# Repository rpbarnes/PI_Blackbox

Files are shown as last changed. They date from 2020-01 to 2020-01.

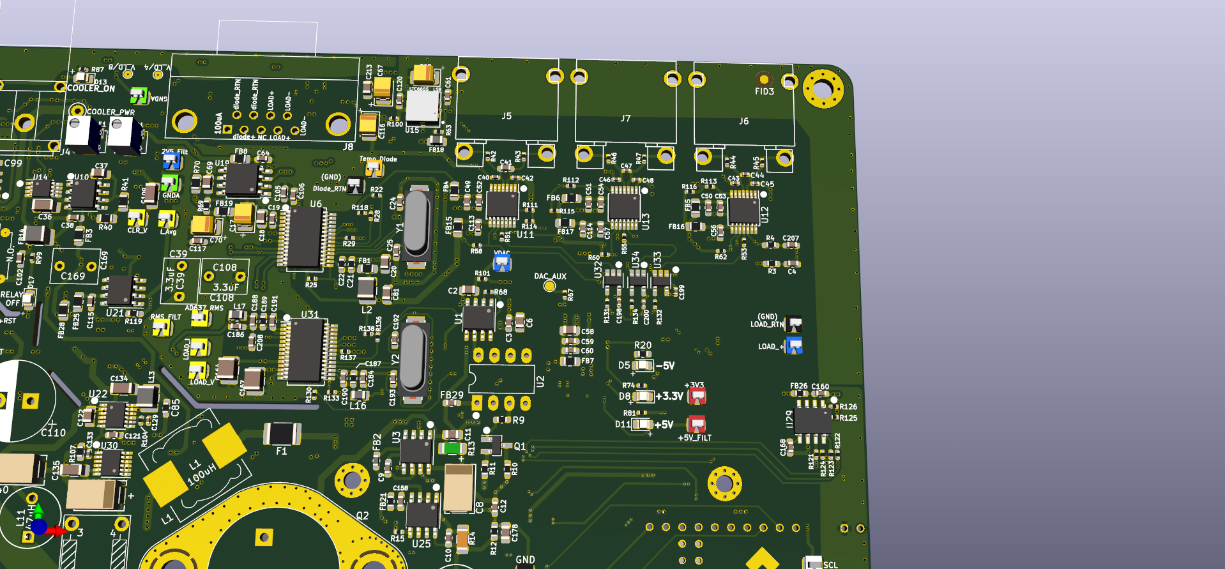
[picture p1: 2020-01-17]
PCB/FAB_Files/Assembled_Pics/top004.png

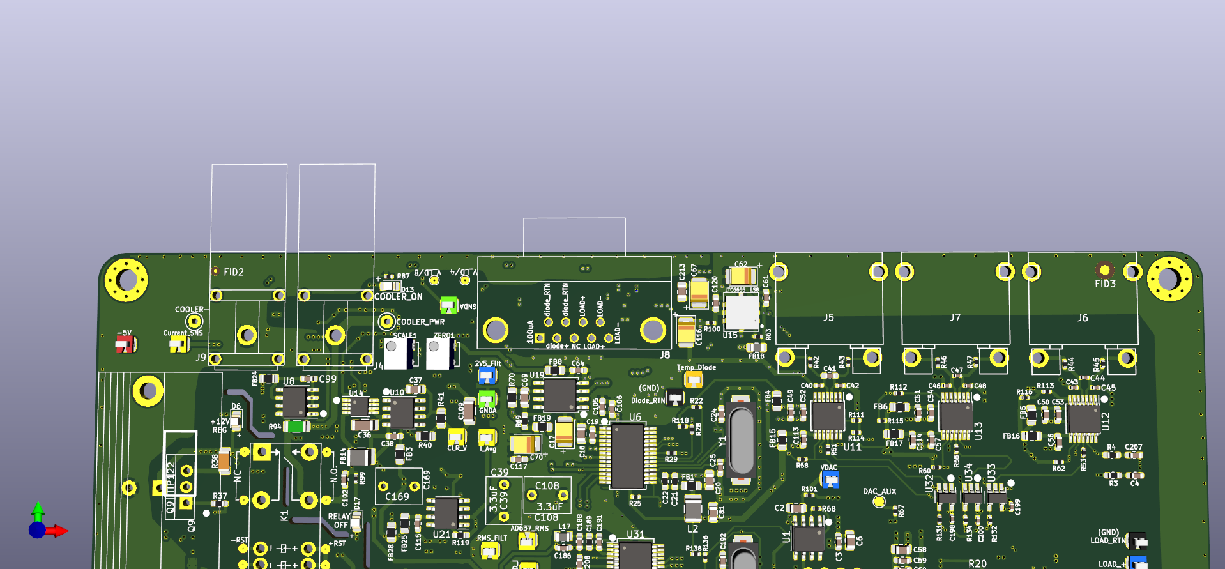
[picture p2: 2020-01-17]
PCB/FAB_Files/Assembled_Pics/top007.png

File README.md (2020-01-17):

# PI_Blackbox
Contains firmware for Raspberry Pi datalogging 
Some code I've written so far.... (not necessarily to be used in final project, but this is a good repository for sharing working code)
  - `GUI/`
      contains bare bones code for C/GTK based GUI to display on HDMI screen

  - `InfluxDB/`
      working code to store metrics to remote database

  - `PI_Firmware/`
      code that runs on PI_DAQ board that synchronously takes data samples
      
  - `Sockets/`
      sample code for sending text packets between two computers over socket connection
      
  - `Recipe/`
      crude version to run stepped loads over defined time intervals on the PI_DAQ
      
  - `PCB/`
      PCB Fabrication files and Kicad project files. Some of Kicad libraries used might not be present here

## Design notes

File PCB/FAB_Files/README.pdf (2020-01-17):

BOARD PACKAGE DOCUMENTS

FOLDERS:

Assembled_Pics/
3D renders of what assembled, finished board should appear as

Assembly_Drawings/
Location of components on top and bottom of board. Drawings include both top and bottom of board, and identified by reference designator and component value

BOM/
Bill of Materials of components to be installed on board. Two BOMs, one is sorted by reference designator, one is by component to aid in purchasing

DrillFiles/
Plated and non plated holes in separate files

Gerbers/
F.Cu | Top copper
In1.Cu | Inner copper layer #1
In2.Cu | Inner copper layer #2
In3.Cu | Inner copper layer #3
In4.Cu | Inner copper layer #4
B.Cu | Bottom copper
B.Adhes | Bottom Adhesive for SMD components
F.Paste | Top solder paste stencil
B.Paste | Bottom solder paste stencil
F.SilkS | Top silk screen
B.SilkS | Bottom silk screen
F.Mask | Top solder mask
B.Mask | Bottom solder mask
Edge Cuts | Board outline milling

Pick-n-Place_Files/
component position files, top and bottom of board

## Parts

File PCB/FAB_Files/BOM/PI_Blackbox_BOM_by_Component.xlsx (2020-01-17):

Description | Manufacturer | Digikey PN | MFR PN | Price EA | QTY | Reference Designators Populated Into
50V Ceramic .1uF X7R 0603 | Samsung | 1276-1000-1-ND |  | 0.1 | 57 | C3 | C5 | C9 | C10 | C11 | C12 | C14 | C19 | C21 | C22 | C38 | C41 | C52 | C53 | C54 | C56 | C57 | C59 | C61 | C64 | C68 | C72 | C77 | C78 | C83 | C85 | C90 | C99 | C102 | C105 | C106 | C115 | C117 | C120 | C157 | C158 | C160 | C166 | C168 | C171 | C172 | C173 | C183 | C186 | C188 | C190 | C191 | C194 | C195 | C196
CAP CER 1UF 25V X7R 0805 | Kemet | 399-8004-1-ND |  | 0.15 | 33 | C6 | C7 | C15 | C18 | C20 | C49 | C50 | C51 | C55 | C58 | C66 | C69 | C73 | C81 | C88 | C89 | C103 | C104 | C112 | C113 | C114 | C118 | C119 | C121 | C128 | C141 | C143 | C149 | C174 | C175 | C176 | C178 | C179
CAP TANT 47UF 10% 35V 2917 T495X | Kemet | 399-3905-1-ND | T495X476K035ATE300 | 2.41 | 12 | C8 | C71 | C87 | C95 | C126 | C131 | C136 | C140 | C148 | C151 | C152 | C156
1uF Film 16VDC | Cornell Dubilier | 338-2778-1-ND | FCA1210C105M-G2 | 0.94 | 9 | C13 | C91 | C96 | C97 | C159 | C163 | C164 | C167 | C170
CAP CER 1000PF 16V X7R 0402 | Kemet | 399-1032-1-ND | C0402C102K5RACTU | 0.1 | 3 | C16 | C35 | C177
CAP TANT 4.7UF 10% 35V 1411 | Kemet | 399-10431-1-ND | T491B475K035AT | 0.95 | 7 | C17 | C62 | C67 | C70 | C116 | C180 | C181
CAP CER 1UF 25V X7R 0603 | Kemet | 399-7376-1-ND | C0603C105K3RACTU | 0.3 | 8 | C23 | C98 | C161 | C182 | C184 | C187 | C189 | C208
20pF, 50V, C0G | Murata | 490-1410-1-ND | GRM1885C1H200JA01D | 0.1 | 4 | C24 | C25 | C192 | C193
CAP CER 10UF 50V X7R 1206 | Samsung | 1276-6767-1-ND | CL31B106KBHNNNE | 0.4 | 30 | C29 | C34 | C36 | C74 | C75 | C76 | C84 | C92 | C93 | C100 | C101 | C107 | C109 | C123 | C124 | C125 | C127 | C130 | C132 | C134 | C135 | C138 | C142 | C144 | C145 | C146 | C153 | C154 | C212 | C214
CAP CER 10UF 16V X7R 0805 | Samsung | 1276-6472-1-ND | CL21B106KOQNNNG | 0.3 | 8 | C37 | C111 | C122 | C165 | C209 | C210 | C211 | C213
CAP FILM 1UF 10% 63VDC RADIAL | Kemet | 399-11451-1-ND | MMK5105K63J04L16.5TR18 | 0.95 | 1 | C30
CAP POLY 6000UF 35V T/H | United Chemi Con | 565-4353-ND | ELBK350ELL602AMN3S | 3.93 | 2 | C31 | C32
0603 .01UF 10% 50V X7R | Kemet | 399-C0603C103K5RAC7081CT-ND | C0603C103K5RAC7081 | 0.11 | 4 | C33 | C60 | C63 | C65
CAP FILM 3.3UF 20% 50VDC RAD | WIMA | 1928-1627-ND | MKS2B043301H00MSSD | 1.15 | 3 | C39 | C108 | C169
CAP ALUM 1000UF 20% 35V RADIAL | Panasonic | P15382CT-ND | EEU-FR1V102B | 1.03 | 3 | C94 | C110 | C147
CAP CER 10000PF 50V X7R 0402 | Kemet | 399-7760-1-ND | C0402C103M5RACTU | 0.1 | 6 | C40 | C42 | C43 | C45 | C46 | C48
CAP CER 0.47UF 10V X7R 0402 | Taiyo Tuden | 587-5912-1-ND | LMK105B7474KV-F | 0.25 | 2 | C129 | C133
CAP CER 100UF 16V X5R 1210 | Kemet | 399-11270-1-ND | C1210C107M4PAC7800 | 3.23 | 2 | C139 | C150
CAP CER 0.1UF 25V X7R 0402 | Murata | 490-13341-1-ND | GRM155R71E104ME14D | 0.1 | 6 | C44 | C47 | C162 | C198 | C199 | C200
DIODE SCHOTTKY 40V 1A SOD123 | Diodes Incorporated | 1N5819HW-FDICT-ND | 1N5819HW-7-F | 0.44 | 2 | D1 | D3
TVS DIODE 18V 29.2V DO214AB | Littelfuse | SMDJ18CACT-ND | SMDJ18CA | 1.17 | 1 | D2
DIODE GEN PURP 100V 300MA SOD123 | Diodes Incorporated | 1N4148W-FDICT-ND | 1N4148W-7-F | 0.16 | 2 | D4 | D12
LED GREEN CLEAR SMD | Litte-On | 160-1426-1-ND | LTST-C171KGKT | 0.29 | 6 | D5 | D8 | D10 | D11 | D13 | D16
LED YELLOW CLEAR SMD | Litte-On | 160-1416-1-ND | LTST-C170KSKT | 0.33 | 2 | D6 | D9
LED ORANGE CLEAR SMD | Lite-On | 160-1419-1-ND | LTST-C171AKT | 0.31 | 1 | D14
LED RED CLEAR SMD | Lite-On | 160-1427-1-ND | LTST-C171KRKT | 0.29 | 1 | D17
HEATSINK 18X50MM 2-CLIP TO-220 | Wakefield-Vette | 345-1491-ND | OMNI-220-18-50-2C | 7.43 | 1 | HS1
CAP CER 0.1UF 50V Z5U 1206 | Kemet | 399-1258-1-ND | C1206C104Z5UACTU | 0.19 | 2 | C26 | C155
CAP CER 0.1UF 25V X7R 0805 | Kemet | 399-8000-1-ND | C0805C104M3RACTU | 0.1 | 2 | C79 | C185
FIXED IND 10UH 850MA 300 MOHM | Wurth | 732-4516-1-ND | 74479887310A | 1.2 | 5 | L1 | L2 | L7 | L9 | L13
TRANS NPN 40V 0.6A SOT23 | Micro Commercial | MMBT2222ATPMSCT-ND | MMBT2222A-TP | 0.1 | 3 | Q1 | Q4 | Q7
FIXED IND 10UH 500MA 300 MOHM | TDK | 445-6762-1-ND | MLZ2012N100LT000 | 0.14 | 2 | L16 | L17
PC TEST POINT, WHITE, SMT | Keystone | 36-5192CT-ND | 5192TR | 0.44 | 9 | TP3 | TP5 | TP6 | TP7 | TP8 | TP9 | TP10 | TP12 | TP50
PC TEST POINT, BLACK, SMT | Keystone | 36-5191CT-ND | 5191TR | 0.44 | 5 | TP11 | TP32 | TP38 | TP40 | TP43
PC TEST POINT, PURPLE, SMT | Keystone | 36-5199CT-ND | 5199TR | 0.44 | 3 | TP4 | TP14 | TP15
PC TEST POINT, YELLOW, SMT | Keystone | 36-5194CT-ND | 5194TR | 0.44 | 7 | TP17 | TP18 | TP22 | TP31 | TP45 | TP46 | TP47
PC TEST POINT, RED, SMT | Keystone | 36-5190CT-ND | 5190TR | 0.44 | 7 | TP16 | TP19 | TP27 | TP28 | TP29 | TP35 | TP44
PC TEST POINT, BLUE, SMT | Keystone | 36-5197CT-ND | 5197TR | 0.44 | 3 | TP13 | TP23 | TP24
PC TEST POINT, GREEN, SMT | Keystone | 36-5196CT-ND | 5196TR | 0.44 | 2 | TP26 | TP48
PC TEST POINT, ORANGE, SMT | Keystone | 36-5193CT-ND | 5193TR | 0.44 | 1 | TP33
CAP CER 10000PF 50V X7R 1206 | Yageo | 311-1174-1-ND | CC1206KRX7R9BB103 | 0.24 | 1 | C27
CAP ALUM 560UF 20% 35V RADIAL | Nichicon | 493-15313-ND |  | 0.74 | 2 | C28 | C137
FIXED IND 10UH 500MA | TDK | 445-6762-1-ND | MLZ2012N100LT000 | 0.14 | 19 | FB1 | FB3 | FB4 | FB5 | FB6 | FB7 | FB8 | FB9 | FB12 | FB15 | FB16 | FB17 | FB18 | FB19 | FB20 | FB24 | FB25 | FB28 | FB30
FIXED IND 22UH 230MA | Taiyo Yuden | 587-1721-1-ND | CBMF1608T220K | 0.27 | 9 | FB2 | FB11 | FB21 | FB22 | FB23 | FB26 | FB27 | FB29 | FB31
FERRITE BEAD 1 KOHM 1210 1LN | Taiyo Yuden | 587-1753-1-ND | FBMH3225HM102NT | 0.44 | 4 | FB10 | FB13 | FB14 | FB32
FIXED IND 2.2UH 30MA | TDK | 445-15690-1-ND | MLF1005G2R2KT000 | 0.28 | 3 | FB33 | FB34 | FB35
CAP CER 12PF 50V C0G/NP0 0603 | Kemet | 399-1050-1-ND | C0603C120J5GACTU | 0.1 | 1 | C80
CAP CER 3000PF 50V C0G/NP0 0603 | Murata | 490-6384-1-ND | GRM1885C1H302JA01D | 0.19 | 1 | C82
CAP CER 680PF 250V C0G/NP0 0603 | Kemet | 399-14994-1-ND | C0603C681JAGAC7867 | 0.11 | 1 | C86
DIODE SCHOTTKY 40V 3A SMA | ON Semiconductor | MBRA340T3GOSCT-ND | MBRA340T3G | 0.48 | 1 | D7
PTC .15A |  | 507-1755-1-ND |  | 0.14 | 1 | F1
PTC RESET FUSE 24V 2A 2920 | Bel Fuse | 507-1749-1-ND | 0ZCF0200AF2C | 0.29 | 2 | F2 | F3
CONN HEADER SMD R/A 2POS 3MM | TE Connectivity | A33212CT-ND |  | 0.99 | 1 | J3
FILTER LC 1UF SMD | Murata | 490-5052-1-ND | BNX022-01L | 6.04 | 1 | L3
TRANS 2PNP 65V 0.1A 6TSOP | Nexperia | 1727-5391-1-ND | BCM856DS | 0.43 | 1 | Q3
MOSFET N/P-CH 30V TSOT23-6 | Diodes Incorporated | DMG6602SVT-7DICT-ND | DMG6602SVT-7 | 0.37 | 1 | Q5
MOSFET P-CH 12V 4.3A SOT-23 | Infineon | IRLML6401PBFCT-ND | IRLML6401TRPBF | 0.37 | 1 | Q6
10K OHM 0.5% 1/16W 0402 | Susumu | RR05P10.0KDCT-ND | RR0510P-103-D | 0.1 | 15 | R5 | R6 | R7 | R25 | R60 | R62 | R64 | R100 | R105 | R110 | R114 | R115 | R116 | R125 | R126
2K OHM 1% 1/16W 0402 100ppm/C | Yageo | 311-2KLRCT-ND | RC0402FR-072KL | 0.1 | 8 | R22 | R31 | R34 | R118 | R123 | R124 | R130 | R138
100 OHM 1% 1/16W 0402 | Yageo | 311-100LRCT-ND | RC0402FR-07100RL | 0.1 | 14 | R1 | R2 | R8 | R17 | R42 | R43 | R44 | R45 | R46 | R47 | R50 | R52 | R68 | R148
10K OHM 0.5% 1/16W 0402 | Susumu | RR05P10.0KDCT-ND | RR0510P-103-D | 0.1 | 18 | R5 | R6 | R7 | R25 | R58 | R60 | R62 | R64 | R100 | R105 | R110 | R114 | R115 | R116 | R125 | R126 | R133 | R147
1K OHM 1% 1/16W 0402 100ppm/C | Yageo | 311-1.00KLRCT-ND | RC0402FR-071KL | 0.1 | 11 | R15 | R16 | R18 | R35 | R39 | R63 | R72 | R81 | R87 | R98 | R99
RES 47 OHM 5% 1/16W 0402 100ppm/C | Stackpole | RMCF0402JT47R0CT-ND | RMCF0402JT47R0 | 0.1 | 29 | R48 | R49 | R51 | R53 | R54 | R55 | R56 | R57 | R59 | R61 | R65 | R66 | R111 | R112 | R113 | R131 | R132 | R134 | R135 | R136 | R137 | R139 | R140 | R141 | R142 | R143 | R144 | R145 | R146
49.9KOHM 0.5% 1/16W 0603 | Susumu | RR08P49.9KDCT-ND | RR0816P-4992-D-68C | 0.11 | 3 | R30 | R32 | R33
20K OHM 0.5% 1/16W 0603 | Susumu | RR08P20.0KDCT-ND | RR0816P-203-D | 0.11 | 2 | R12 | R75
100 OHM 0.5% 1/16W 0603 | Susumu | RR08P100DCT-ND | RR0816P-101-D | 0.11 | 4 | R36 | R37 | R83 | R119
499 OHM 1% 1/10W 0402 100ppm/C | Panasonic | P499LCT-ND | ERJ-2RKF4990X | 0.1 | 3 | R80 | R85 | R86
22 OHM 1% 1/16W 0402 | Yageo | 311-22.0LRCT-ND | RC0402FR-0722RL | 0.1 | 4 | R89 | R91 | R121 | R122
49.9 OHM 1% 1/10W 0402 100ppm/C | Panasonic | P49.9LCT-ND | ERJ-2RKF49R9X | 0.1 | 2 | R67 | R101
RES 0.5 OHM 1% 1/2W 1206 | Vishay Dale | 541-4389-1-ND | RCWE1206R500FKEA | 0.61 | 2 | R38 | R84
300 OHM 0.5% 1/16W 0402 | Susumu | RR05P300DCT-ND | RR0510P-301-D | 0.1 | 2 | R74 | R93
47K OHM 1% 1/10W 0603 | Yageo | 311-47.0KHRCT-ND | RC0603FR-0747KL | 0.1 | 2 | R96 | R97
1M OHM 0.1% 1/10W 0603 25ppm/C | Yageo | YAG4498CT-ND | RT0603BRD071ML | 0.35 | 2 | R106 | R120
200 OHM 1% 1/10W 0603 100ppm/C | Panasonic | P200HCT-ND | ERJ-3EKF2000V | 0.1 | 1 | R9
1K OHM 0.5% 1/16W 0603 | Yageo | RR08P1.0KDCT-ND | RR0816P-102-D | 0.11 | 1 | R10
49.9 OHM 1% 1/10W 0603 | Yageo | 311-49.9HRCT-ND | RC0603FR-0749R9L | 0.1 | 1 | R11
RES SMD 1 OHM 1% 1/2W 1206 | Susumu | RL16R1.0FCT-ND | RL1632R-1R00-F | 0.68 | 1 | R13
0.39 OHM 1% 1/2W 1206 | Vishay Dale | RCWE.39ECT-ND | RCWE1206R390FKEA | 0.61 | 1 | R14
300 OHM 0.5% 1/16W 0603 | Susumu | RR08P300DCT-ND | RR0816P-301-D | 0.11 | 1 | R19
2.2K OHM 0.5% 1/10W 0805 | Susumu | RR12P2.2KDCT-ND | RR1220P-222-D | 0.11 | 1 | R40
200 OHM 0.5% 1/10W 0805 | Susumu | RR12P200DCT-ND | RR1220P-201-D | 0.11 | 1 | R41
10K OHM 1% 1/10W 0603 | Yageo | 311-10.0KHRCT-ND | RC0603FR-0710KL | 0.1 | 1 | R69
RES 20 OHM 5% 1/8W 0805 | Stackpole | RMCF0805JT20R0CT-ND | RMCF0805JT20R0 | 0.1 | 1 | R70
215K OHM 0.1% 1/10W 0603 | Panasonic | P215KDBCT-ND | ERA-3AEB2153V | 0.35 | 1 | R71
36K OHM 0.5% 1/16W 0603 | Susumu | RR08P36.0KDCT-ND | RR0816P-363-D | 0.11 | 1 | R73
2.2K OHM 1% 1/10W 0603 | Yageo | 311-2.20KHRCT-ND | RC0603FR-072K2L | 0.1 | 1 | R76
71.5KOHM 0.1% 1/10W 0603 | Panasonic | P71.5KDBCT-ND | ERA-3AEB7152V | 0.35 | 1 | R77
11K OHM 0.1% 1/10W 0603 | Panasonic | P11KDBCT-ND | ERA-3AEB113V | 0.35 | 1 | R78
750 OHM 0.5% 1/16W 0402 25ppm/C | Susumu | RR05P750DCT-ND | RR0510P-751-D | 0.1 | 1 | R79
750 OHM 0.5% 1/16W 0603 | Susumu | RR08P750DCT-ND | RR0816P-751-D | 0.1 | 1 | R82
THICK FILM RESISTOR | KOA | 2019-RK73H2ETTD20R0FCT-ND | RK73H2ETTD20R0F | 0.2 | 1 | R88
220K OHM 0.1% 1/10W 0603 | Panasonic | P220KDBCT-ND | ERA-3AEB224V | 0.35 | 1 | R90
11.5KOHM 0.1% 1/10W 0603 | Panasonic | P11.5KDBCT-ND | ERA-3AEB1152V | 0.35 | 1 | R92
RES 0.056 OHM 1% 3/4W 1206 | Susumu | 408-1579-1-ND | KRL1632E-M-R056-F-T5 | 0.54 | 1 | R94
2.2K OHM 1% 1/16W 0402 100ppm/C | Yageo | 311-2.20KLRCT-ND | RC0402FR-072K2L | 0.1 | 1 | R95
RES 0.2 OHM 1% 1/2W 1206 | Susumu | RL16R.20FCT-ND | RL1632R-R200-F | 0.65 | 1 | R102
RES SMD 1.5 OHM 1% 1/2W 1206 | Susumu | RL16R1.5FCT-ND | RL1632R-1R50-F | 0.68 | 1 | R103
33.2KOHM 0.1% 1/16W 0402 25ppm/C | Panasonic | P33.2KDCCT-ND | ERA-2AEB3322X | 0.45 | 1 | R104
51K OHM 0.1% 1/10W 0603 | Panasonic | P51KDBCT-ND | ERA-3AEB513V | 0.35 | 1 | R107
4.7K OHM 5% 1/16W 0402 | Yageo | 311-4.7KJRCT-ND | RC0402JR-074K7L | 0.1 | 1 | R108
RES SMD 47 OHM 1% 1/2W 1206 | TE Connectivity | A129227CT-ND | CRGH1206F47R | 0.16 | 1 | R109
1.87KOHM 0.1% 1/10W 0603 | Panasonic | P1.87KDBCT-ND | ERA-3AEB1871V | 0.35 | 1 | R117
47 OHM 0.5% 1/16W 0603 | Susumu | RR08Q47DCT-ND | RR0816Q-470-D | 0.11 | 1 | R127
RES SMD 4.99 OHM 1% 1/8W 0805 | Yageo | 311-4.99CRCT-ND | RC0805FR-074R99L | 0.1 | 1 | R128
RES 0.1 OHM 5% 1/10W 0603 | Panasonic | P.10AHCT-ND | ERJ-3RSJR10V | 0.25 | 1 | R129
TRIMMER 500 OHM 0.25W J LEAD TOP | Bourns | 3214W-501ECT-ND | 3214W-1-501E | 3.24 | 1 | SCALE1
TRIMMER 50K OHM 0.25W J LEAD TOP | Bourns | 3214W-503ECT-ND | 3214W-1-503E | 3.24 | 1 | ZERO1
IC BUF NON-INVERT 5.5V SOT23-5 | Texas Instruments |  | SN74AHC1G125DBVR | 0.32 | 3 | U32 | U33 | U34
IC BUFFER NON-INVERT 6V 14TSSOP | Texas Instruments | 296-26461-1-ND | SN74HC125PWR | 0.36 | 3 | U35 | U36 | U37
IC CONV THERMOCOUPLE 14TSSOP | Maxim Integrated | MAX31856MUD+-ND | MAX31856MUD+ | 6.45 | 3 | U11 | U12 | U13
IC OPAMP ZERO-DRIFT 1 CIRC 8SOIC | Analog Devices | AD8628ARZ-REEL7CT-ND | AD8628ARZ-REEL7 | 2.95 | 5 | U10 | U19 | U21 | U27 | U28
24 Bit Analog to Digital Converter 4, 8 Input 1 Sigma-Delta 28-SSOP | Texas Instruments | 296-25898-1-ND | ADS1256IDBR | 14.87 | 2 | U6 | U31
RES ARRAY 4 RES 10K OHM 8TSSOP | Analog Devices | LT5400BIMS8E-1#PBF-ND | LT5400BIMS8E-1#PBF | 9.31 | 2 | U5 | U14
IC REG LINEAR 0V 500MA 12MSOP | Analog Devices | LT3045EMSE#PBF-ND | LT3045EMSE#PBF | 6.78 | 2 | U22 | U30
IC CURR SENSE 1 CIRCUIT 8SOIC | Analog Devices | AD8417WBRZ-ND | AD8417WBRZ | 3.02 | 3 | U32 | U8 | U25
7.68MHz ±30ppm Crystal 18pF 80 Ohms HC- | TXC Corporation | 887-1047-1-ND | 9C-7.680MAAJ-T | 0.46 | 1 | Y1
IC OPAMP ZERO-DRIFT 1 CIRC 8SOIC | Analog Devices | LTC2057IS8#TRPBF | LTC2057IS8#TRPBFCT-ND | 2.99 | 1 | U1
IC OPAMP DIFF 1 CIRCUIT 8SOIC | Analog Devices | AD8278BRZ | AD8278BRZ-ND | 4 | 1 | U4
IC REG LIN POS ADJ 500MA 12MSOP | Analog Devices | LT3065IMSE#PBF | LT3065IMSE#PBF-ND | 5.1 | 1 | U7
IC CURR SOURCE/SINK MIRROR 8SOIC | Texas Instruments | REF200AU | 296-44855-5-ND | 8.91 | 1 | U9
IC VREF SERIES 0.05% 8CLCC | Analog Devices | LTC6655CHLS8-2.5#PBF | LTC6655CHLS8-2.5#PBF-ND | 11.65 | 1 | U15
IC DAC 16BIT V-OUT 8VSSOP | Texas Instruments | DAC8552IDGKR | 296-46082-1-ND | 7.25 | 1 | U16
IC ANALOG SWITCH 8MSOP | Vishay Siliconix | DG419LEDQ-T1-GE3 | DG419LEDQ-T1-GE3CT-ND | 1.36 | 1 | U17
IC REG BCK SPLIT RAIL ADJ 8SOPWR | Texas Instruments | TPS54360DDA | 296-35014-ND | 5.71 | 1 | U18
SENSOR DIGITAL -55C-150C 8SOIC | Analog Devices | ADT7410TRZ-REEL7 | ADT7410TRZ-REEL7CT-ND | 3.93 | 1 | U20
IC REG CHARGE PUMP INV 8SOIC | Analog Devices | LT1054LCS8#PBF | LT1054LCS8#PBF-ND | 4.85 | 1 | U23
IC RMS TO DC CONVERTER 16SOIC | Analog Devices | AD637JRZ | AD637JRZ-ND | 24.07 | 1 | U24
IC REG LIN POS ADJ 3A 8SO PWRPAD | Texas Instruments | TPS7A7002DDA | 296-39506-5-ND | 2.8 | 1 | U26
IC RTC CLK/CALENDAR I2C 8-SOIC | Maxim Integrated | DS3231MZ+ | DS3231MZ+-ND | 7.89 | 1 | U29
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

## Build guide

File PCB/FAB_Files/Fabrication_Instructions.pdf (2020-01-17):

FABRICATION INSTRUCTIONS

NOTE: ALL DIMENSIONS IN BOARD DOCUMENTS ARE IN MILLIMETERS

BOARD DIMENSIONS: | 125.776 MM x 175.236 MM
NUMBER OF LAYERS: | 6
1. MATERIAL: LAMINATED EPOXY GLASS FR-4, NOMINAL 1.6 MM, COLOR NATURAL NOM 2 OZ COPPER WEIGHT. THICKNESS 1.8 MM MAX AFTER PLATING
2. SOLDERMASK OVER BARE COPPER ON TOP AND BOTTOM WITH MATERIAL PER ANSI/ IPC-SM-840, COLOR SHALL BE GREEN
3. HOLES.
A. PLATING IN HOLES SHALL BE CONTINUOUS ELECTROLYTIC COPPER WITH .025 MM MINIMUM BARREL THICKNESS
B. MINIMUM HOLE SIZE: 0.2 MM
C. SEE DRILL CHART FOR FINISHED HOLE SIZE AND TOLERANCE
D. HOLE SIZES ARE SPECIFIED AS FINAL DIMENSIONS AFTER PLATING
4. SEE SEPARATE DRILL FILE FOR HOLE LOCATIONS
5. SURFACE FINISH. ENIG PLATING PER CURRENT REVISION OF IPC 4552
6. APPLY SILKSCREEN TO TOP AND BOTTOM SIDE OF BOARD WITH WHITE EPOXY, NON-CONDUCTIVE INK
7. DIMENSIONAL TOLERANCES ARE: .XX=+/- .01; .XXX=+/-.005
8. OUTLINE DEFINED IN SEPARATE GERBER FILE “Pi_Blackbox-Edge_Cuts.gbr”
9. NO CONTROLLED IMPEDANCE
10. DESIGN GEOMETRY MINIMUM FEATURE SIZES:
TRACE WIDTH; | 0.25 MM
TRACE-TO-TRACE; TRACE-TO-PAD | 0.19 MM
HOLE-TO-HOLE | 0.254 MM
PAD-TO-PAD | 0.19 MM
MIN HOLE SIZE | 0.2 MM

LAYER STACKUP

SOLDERMASK | Pi_Blackbox-F_Mask.gbr
SILKSCREEN | Pi_Blackbox-F_SilkS.gbr
TOP COPPER, 2 oz | Pi_Blackbox-F_Cu.gbr
DIELECTRIC
INNER COPPER LAYER #1, 1 oz | Pi_Blackbox-In1_Cu.gbr
DIELECTRIC
INNER COPPER LAYER #2 1 oz | Pi_Blackbox-In2_Cu.gbr
DIELECTRIC
INNER COPPER LAYER #3 1 oz | Pi_Blackbox-In3_Cu.gbr
DIELECTRIC
INNER COPPER LAYER #4 1 oz | Pi_Blackbox-In4_Cu.gbr
DIELECTRIC
BOTTOM COPPER 2 oz | Pi_Blackbox-B_Cu.gbr
SOLDER MASK | Pi_Blackbox-B_Mask.gbr
SILKSCREEN | Pi_Blackbox-B_SilkS.gbr

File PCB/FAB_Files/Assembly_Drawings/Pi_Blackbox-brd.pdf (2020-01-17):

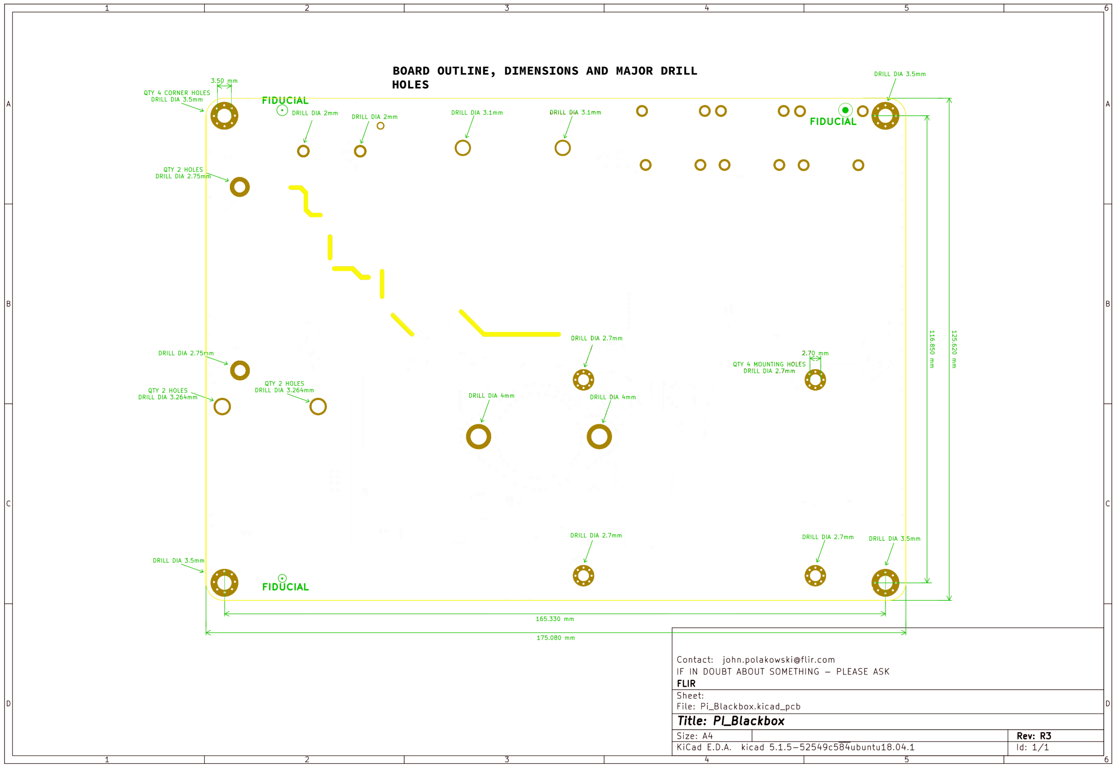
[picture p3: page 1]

BOARD OUTLINE, DIMENSIONS AND MAJOR DRILL HOLES

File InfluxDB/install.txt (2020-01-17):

wget -qO- https://repos.influxdata.com/influxdb.key | sudo tee /etc/apt/sources.list.d/influxdb.list test $VERSION_ID = "8" && echo "deb https://repos.influxdata.com/debian jessie stable" | sudo tee /etc/apt/sources.list.d/influxdb.list test $VERSION_ID = "9" && echo "deb https://repos.influxdata.com/debian stretch stable" | sudo tee /etc/apt/sources.list.d/influxdb.list 

sudo apt-get update && sudo apt-get install influxdb 
sudo service influxdb start 

#verify influxdb is running with the following command. 
sudo service influxdb status

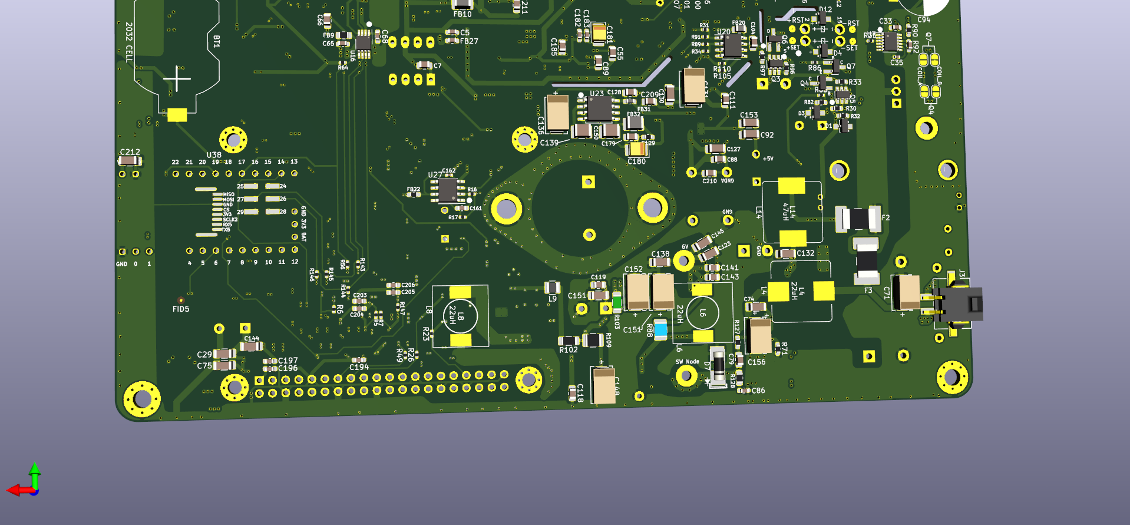
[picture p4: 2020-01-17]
PCB/FAB_Files/Assembled_Pics/bottom006.png

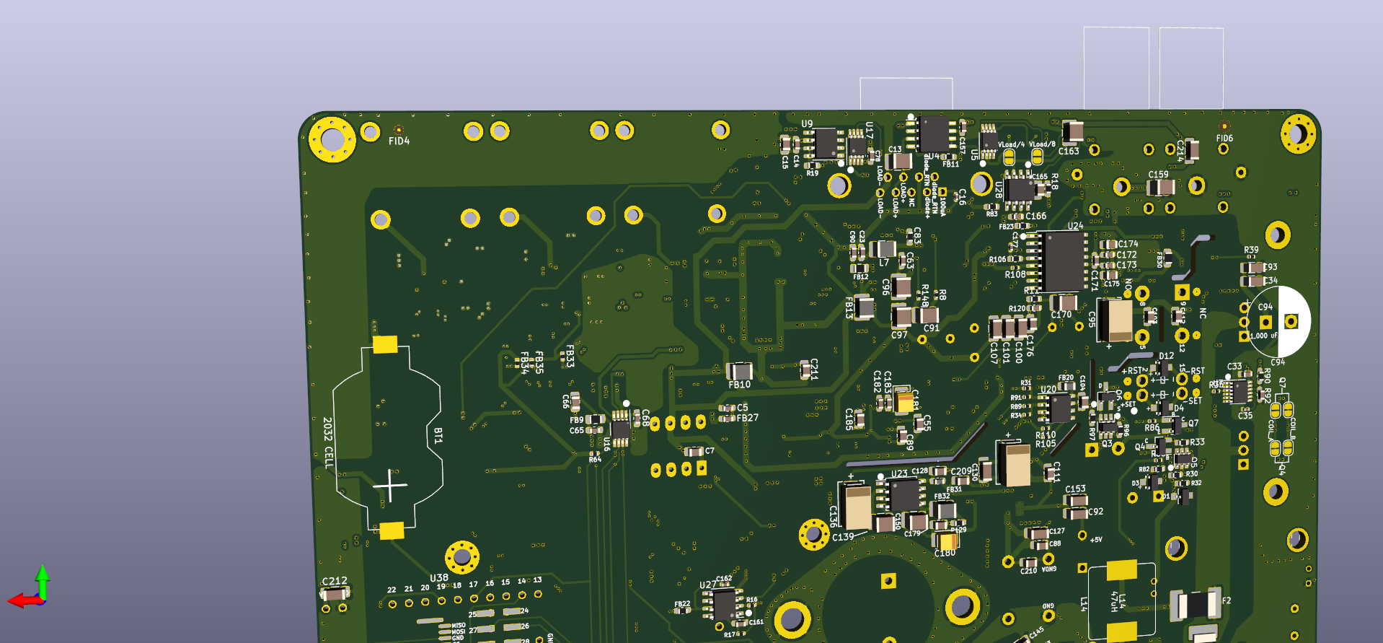
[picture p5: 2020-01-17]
PCB/FAB_Files/Assembled_Pics/bottom005.png

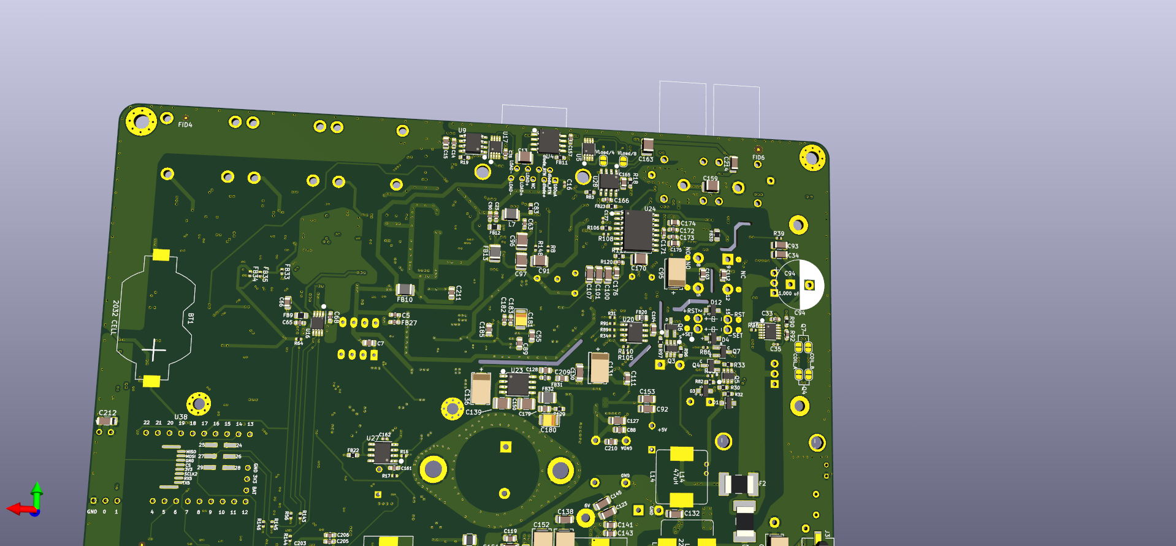
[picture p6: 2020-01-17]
PCB/FAB_Files/Assembled_Pics/bottom004.png

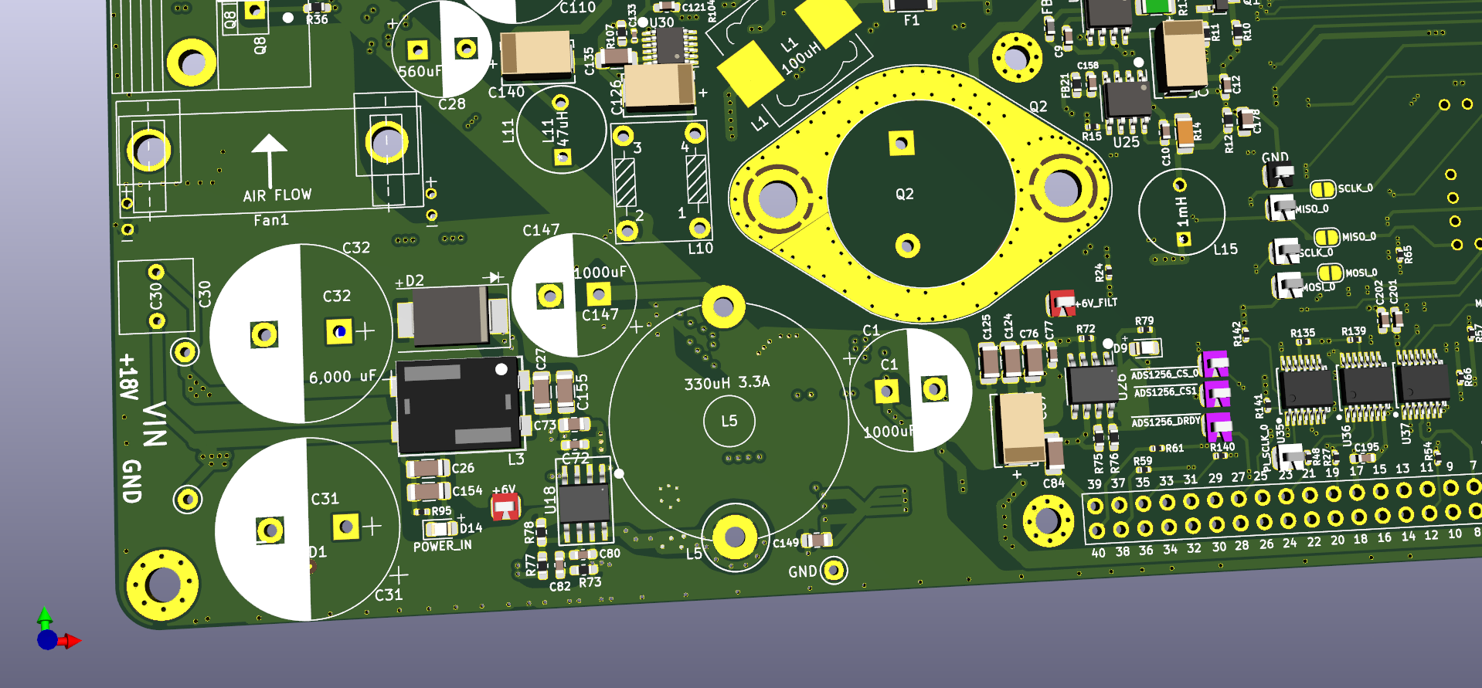
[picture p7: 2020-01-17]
PCB/FAB_Files/Assembled_Pics/top002.png

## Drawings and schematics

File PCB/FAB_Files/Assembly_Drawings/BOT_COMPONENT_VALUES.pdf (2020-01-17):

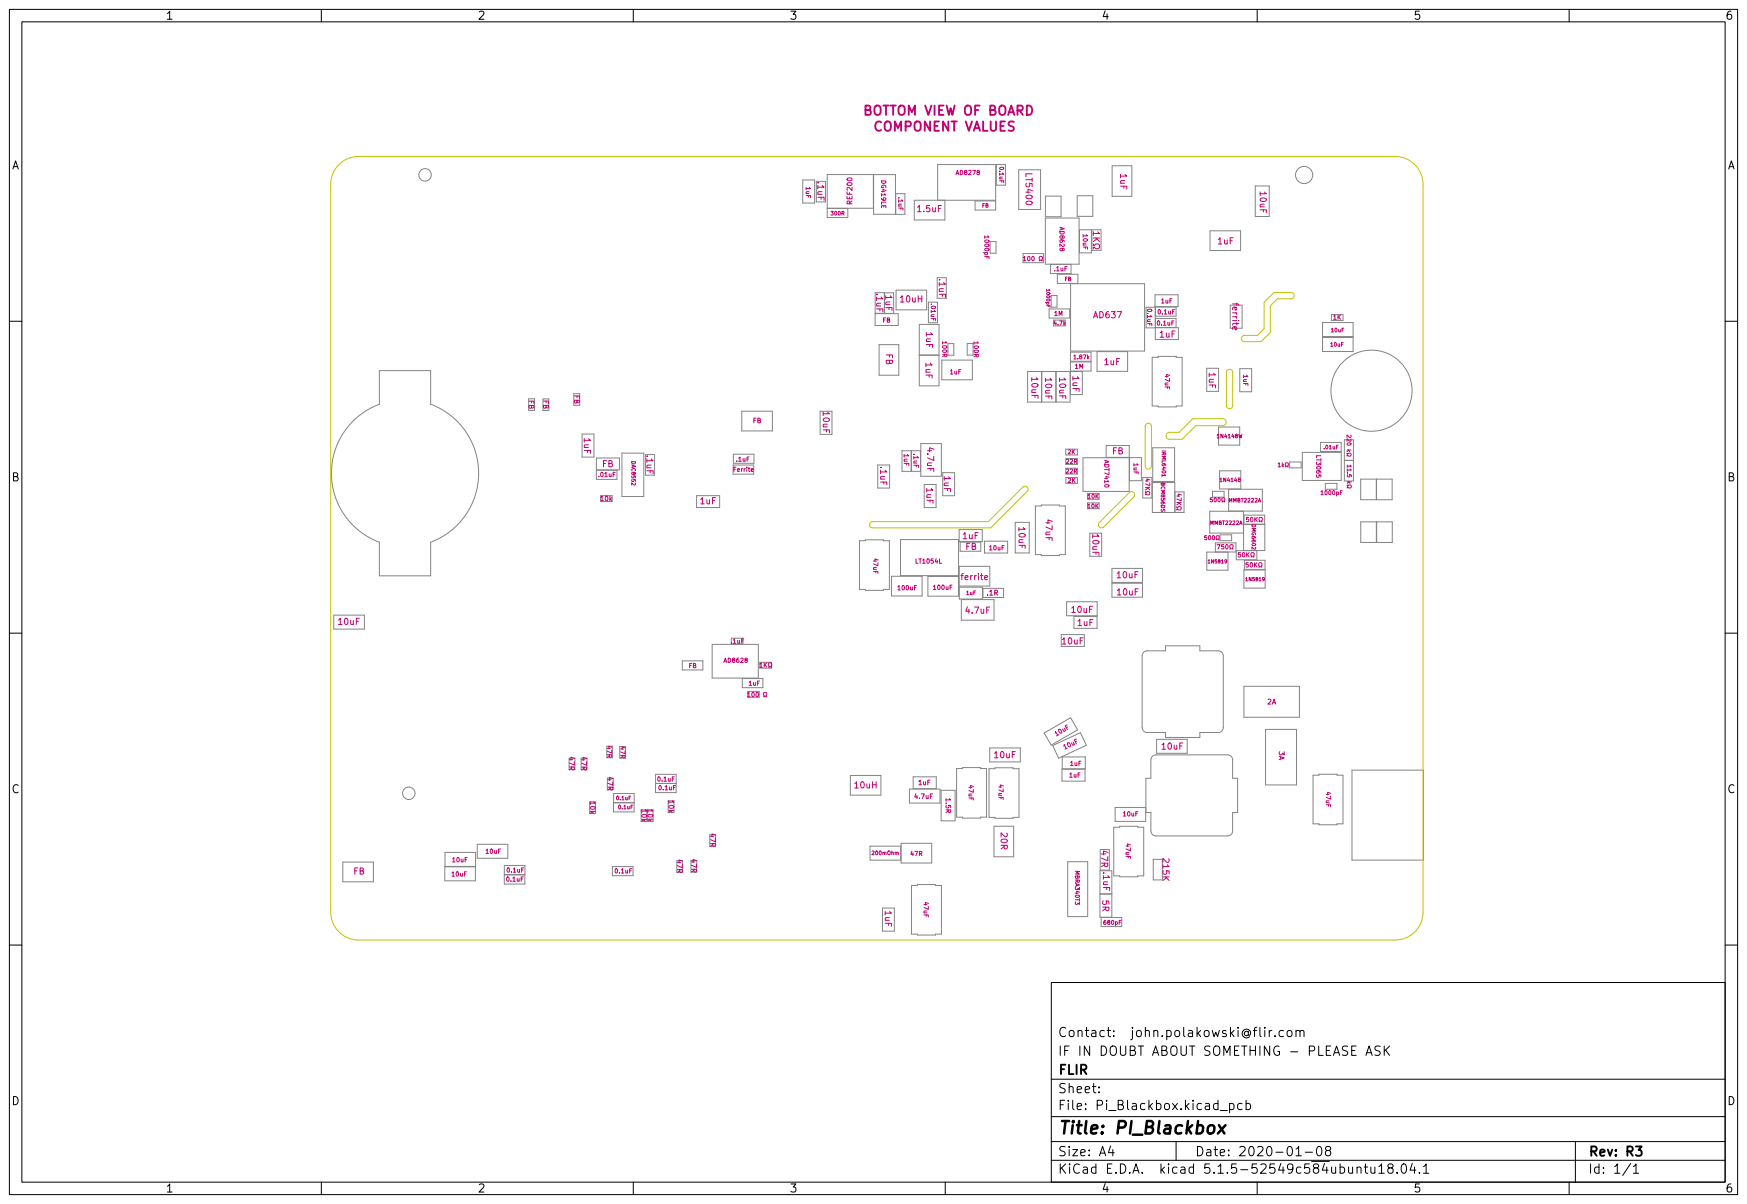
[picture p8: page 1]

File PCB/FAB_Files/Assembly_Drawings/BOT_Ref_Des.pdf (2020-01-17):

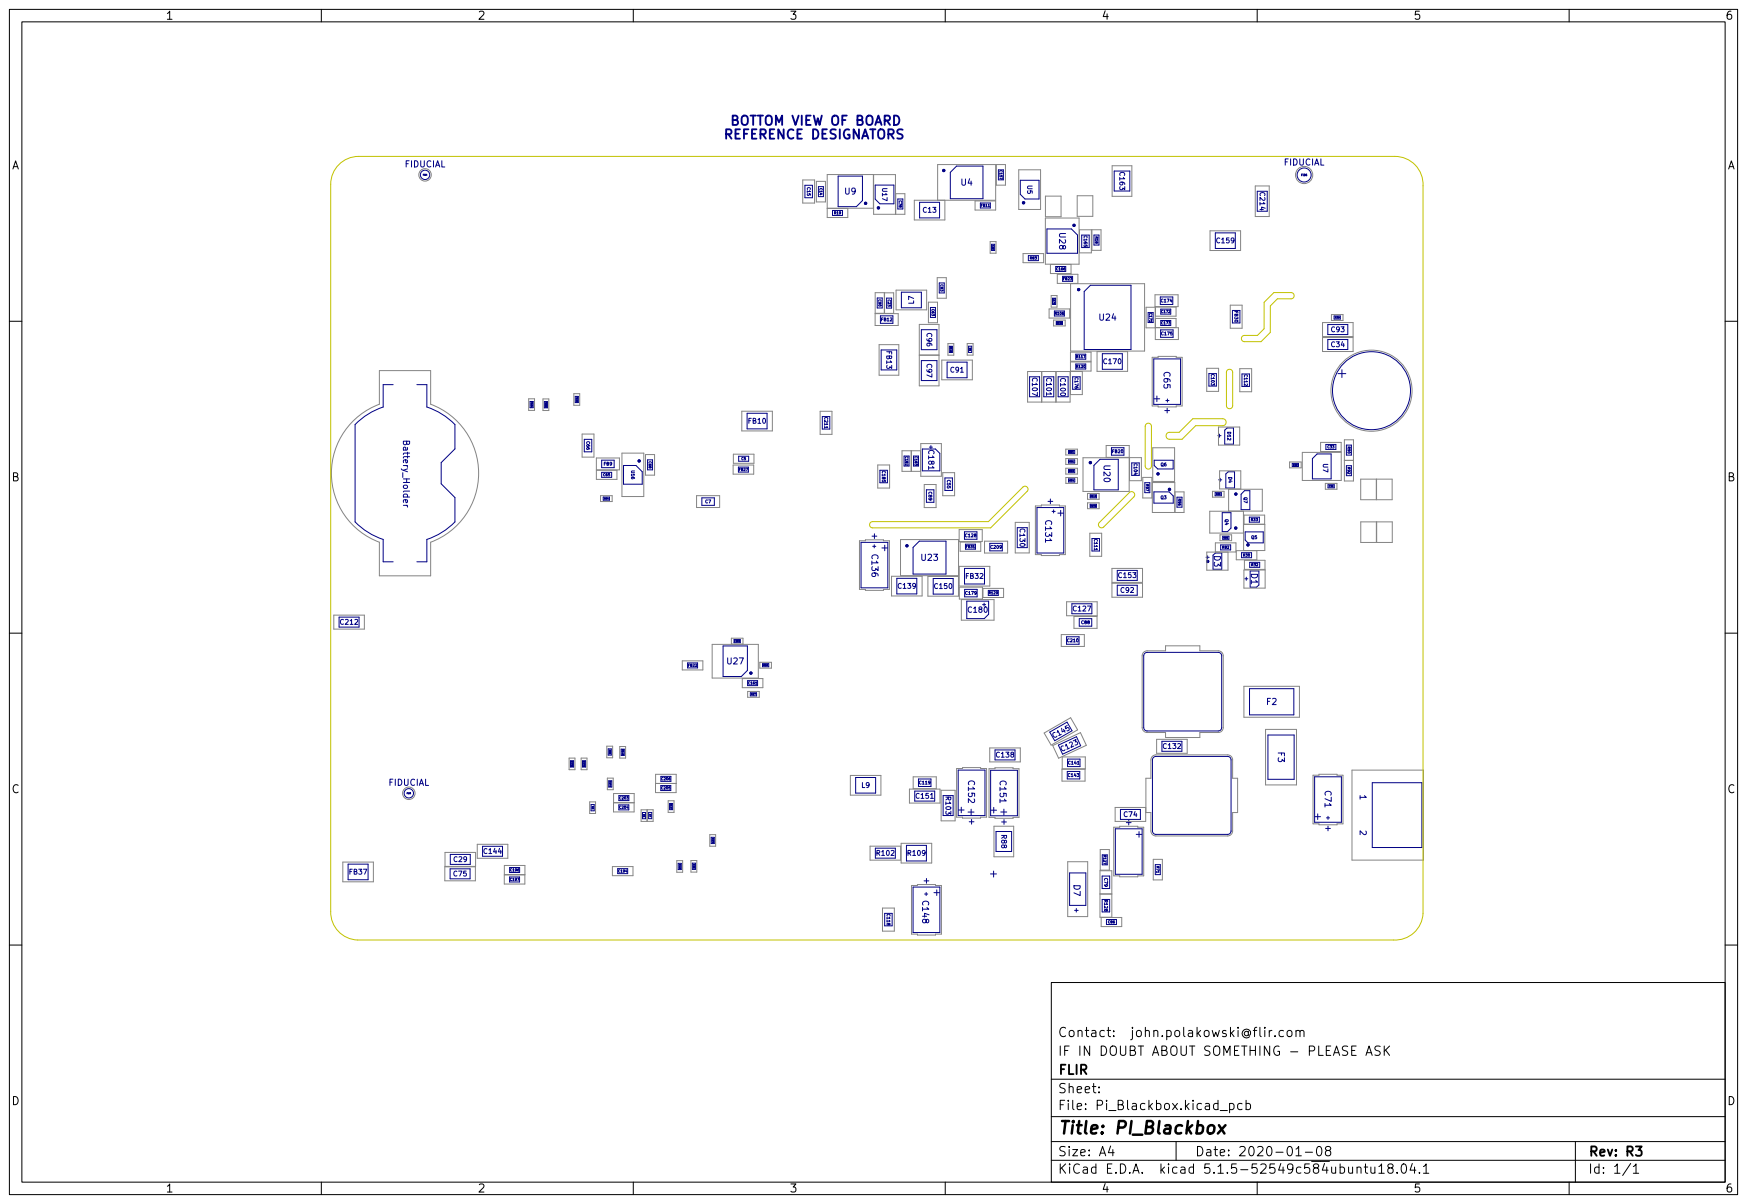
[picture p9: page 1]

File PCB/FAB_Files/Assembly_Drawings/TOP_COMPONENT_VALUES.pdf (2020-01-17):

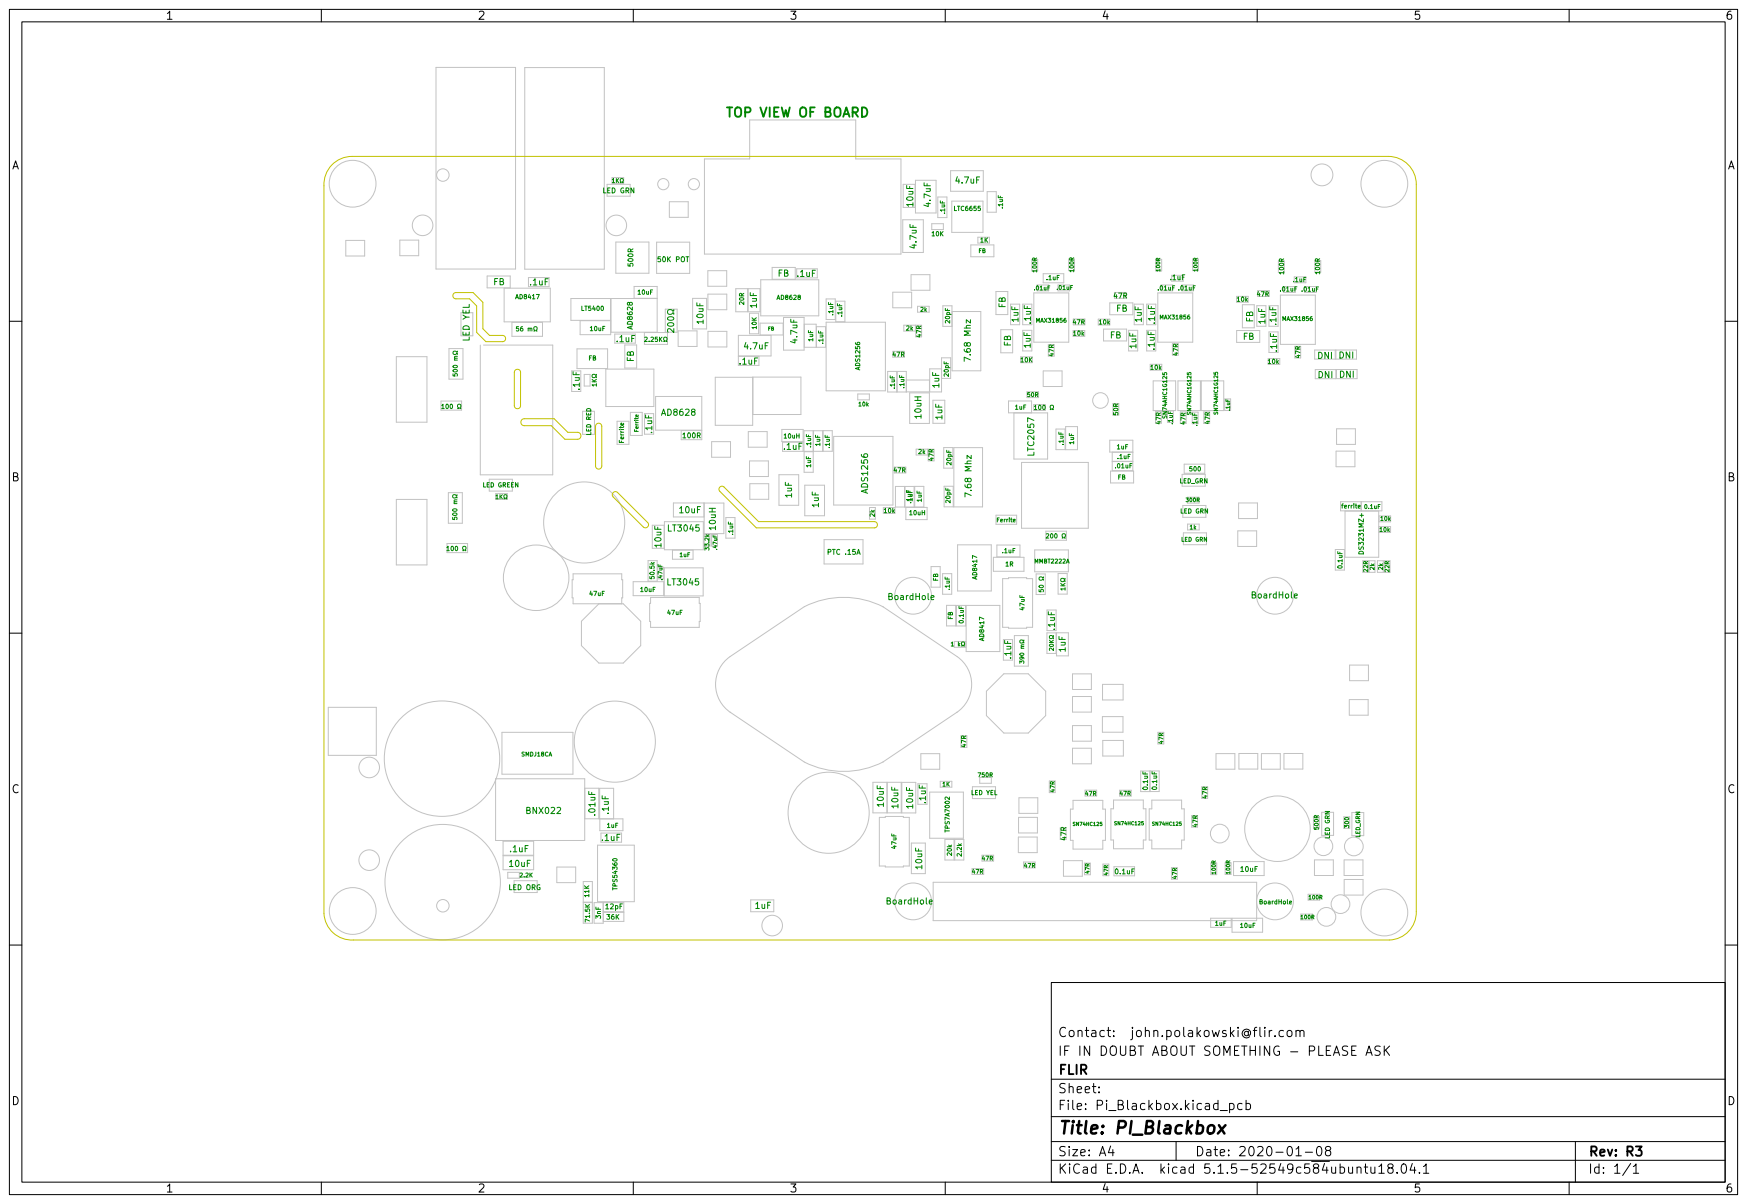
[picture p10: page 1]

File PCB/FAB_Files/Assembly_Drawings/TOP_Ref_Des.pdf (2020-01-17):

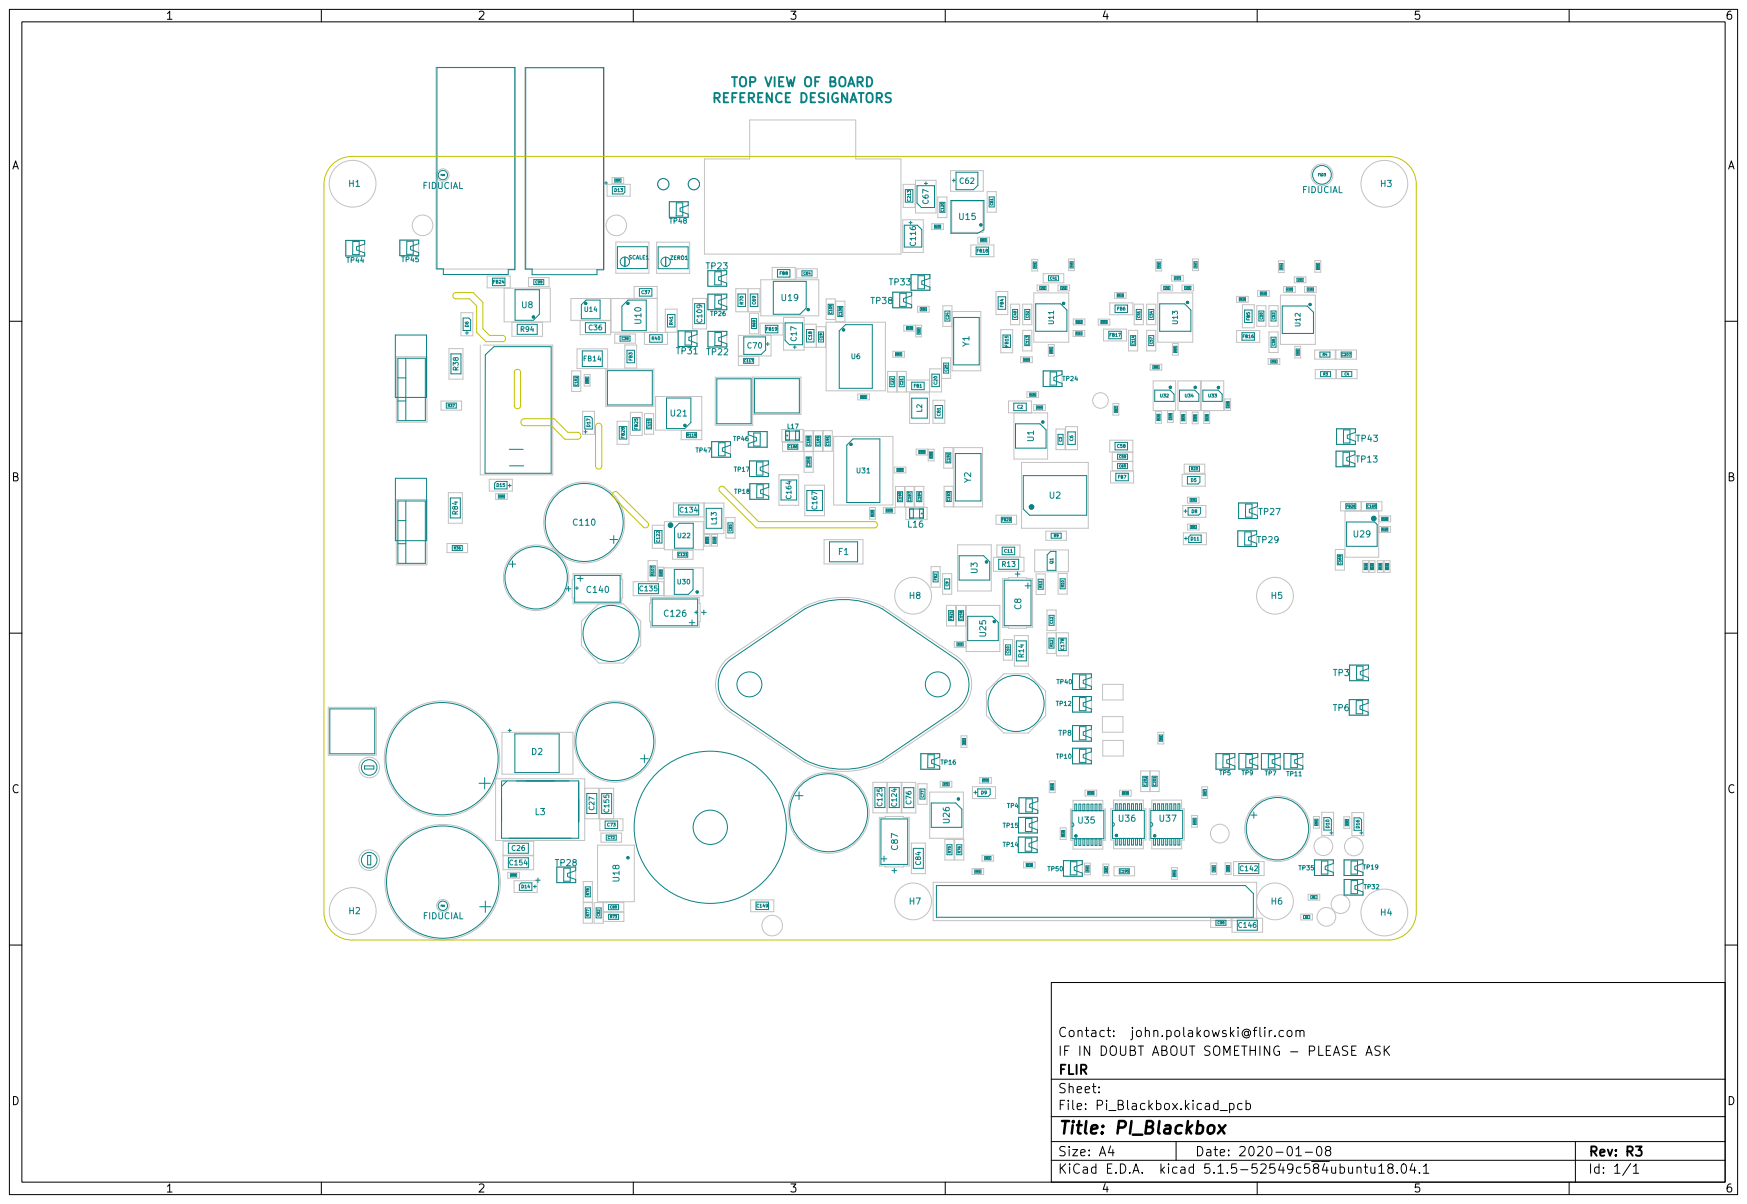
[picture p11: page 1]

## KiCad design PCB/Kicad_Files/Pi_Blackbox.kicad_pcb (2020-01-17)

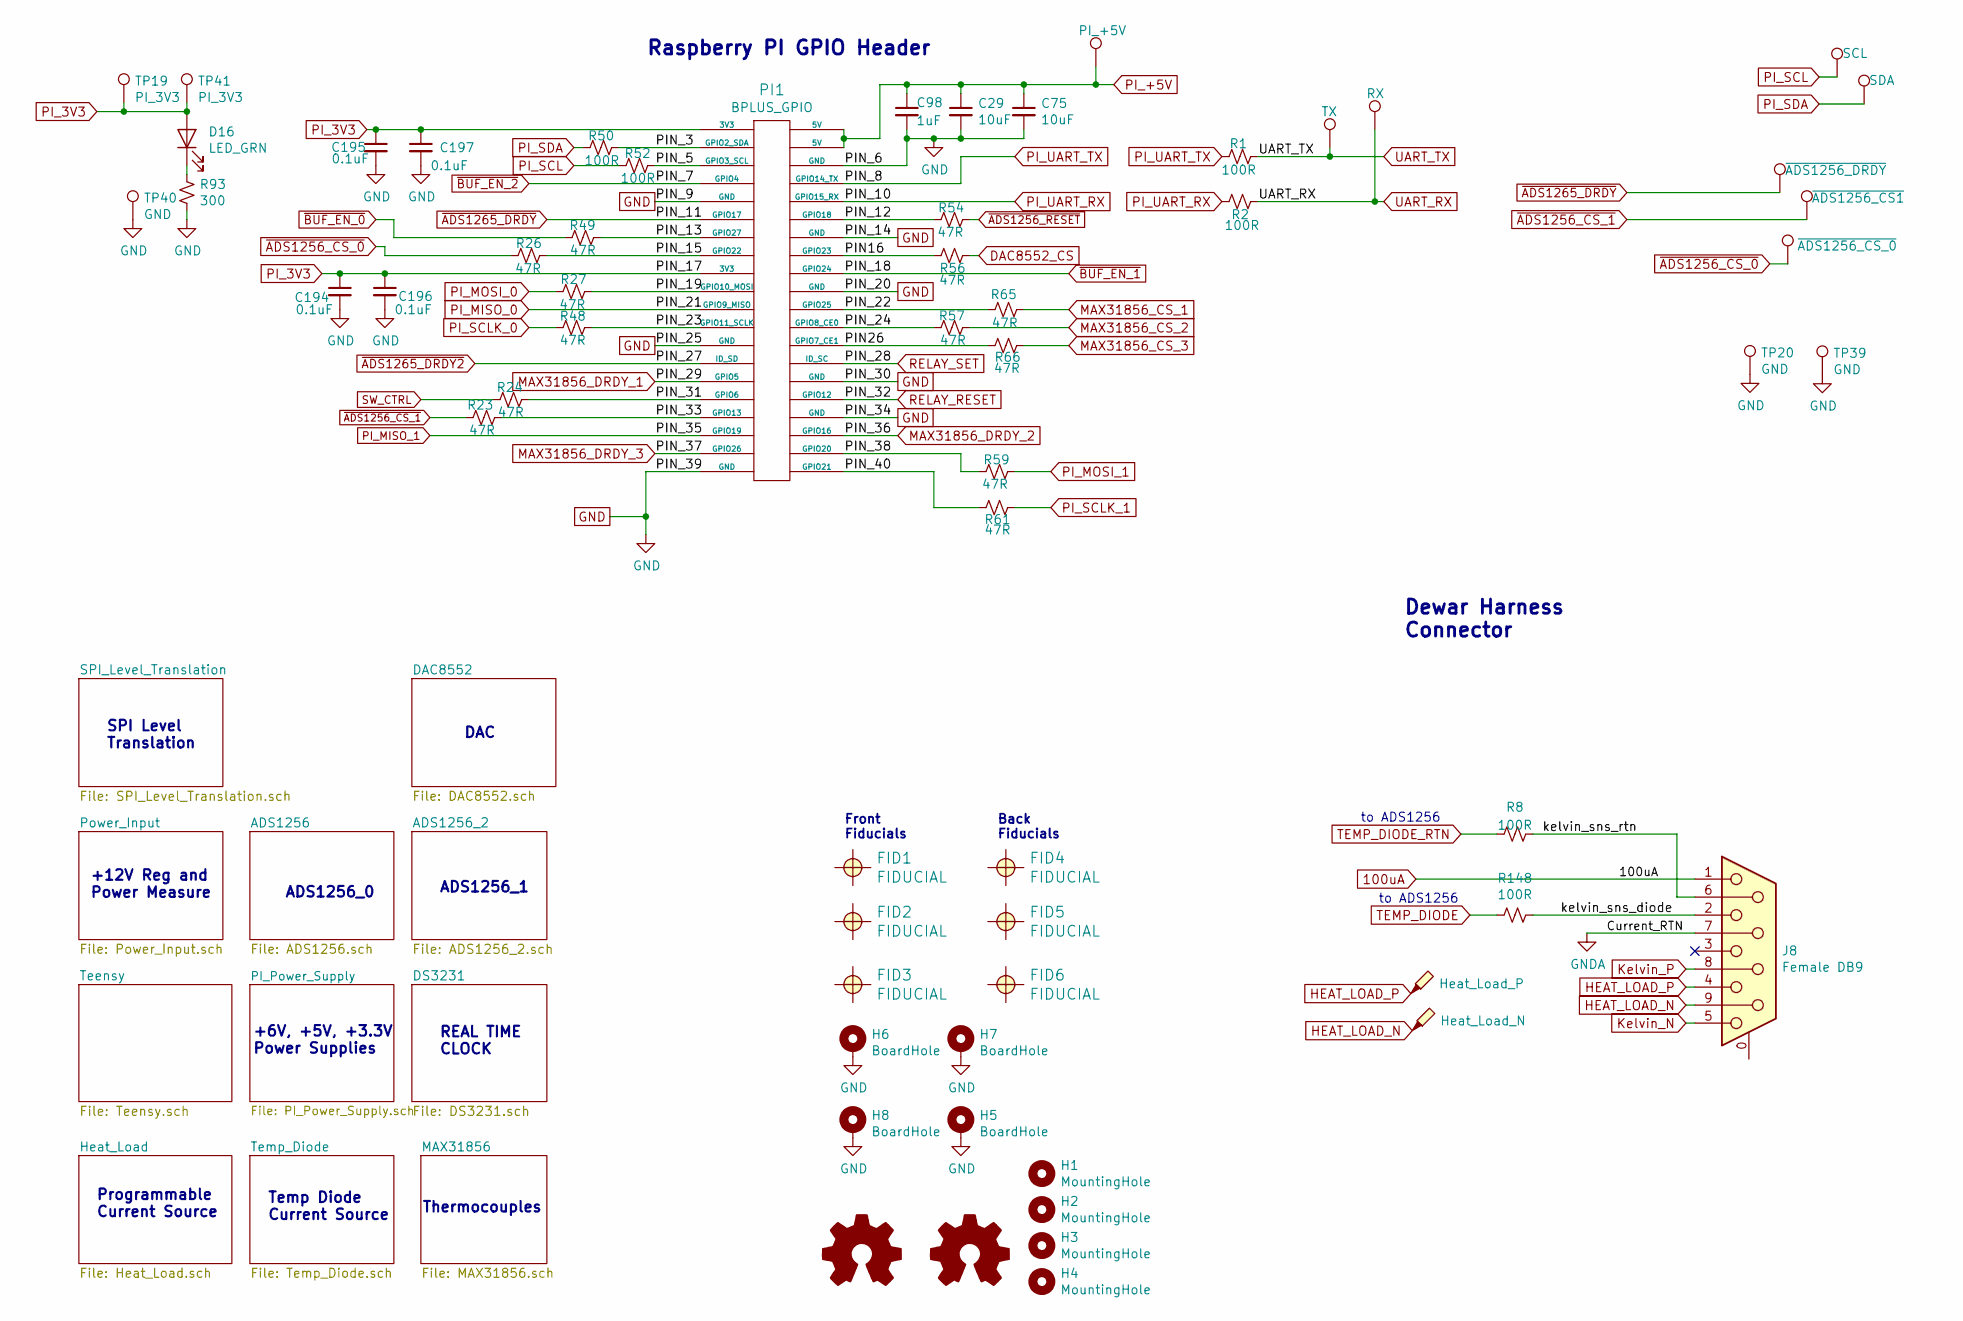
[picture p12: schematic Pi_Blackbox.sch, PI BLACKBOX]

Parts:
C29, C75: 10uF; C_1206_3216Metric_Pad1.42x1.75mm_HandSolder
C98: 1uF; C_0603_1608Metric_Pad1.05x0.95mm_HandSolder
C194, C195, C196, C197: 0.1uF; C_0603_1608Metric_Pad1.05x0.95mm_HandSolder
D16: LED_GRN; LED_0805_2012Metric_Pad1.15x1.40mm_HandSolder
FID1, FID2, FID4, FID5: FIDUCIAL; Fiducial_0.5mm_Mask1.5mm
FID3: FIDUCIAL; Fiducial_1.5mm_Mask3mm
FID6: FIDUCIAL; Fiducial_0.75mm_Mask2.25mm
H1, H2, H3, H4: MountingHole; MountingHole_3.5mm_Pad_Via
H5, H6, H7, H8: BoardHole; MountingHole_2.7mm_M2.5_Pad_Via
J8: Female DB9; DB9_D09S13A4GX00LF
PI1: BPLUS_GPIO; PinHeader_2x20_P2.54mm_Vertical
R1, R2, R8, R50, R52, R148: 100R; R_0402_1005Metric
R23, R24, R26, R27, R48, R49, R54, R56, R57, R59, R61, R65, R66: 47R; R_0402_1005Metric
R93: 300; R_0402_1005Metric
TP1: TX; TestPoint_Pad_D2.0mm
TP2: RX; TestPoint_Pad_D2.0mm
TP3: SCL; TestPoint_SMT_Keystone_5190
TP4: ~ADS1256_CS_0; TestPoint_SMT_Keystone_5190
TP6: SDA; TestPoint_SMT_Keystone_5190
TP13: Heat_Load_P; TestPoint_SMT_Keystone_5190
TP14: ~ADS1256_DRDY; TestPoint_SMT_Keystone_5190
TP15: ~ADS1256_CS1; TestPoint_SMT_Keystone_5190
TP19: PI_3V3; TestPoint_SMT_Keystone_5190
TP20: GND; TestPoint_Keystone_5000-5004_Miniature
TP39: GND; TestPoint_Pad_D2.0mm
TP40: GND; TestPoint_SMT_Keystone_5190
TP41: PI_3V3; TestPoint_Pad_D2.0mm
TP42: PI_+5V; TestPoint_Pad_D2.0mm
TP43: Heat_Load_N; TestPoint_SMT_Keystone_5190

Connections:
100uA: J8.1; also elsewhere on the board
/PIN16: PI1.16 (GPIO23), R56.2
/PIN26: PI1.26 (GPIO7_CE1), R66.2
/PIN_3: PI1.3 (GPIO2_SDA), R50.1
/PIN_5: PI1.5 (GPIO3_SCL), R52.1
/PIN_12: PI1.12 (GPIO18), R54.2
/PIN_13: PI1.13 (GPIO27), R49.1
/PIN_15: PI1.15 (GPIO22), R26.1
/PIN_19: PI1.19 (GPIO10_MOSI), R27.1
/PIN_22: PI1.22 (GPIO25), R65.2
/PIN_23: PI1.23 (GPIO11_SCLK), R48.1
/PIN_24: PI1.24 (GPIO8_CE0), R57.2
/PIN_31: PI1.31 (GPIO6), R24.1
/PIN_33: PI1.33 (GPIO13), R23.1
/PIN_38: PI1.38 (GPIO20), R59.2
/PIN_40: PI1.40 (GPIO21), R61.2
/kelvin_sns_diode: J8.2, R148.1
/kelvin_sns_rtn: J8.6, R8.1
DAC8552_CS: R56.1; also elsewhere on the board
GND: C29.2, C75.2, C98.2, C194.2, C195.2, C196.2, C197.2, H5.PAD, H6.PAD, H7.PAD, H8.PAD, J8.5, J8.9, PI1.6 (GND), PI1.9 (GND), PI1.14 (GND), PI1.20 (GND), PI1.25 (GND), PI1.30 (GND), PI1.34 (GND), PI1.39 (GND), R93.2, TP20.1, TP39.1, TP40.1, TP43.1; also elsewhere on the board
GNDA: J8.7; also elsewhere on the board
HEAT_LOAD_P: J8.4, J8.8, TP13.1; also elsewhere on the board
MAX31856_CS_1: R65.1; also elsewhere on the board
MAX31856_CS_2: R57.1; also elsewhere on the board
MAX31856_CS_3: R66.1; also elsewhere on the board
MAX31856_DRDY_1: PI1.29 (GPIO5); also elsewhere on the board
MAX31856_DRDY_2: PI1.36 (GPIO16); also elsewhere on the board
MAX31856_DRDY_3: PI1.37 (GPIO26); also elsewhere on the board
unnamed: D16.1 (K), R93.1
PI_3V3: C194.1, C195.1, C196.1, C197.1, D16.2 (A), PI1.1 (3V3), PI1.17 (3V3), TP19.1, TP41.1
PI_+5V: C29.1, C75.1, C98.1, PI1.2 (5V), PI1.4 (5V), TP42.1; also elsewhere on the board
PI_MISO_0: PI1.21 (GPIO9_MISO); also elsewhere on the board
PI_MISO_1: PI1.35 (GPIO19); also elsewhere on the board
PI_MOSI_0: R27.2; also elsewhere on the board
PI_MOSI_1: R59.1; also elsewhere on the board
PI_SCL: R52.2, TP3.1; also elsewhere on the board
PI_SCLK_0: R48.2; also elsewhere on the board
PI_SCLK_1: R61.1; also elsewhere on the board
PI_SDA: R50.2, TP6.1; also elsewhere on the board
PI_UART_RX: PI1.10 (GPIO15_RX), R2.2; also elsewhere on the board
PI_UART_TX: PI1.8 (GPIO14_TX), R1.2; also elsewhere on the board
RELAY_RESET: PI1.32 (GPIO12); also elsewhere on the board
RELAY_SET: PI1.28 (ID_SC); also elsewhere on the board
SW_CTRL: R24.2; also elsewhere on the board
TEMP_DIODE: R148.2; also elsewhere on the board
TEMP_DIODE_RTN: R8.2; also elsewhere on the board
UART_RX: R2.1, TP2.1
UART_TX: R1.1, TP1.1
~ADS1256_CS_0: R26.2, TP4.1; also elsewhere on the board
~ADS1256_CS_1: R23.2, TP15.1; also elsewhere on the board
~ADS1256_RESET: R54.1; also elsewhere on the board
~ADS1265_DRDY: PI1.11 (GPIO17), TP14.1; also elsewhere on the board
~ADS1265_DRDY2: PI1.27 (ID_SD); also elsewhere on the board
~BUF_EN_0: R49.2; also elsewhere on the board
~BUF_EN_1: PI1.18 (GPIO24); also elsewhere on the board
~BUF_EN_2: PI1.7 (GPIO4); also elsewhere on the board

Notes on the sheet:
Raspberry PI GPIO Header
REAL TIME CLOCK
to ADS1256
Dewar Harness Connector
Programmable Current Source
Thermocouples
DAC
ADS1256_0
ADS1256_1
+6V, +5V, +3.3V Power Supplies
Temp Diode Current Source
SPI Level Translation
+12V Reg and Power Measure
Front Fiducials
Back Fiducials

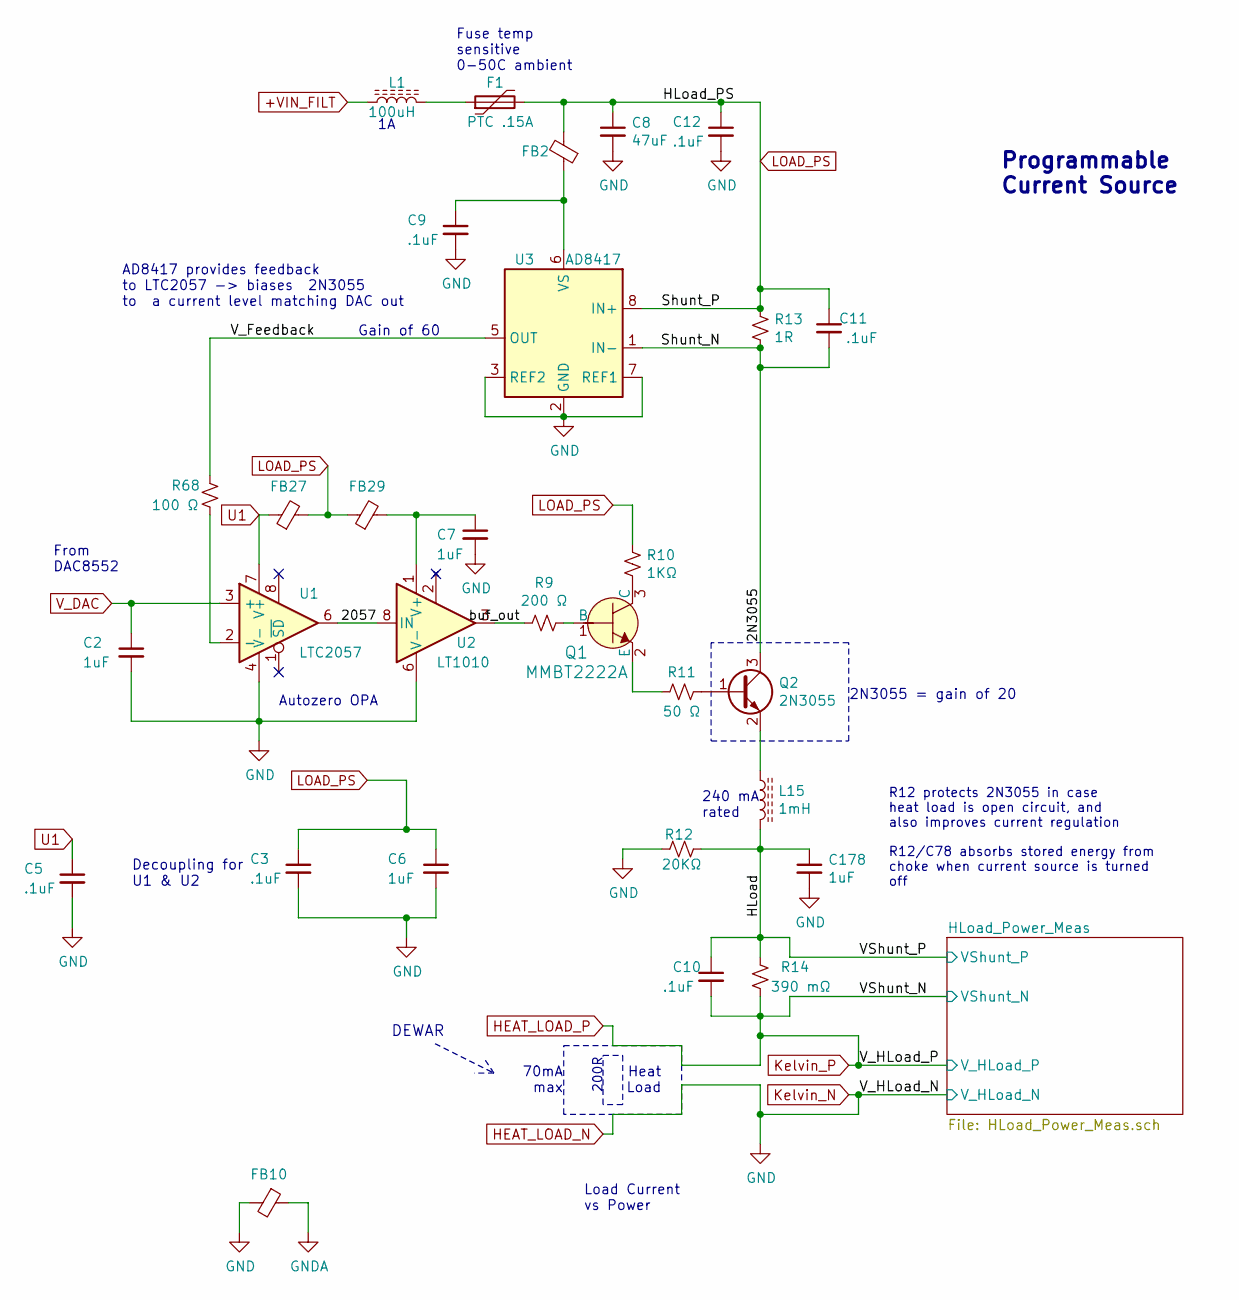
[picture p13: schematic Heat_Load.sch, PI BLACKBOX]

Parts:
C2, C6, C7, C178: 1uF; C_0805_2012Metric_Pad1.15x1.40mm_HandSolder
C3, C5, C9, C10, C12: .1uF; C_0603_1608Metric_Pad1.05x0.95mm_HandSolder
C8: 47uF; T495X476K035ATE300
C11: .1uF; C_0805_2012Metric_Pad1.15x1.40mm_HandSolder
F1: PTC .15A; R_1812_4532Metric_Pad1.30x3.40mm_HandSolder
FB2: FB; L_0603_1608Metric_Pad1.05x0.95mm_HandSolder
FB10: FB; L_1210_3225Metric_Pad1.42x2.65mm_HandSolder
FB27, FB29: Ferrite; C_0603_1608Metric_Pad1.05x0.95mm_HandSolder
L1: 100uH; L_Wuerth_WE-PD-Typ-LS_Handsoldering
L15: 1mH; RLB9012-222KL
Q1: MMBT2222A; SOT-23_Handsoldering; MPN MMBT2222A-7-F; Digi-Key_PN MMBT2222A-FDICT-ND
Q2: 2N3055; TO-3
R9: 200 Ω; R_0603_1608Metric_Pad1.05x0.95mm_HandSolder
R10: 1KΩ; R_0603_1608Metric_Pad1.05x0.95mm_HandSolder
R11: 50 Ω; R_0603_1608Metric_Pad1.05x0.95mm_HandSolder
R12: 20KΩ; R_0603_1608Metric_Pad1.05x0.95mm_HandSolder
R13: 1R; R_1206_3216Metric_Pad1.42x1.75mm_HandSolder
R14: 390 mΩ; R_1206_3216Metric_Pad1.42x1.75mm_HandSolder
R68: 100 Ω; R_0402_1005Metric
U1: LTC2057; SOIC-8_3.9x4.9mm_P1.27mm
U2: LT1010; DIP-8_W7.62mm_LongPads
U3: AD8417; SOIC-8_3.9x4.9mm_P1.27mm

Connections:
+VIN_FILT: L1.1; also elsewhere on the board
/Heat_Load/2N3055: C11.2, Q2.3 (C), R13.2, U3.1 (IN-)
/Heat_Load/2057: U1.6, U2.8 (IN)
/Heat_Load/HLoad: C10.1, C178.1, L15.2, R12.1, R14.1; also elsewhere on the board
/Heat_Load/V_Feedback: R68.2, U3.5 (OUT)
/Heat_Load/buf_out: R9.2, U2.3
GND: C2.2, C3.2, C5.2, C6.2, C7.2, C8.2, C9.2, C12.2, C178.2, FB10.2, R12.2, U1.4 (V-), U2.6 (V-), U3.2 (GND), U3.3 (REF2), U3.7 (REF1); also elsewhere on the board
GNDA: FB10.1; also elsewhere on the board
HEAT_LOAD_P: C10.2, R14.2; also elsewhere on the board
LOAD_PS: C3.1, C6.1, C8.1, C11.1, C12.1, F1.2, FB2.2, FB27.2, FB29.1, R10.1, R13.1, U3.8 (IN+); also elsewhere on the board
unnamed: C7.1, FB29.2, U2.1 (V+)
unnamed: C9.1, FB2.1, U3.6 (VS)
unnamed: F1.1, L1.2
unnamed: L15.1, Q2.2 (E)
unnamed: Q1.1 (B), R9.1
unnamed: Q1.2 (E), R11.2
unnamed: Q1.3 (C), R10.2
unnamed: Q2.1 (B), R11.1
unnamed: R68.1, U1.2 (-)
U1: C5.1, FB27.1, U1.7 (V+)
V_DAC: C2.1, U1.3 (+); also elsewhere on the board

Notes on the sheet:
Heat Load
From DAC8552
Autozero OPA
AD8417 provides feedback to LTC2057 -> biases 2N3055 to a current level matching DAC out
70mA max
Fuse temp sensitive 0-50C ambient
200R
Programmable Current Source
Load Current vs Power
Decoupling for U1 & U2
DEWAR
2N3055 = gain of 20
Gain of 60
240 mA rated
R12 protects 2N3055 in case heat load is open circuit, and also improves current regulation
R12/C78 absorbs stored energy from choke when current source is turned off

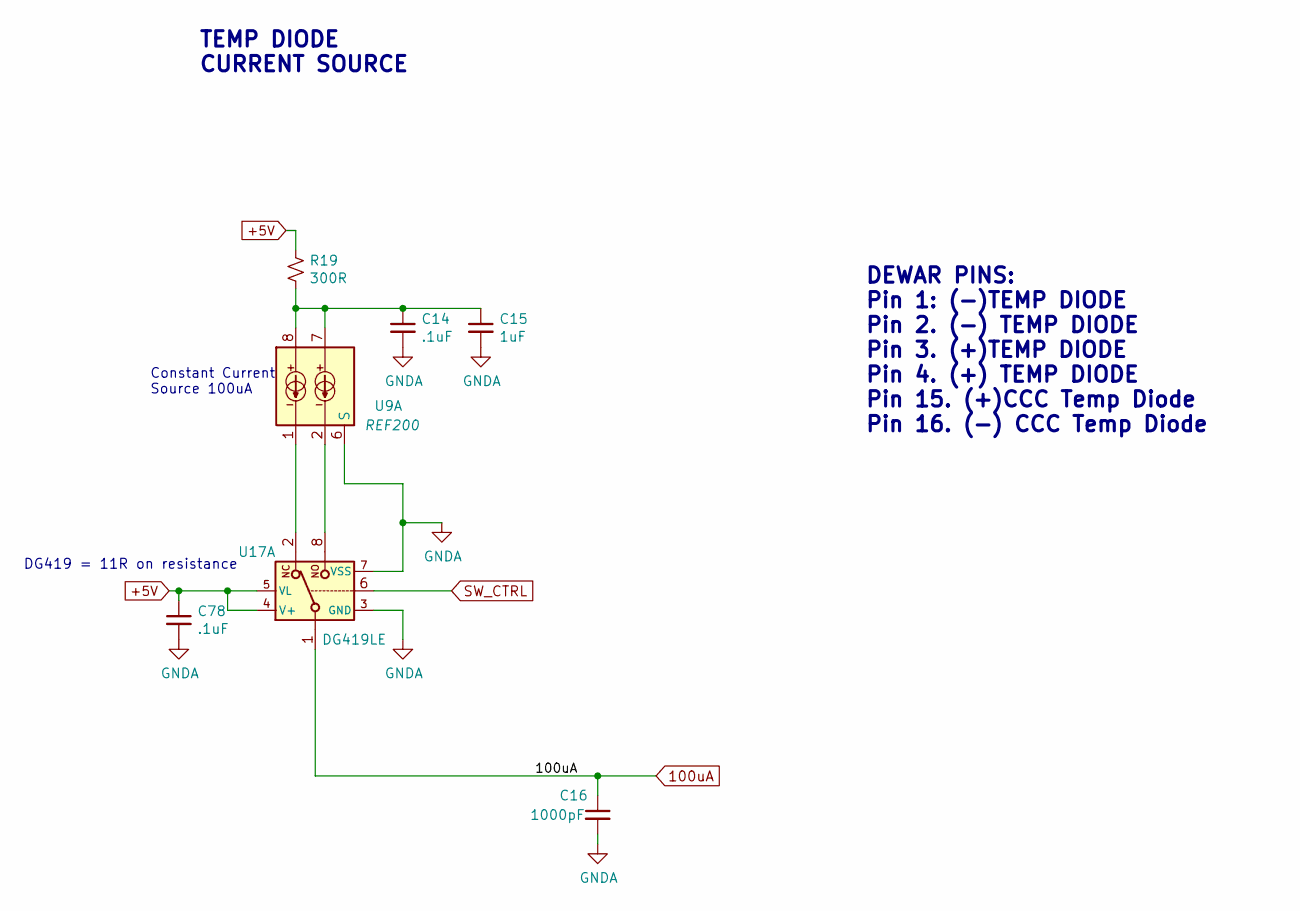
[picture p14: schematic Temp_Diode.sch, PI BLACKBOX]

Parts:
C14, C78: .1uF; C_0603_1608Metric_Pad1.05x0.95mm_HandSolder
C15: 1uF; C_0805_2012Metric_Pad1.15x1.40mm_HandSolder
C16: 1000pF; C_0402_1005Metric
R19: 300R; R_0603_1608Metric_Pad1.05x0.95mm_HandSolder
U9: REF200; SOIC-8_3.9x4.9mm_P1.27mm
U17: DG419LE; MSOP-8_3x3mm_P0.65mm

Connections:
100uA: C16.1, U17.1; also elsewhere on the board
+5V: C78.1, R19.1, U17.4 (V+), U17.5 (VL); also elsewhere on the board
GNDA: C14.2, C15.2, C16.2, C78.2, U9.6 (S), U17.3 (GND), U17.7 (V-); also elsewhere on the board
unnamed: C14.1, C15.1, R19.2, U9.7, U9.8
unnamed: U9.1, U17.2
unnamed: U9.2, U17.8
SW_CTRL: U17.6; also elsewhere on the board

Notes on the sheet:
Constant Current Source 100uA
TEMP DIODE CURRENT SOURCE
DG419 = 11R on resistance
DEWAR PINS: Pin 1: (-)TEMP DIODE Pin 2. (-) TEMP DIODE Pin 3. (+)TEMP DIODE Pin 4. (+) TEMP DIODE Pin 15. (+)CCC Temp Diode Pin 16. (-) CCC Temp Diode

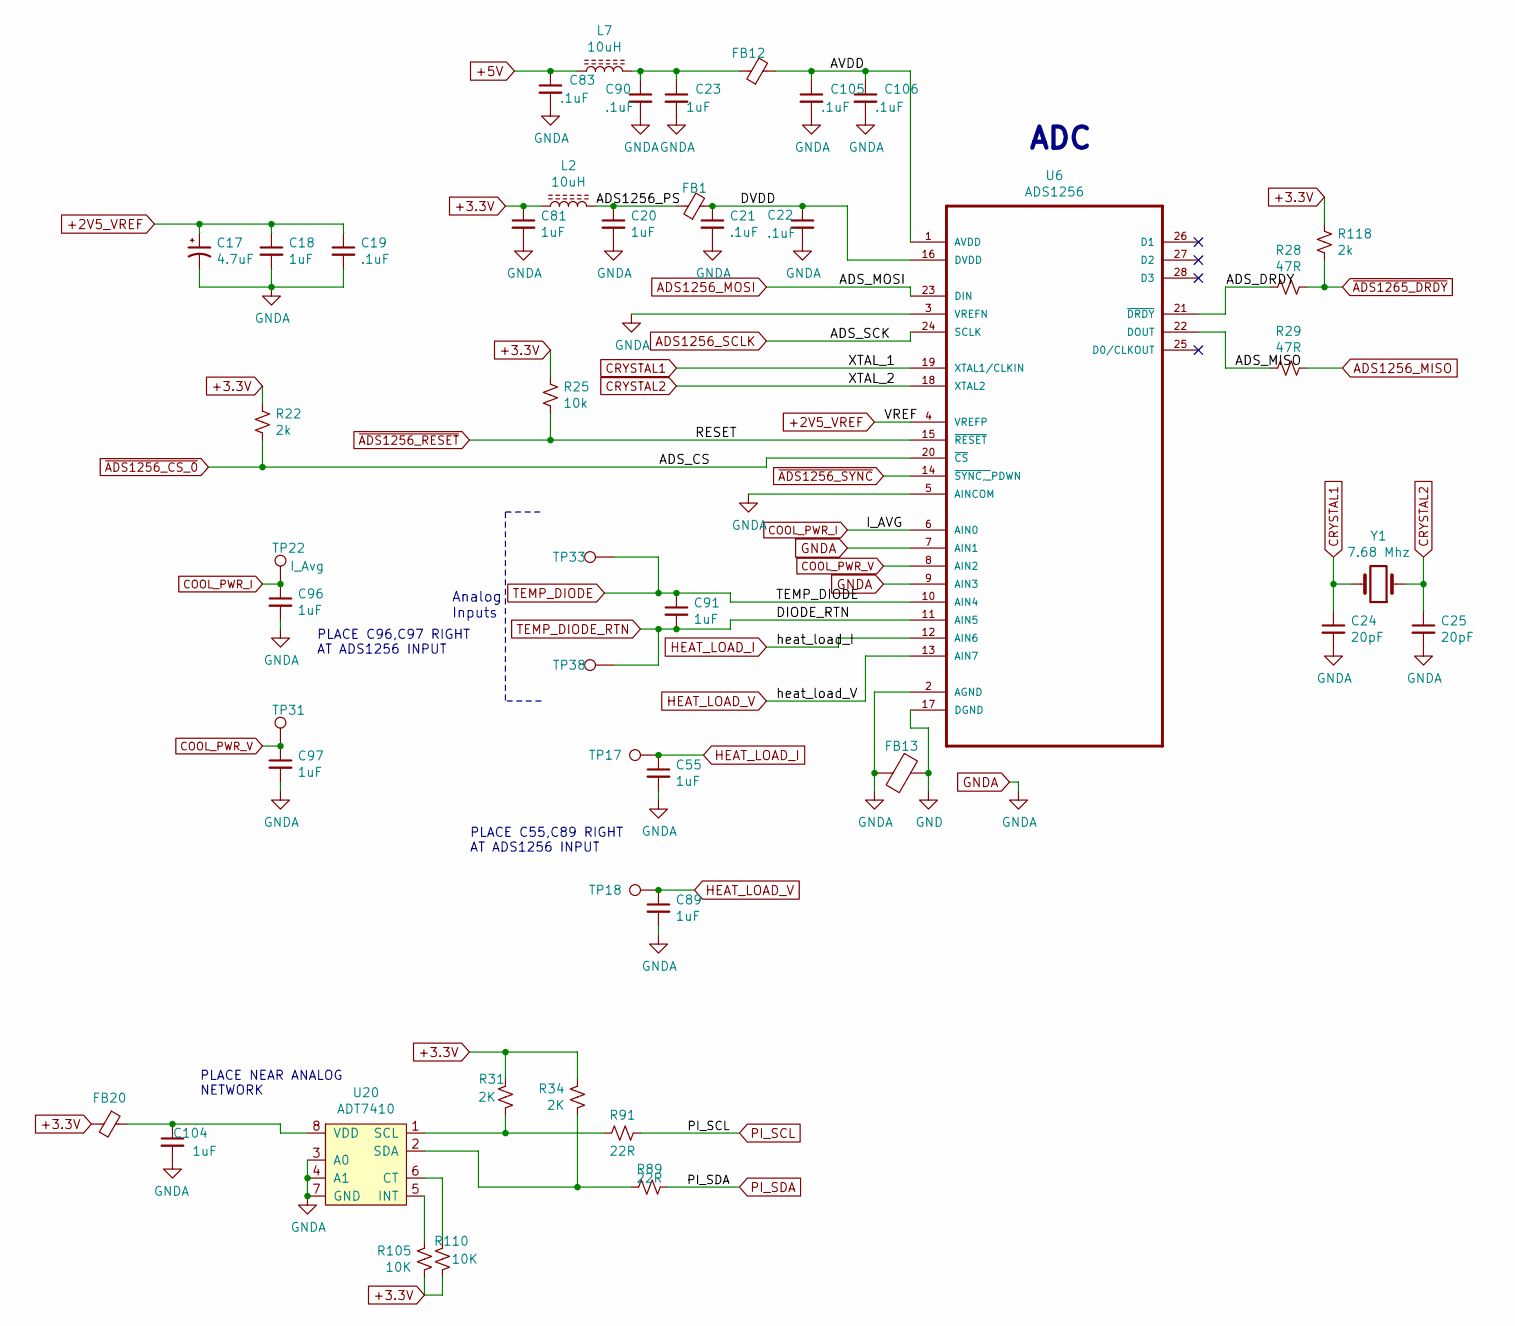
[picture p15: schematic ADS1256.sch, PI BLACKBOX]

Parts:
C17: 4.7uF; CP_EIA-3528-21_Kemet-B_Pad1.50x2.35mm_HandSolder
C18, C20, C55, C81, C89, C104: 1uF; C_0805_2012Metric_Pad1.15x1.40mm_HandSolder
C19, C90, C105, C106: .1uF; C_0603_1608Metric_Pad1.05x0.95mm_HandSolder
C21, C22, C83: .1uF; R_0603_1608Metric_Pad1.05x0.95mm_HandSolder
C23: 1uF; C_0603_1608Metric_Pad1.05x0.95mm_HandSolder
C24, C25: 20pF; C_0603_1608Metric_Pad1.05x0.95mm_HandSolder
C91, C96, C97: 1uF; C_1210_3225Metric_Pad1.42x2.65mm_HandSolder
FB1, FB12: FB; R_0805_2012Metric_Pad1.15x1.40mm_HandSolder
FB13: FB; L_1210_3225Metric_Pad1.42x2.65mm_HandSolder
FB20: FB; L_0805_2012Metric_Pad1.15x1.40mm_HandSolder
L2, L7: 10uH; L_1210_3225Metric_Pad1.42x2.65mm_HandSolder
R22, R118: 2k; R_0402_1005Metric
R25: 10k; R_0402_1005Metric
R28, R29: 47R; R_0402_1005Metric
R31, R34: 2K; R_0402_1005Metric
R89, R91: 22R; R_0402_1005Metric
R105, R110: 10K; R_0402_1005Metric
TP17: LOAD_I; TestPoint_SMT_Keystone_5190
TP18: LOAD_V; TestPoint_SMT_Keystone_5190
TP22: I_Avg; TestPoint_SMT_Keystone_5190
TP31: CLR_V; TestPoint_SMT_Keystone_5190
TP33: Temp_Diode; TestPoint_SMT_Keystone_5190
TP38: Diode_RTN; TestPoint_SMT_Keystone_5190
U6: ADS1256; SSOP-28_5.3x10.2mm_P0.65mm
U20: ADT7410; SOIC-8_3.9x4.9mm_P1.27mm
Y1: 7.68 Mhz; Crystal_SMD_TXC

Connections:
+2V5_VREF: C17.1, C18.1, C19.1, U6.4 (VREFP); also elsewhere on the board
+3.3V: C81.1, FB20.2, L2.1, R22.1, R25.1, R31.1, R34.1, R105.2, R110.2, R118.1; also elsewhere on the board
+5V: C83.1, L7.1; also elsewhere on the board
/ADS1256/ADS1256_PS: C20.1, FB1.1, L2.2
/ADS1256/ADS_DRDY: R28.2, U6.21 (~DRDY)
/ADS1256/ADS_MISO: R29.2, U6.22 (DOUT)
/ADS1256/AVDD: C105.1, C106.1, FB12.2, U6.1 (AVDD)
/ADS1256/DVDD: C21.1, C22.1, FB1.2, U6.16 (DVDD)
ADS1256_MISO: R29.1; also elsewhere on the board
ADS1256_MOSI: U6.23 (DIN); also elsewhere on the board
ADS1256_SCLK: U6.24 (SCLK); also elsewhere on the board
COOL_PWR_I: C96.1, TP22.1, U6.6 (AIN0); also elsewhere on the board
COOL_PWR_V: C97.1, TP31.1, U6.8 (AIN2); also elsewhere on the board
CRYSTAL1: C24.1, U6.19 (XTAL1/CLKIN), Y1.2
CRYSTAL2: C25.1, U6.18 (XTAL2), Y1.1
GND: FB13.1, U6.17 (DGND); also elsewhere on the board
GNDA: C17.2, C18.2, C19.2, C20.2, C21.2, C22.2, C23.2, C24.2, C25.2, C55.2, C81.2, C83.2, C89.2, C90.2, C96.2, C97.2, C104.2, C105.2, C106.2, FB13.2, U6.2 (AGND), U6.3 (VREFN), U6.5 (AINCOM), U6.7 (AIN1), U6.9 (AIN3), U20.3 (A0), U20.4 (A1), U20.7 (GND); also elsewhere on the board
HEAT_LOAD_I: C55.1, TP17.1, U6.12 (AIN6); also elsewhere on the board
HEAT_LOAD_V: C89.1, TP18.1, U6.13 (AIN7); also elsewhere on the board
unnamed: C23.1, C90.1, FB12.1, L7.2
unnamed: C104.1, FB20.1, U20.8 (VDD)
unnamed: R31.2, R91.2, U20.1 (SCL)
unnamed: R34.2, R89.2, U20.2 (SDA)
unnamed: R105.1, U20.5 (INT)
unnamed: R110.1, U20.6 (CT)
PI_SCL: R91.1; also elsewhere on the board
PI_SDA: R89.1; also elsewhere on the board
TEMP_DIODE: C91.1, TP33.1, U6.10 (AIN4); also elsewhere on the board
TEMP_DIODE_RTN: C91.2, TP38.1, U6.11 (AIN5); also elsewhere on the board
~ADS1256_CS_0: R22.2, U6.20 (~CS); also elsewhere on the board
~ADS1256_RESET: R25.2, U6.15 (~RESET); also elsewhere on the board
~ADS1256_SYNC: U6.14 (~SYNC,_~PDWN)
~ADS1265_DRDY: R28.1, R118.2; also elsewhere on the board

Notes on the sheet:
ADC
Analog Inputs
PLACE C96,C97 RIGHT AT ADS1256 INPUT
PLACE C55,C89 RIGHT AT ADS1256 INPUT
PLACE NEAR ANALOG NETWORK

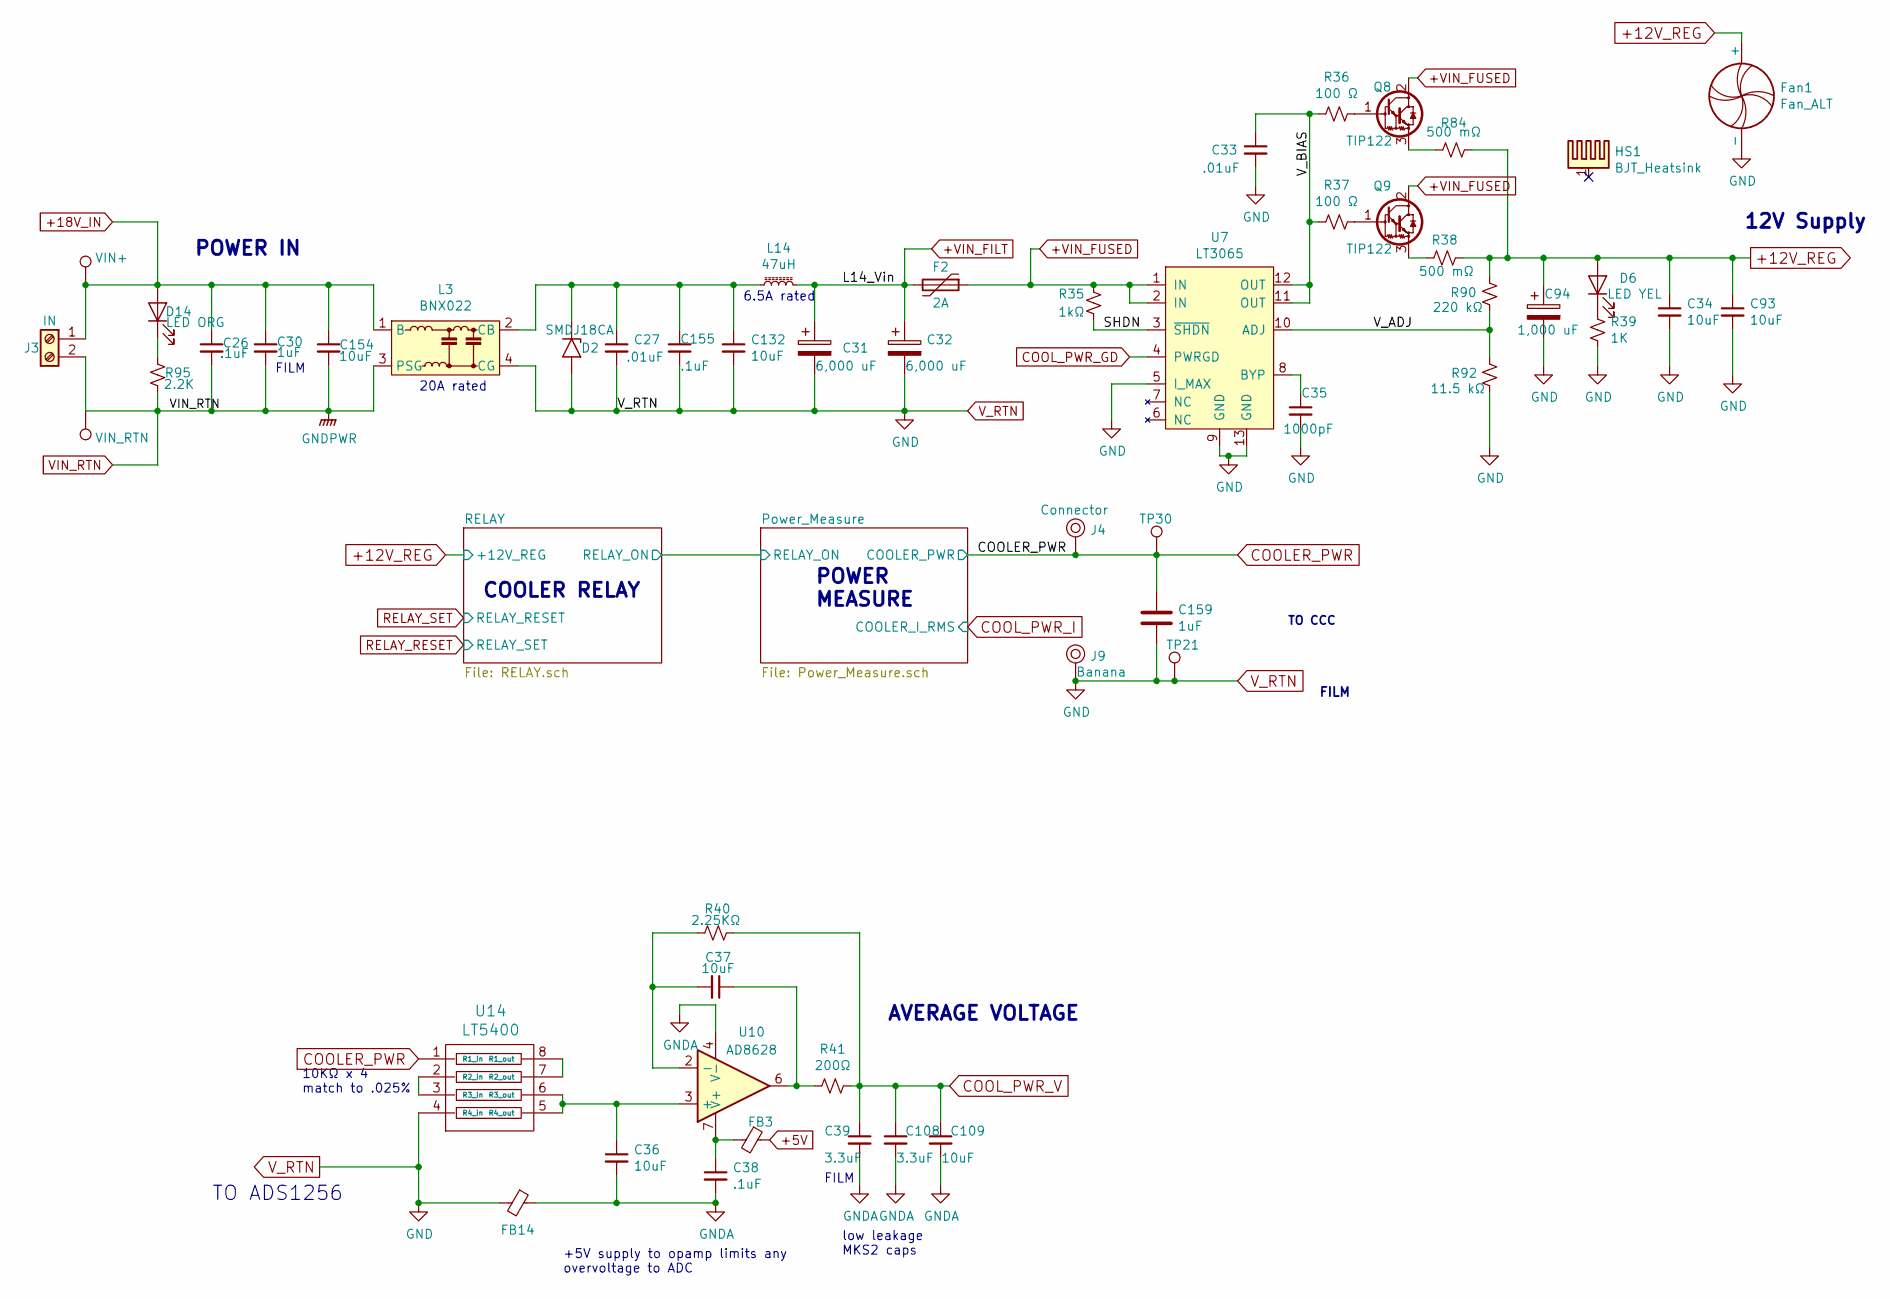
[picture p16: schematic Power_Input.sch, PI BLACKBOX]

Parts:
C26: .1uF; C_1206_3216Metric_Pad1.42x1.75mm_HandSolder; MFG Part # 12065C104KAT4A
C27: .01uF; C_1206_3216Metric_Pad1.42x1.75mm_HandSolder
C30: 1uF; C_Rect_L7.2mm_W7.2mm_P5.00mm_FKS2_FKP2_MKS2_MKP2
C31, C32: 6,000 uF; Chemicon_LBK_Series
C33: .01uF; C_0603_1608Metric_Pad1.05x0.95mm_HandSolder
C34, C36, C93, C109, C132, C154: 10uF; C_1206_3216Metric_Pad1.42x1.75mm_HandSolder
C35: 1000pF; C_0402_1005Metric
C37: 10uF; C_0805_2012Metric_Pad1.15x1.40mm_HandSolder
C38: .1uF; C_0603_1608Metric_Pad1.05x0.95mm_HandSolder
C39, C108: 3.3uF; C_Rect_L7.2mm_W5.5mm_P5.00mm_FKS2_FKP2_MKS2_MKP2
C94: 1,000 uF; CP_Radial_D12.5mm_P5.00mm
C155: .1uF; C_1206_3216Metric_Pad1.42x1.75mm_HandSolder
C159: 1uF; C_1210_3225Metric_Pad1.42x2.65mm_HandSolder
D2: SMDJ18CA
D6: LED YEL; LED_0805_2012Metric_Pad1.15x1.40mm_HandSolder
D14: LED ORG; LED_0805_2012Metric_Pad1.15x1.40mm_HandSolder
F2: 2A; Fuse_2920
FB3: FB; R_0805_2012Metric_Pad1.15x1.40mm_HandSolder
FB14: FB; L_1210_3225Metric_Pad1.42x2.65mm_HandSolder
Fan1: Fan_ALT; Fan_30mmx30mmx10mm
HS1: BJT_Heatsink; Heat_Sink_Omni_220-18-50-2C
J3: IN; 2-1445057-2
J4: Connector; Pomona_Banana_73099_red; MPN 105-1102-001; Digi-Key_PN J576-ND
J9: Banana; Pomona_Banana_73099; MPN 105-1102-001; Digi-Key_PN J576-ND
L3: BNX022
L14: 47uH; L_Bourns_SRP1265A
Q8, Q9: TIP122; TO-220-3_Vertical
R35: 1kΩ; R_0402_1005Metric
R36, R37: 100 Ω; R_0603_1608Metric_Pad1.05x0.95mm_HandSolder
R38, R84: 500 mΩ; R_1206_3216Metric_Pad1.42x1.75mm_HandSolder
R39: 1K; R_0402_1005Metric
R40: 2.25KΩ; R_0805_2012Metric_Pad1.15x1.40mm_HandSolder
R41: 200Ω; R_0805_2012Metric_Pad1.15x1.40mm_HandSolder
R90: 220 kΩ; R_0603_1608Metric_Pad1.05x0.95mm_HandSolder
R92: 11.5 kΩ; C_0603_1608Metric_Pad1.05x0.95mm_HandSolder
R95: 2.2K; R_0402_1005Metric
TP21: COOLER-; TestPoint_Keystone_5000-5004_Miniature
TP30: COOLER_PWR; TestPoint_Keystone_5000-5004_Miniature
TP37: VIN+; TestPoint_Keystone_5000-5004_Miniature
TP49: VIN_RTN; TestPoint_Keystone_5000-5004_Miniature
U7: LT3065; MSOP-12-1EP_3x4mm_P0.65mm_EP1.65x2.85mm_ThermalVias
U10: AD8628; SOIC-8_3.9x4.9mm_P1.27mm
U14: LT5400; MSOP-8_3x3mm_P0.65mm

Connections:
+5V: FB3.1; also elsewhere on the board
+12V_REG: C34.1, C93.1, C94.1, D6.2 (A), Fan1.1 (+), R38.1, R84.1, R90.1; also elsewhere on the board
+18V_IN: C26.1, C30.1, C154.1, D14.2 (A), J3.1, L3.1 (B), TP37.1
+VIN_FILT: C31.1, C32.1, F2.2, L14.2; also elsewhere on the board
+VIN_FUSED: F2.1, Q8.2 (C), Q9.2 (C), R35.1, U7.1 (IN), U7.2 (IN)
/Power_Input/SHDN: R35.2, U7.3 (~SHDN)
/Power_Input/V_ADJ: R90.2, R92.1, U7.10 (ADJ)
/Power_Input/V_BIAS: C33.1, R36.2, R37.2, U7.11 (OUT), U7.12 (OUT)
COOLER_PWR: C159.1, J4.1, TP30.1, U14.1 (R1_in); also elsewhere on the board
COOL_PWR_GD: U7.4 (PWRGD)
COOL_PWR_V: C39.1, C108.1, C109.1, R40.1, R41.1; also elsewhere on the board
GND: C27.2, C31.2, C32.2, C33.2, C34.2, C35.2, C93.2, C94.2, C132.2, C155.2, C159.2, D2.2 (A2), FB14.2, Fan1.2 (-), J9.1, L3.4 (CG), R39.2, R92.2, TP21.1, U7.5 (I_MAX), U7.9 (GND), U7.13 (GND), U14.4 (R4_in); also elsewhere on the board
GNDA: C36.2, C38.2, C39.2, C108.2, C109.2, FB14.1, U10.4 (V-); also elsewhere on the board
unnamed: C35.1, U7.8 (BYP)
unnamed: C36.1, U10.3 (+), U14.5 (R4_out), U14.6 (R3_out)
unnamed: C37.1, R41.2, U10.6
unnamed: C37.2, R40.2, U10.2 (-)
unnamed: C38.1, FB3.2, U10.7 (V+)
unnamed: C27.1, C132.1, C155.1, D2.1 (A1), L3.2 (CB), L14.1
unnamed: D6.1 (K), R39.1
unnamed: D14.1 (K), R95.1
unnamed: Q8.1 (B), R36.1
unnamed: Q8.3 (E), R84.2
unnamed: Q9.1 (B), R37.1
unnamed: Q9.3 (E), R38.2
unnamed: U14.2 (R2_in), U14.3 (R3_in)
unnamed: U14.7 (R2_out), U14.8 (R1_out)
VIN_RTN: C26.2, C30.2, C154.2, J3.2, L3.3 (PSG), R95.2, TP49.1

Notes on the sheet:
12V Supply
COOLER RELAY
+5V supply to opamp limits any overvoltage to ADC
10KΩ x 4 match to .025%
low leakage MKS2 caps
TO ADS1256
AVERAGE VOLTAGE
POWER IN
20A rated
6.5A rated
FILM
FILM
POWER MEASURE
TO CCC

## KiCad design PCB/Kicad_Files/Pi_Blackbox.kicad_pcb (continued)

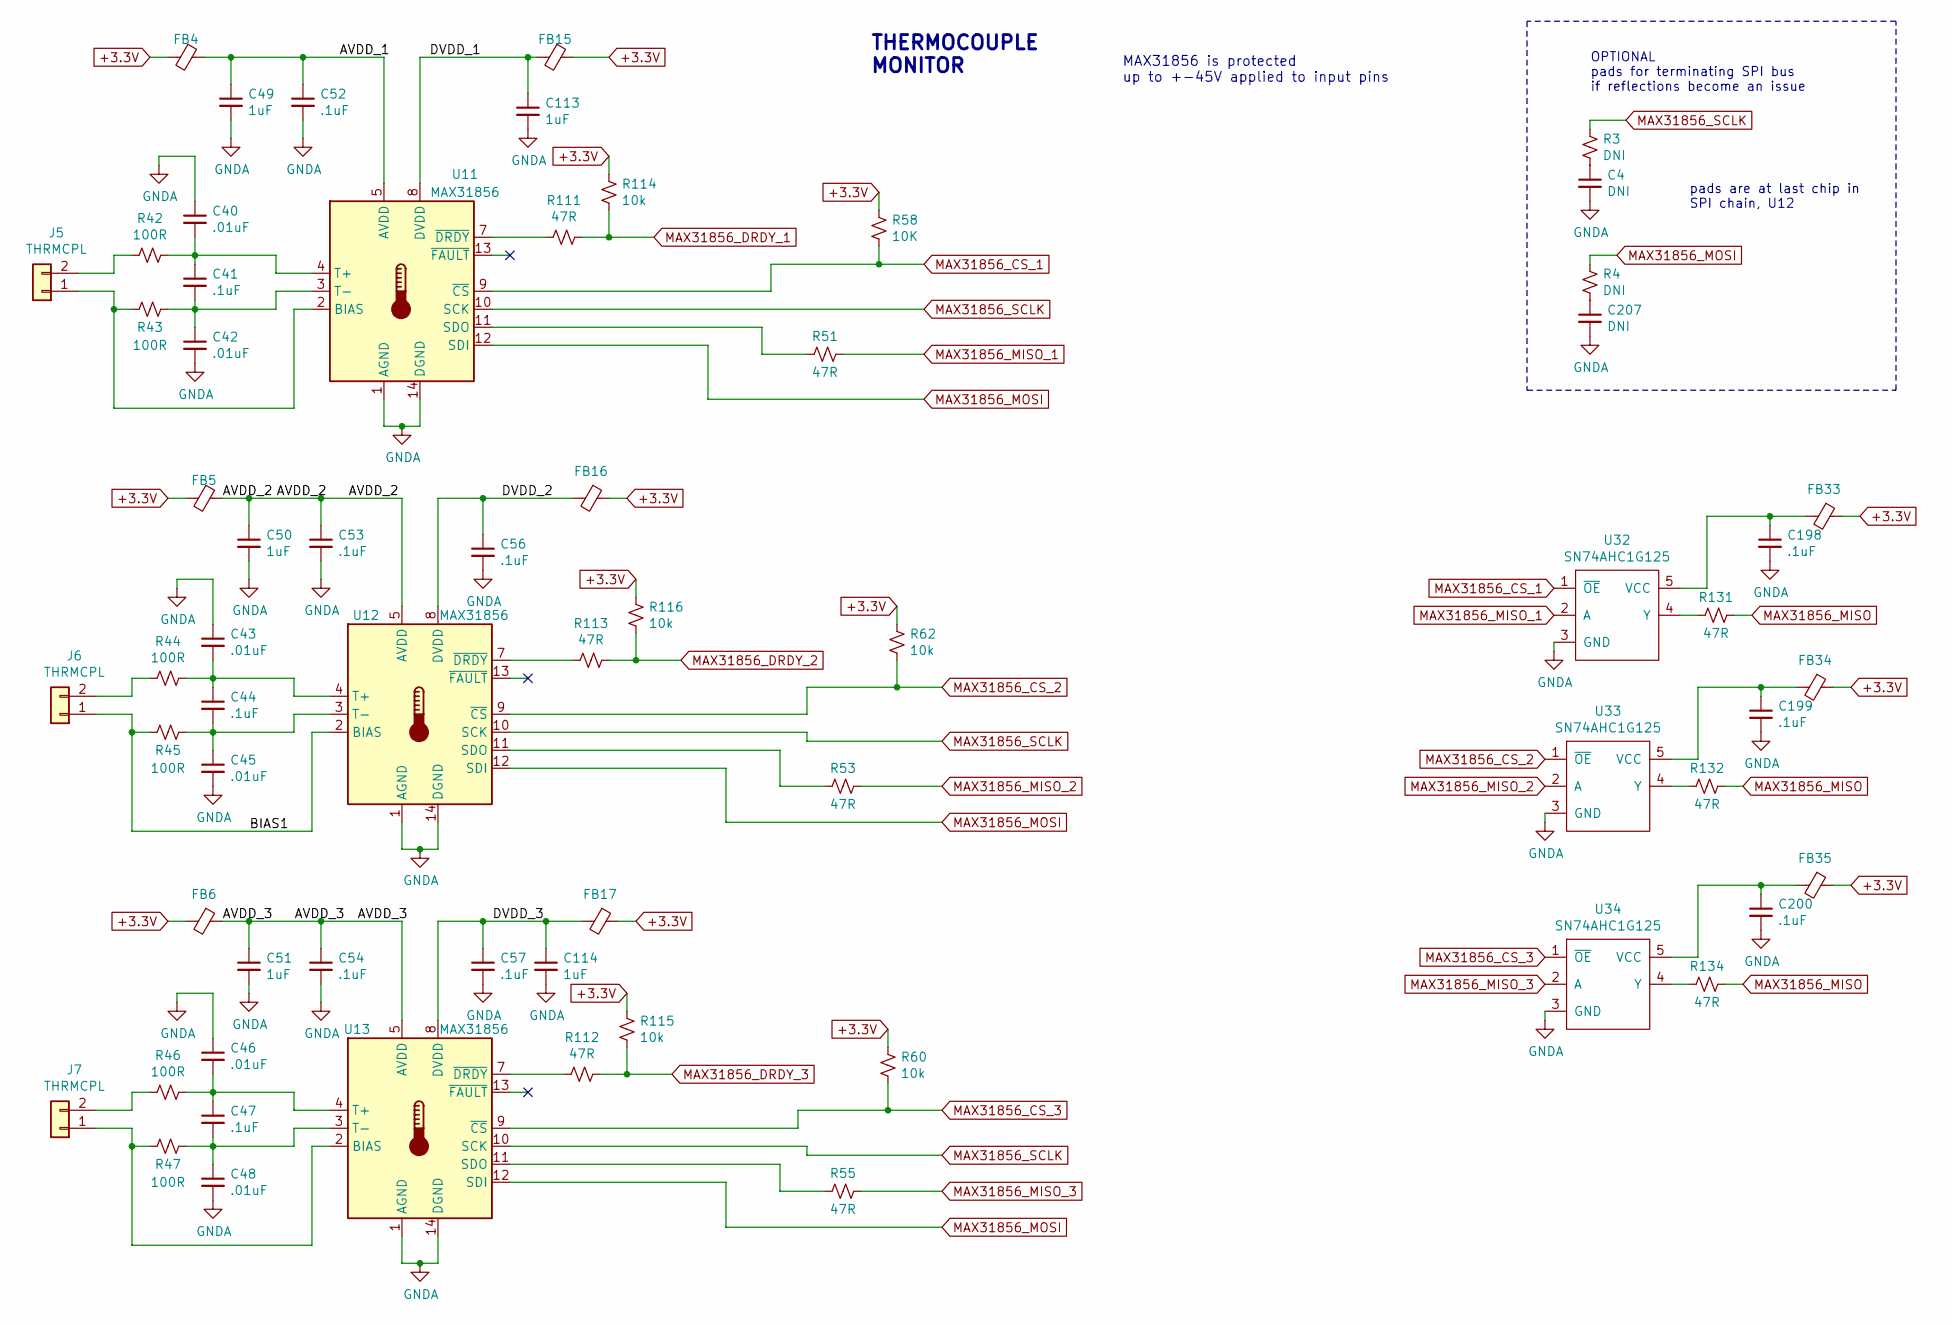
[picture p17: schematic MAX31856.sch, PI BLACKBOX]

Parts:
C4, C207: DNI; C_0603_1608Metric_Pad1.05x0.95mm_HandSolder
C40, C42, C43, C45, C46, C48: .01uF; C_0402_1005Metric
C41, C52, C53, C54, C56, C57: .1uF; C_0603_1608Metric_Pad1.05x0.95mm_HandSolder
C44, C47, C198, C199, C200: .1uF; C_0402_1005Metric
C49, C50, C51, C113, C114: 1uF; C_0603_1608Metric_Pad1.05x0.95mm_HandSolder
FB4, FB5, FB6, FB15, FB16, FB17: FB; R_0805_2012Metric_Pad1.15x1.40mm_HandSolder
FB33, FB34, FB35: FB; R_0402_1005Metric
J5, J6, J7: THRMCPL; Thermocouple_Connect
R3, R4: DNI; R_0603_1608Metric_Pad1.05x0.95mm_HandSolder
R42, R43, R44, R45, R46, R47: 100R; R_0402_1005Metric
R51, R53, R55, R111, R112, R113, R131, R132, R134: 47R; R_0402_1005Metric
R58: 10K; R_0402_1005Metric
R60, R62, R114, R115, R116: 10k; R_0402_1005Metric
U11, U12, U13: MAX31856; TSSOP-14_4.4x5mm_P0.65mm
U32, U33, U34: SN74AHC1G125; SOT-23-5_HandSoldering

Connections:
+3.3V: FB4.2, FB5.2, FB6.2, FB15.1, FB16.1, FB17.1, FB33.1, FB34.1, FB35.1, R58.1, R60.1, R62.1, R114.1, R115.1, R116.1; also elsewhere on the board
/MAX31856/AVDD_1: C49.1, C52.1, FB4.1, U11.5 (AVDD)
/MAX31856/AVDD_2: C50.1, C53.1, FB5.1, U12.5 (AVDD)
/MAX31856/AVDD_3: C51.1, C54.1, FB6.1, U13.5 (AVDD)
/MAX31856/BIAS1: J6.1, R45.2, U12.2 (BIAS)
/MAX31856/DVDD_1: C113.1, FB15.2, U11.8 (DVDD)
/MAX31856/DVDD_2: C56.1, FB16.2, U12.8 (DVDD)
/MAX31856/DVDD_3: C57.1, C114.1, FB17.2, U13.8 (DVDD)
DAC_MOSI: R4.1, U11.12 (SDI), U12.12 (SDI), U13.12 (SDI); also elsewhere on the board
DAC_SCLK: R3.1, U11.10 (SCK), U12.10 (SCK), U13.10 (SCK); also elsewhere on the board
GNDA: C4.2, C40.1, C42.2, C43.1, C45.2, C46.1, C48.2, C49.2, C50.2, C51.2, C52.2, C53.2, C54.2, C56.2, C57.2, C113.2, C114.2, C198.2, C199.2, C200.2, C207.2, U11.1 (AGND), U11.14 (DGND), U12.1 (AGND), U12.14 (DGND), U13.1 (AGND), U13.14 (DGND), U32.3 (GND), U33.3 (GND), U34.3 (GND); also elsewhere on the board
MAX31856_CS_1: R58.2, U11.9 (~CS), U32.1 (~OE); also elsewhere on the board
MAX31856_CS_2: R62.2, U12.9 (~CS), U33.1 (~OE); also elsewhere on the board
MAX31856_CS_3: R60.2, U13.9 (~CS), U34.1 (~OE); also elsewhere on the board
MAX31856_DRDY_1: R111.1, R114.2; also elsewhere on the board
MAX31856_DRDY_2: R113.1, R116.2; also elsewhere on the board
MAX31856_DRDY_3: R112.1, R115.2; also elsewhere on the board
MAX31856_MISO: R131.1, R132.1, R134.1; also elsewhere on the board
MAX31856_MISO_1: R51.1, U32.2 (A)
MAX31856_MISO_2: R53.1, U33.2 (A)
MAX31856_MISO_3: R55.1, U34.2 (A)
unnamed: C4.1, R3.2
unnamed: C40.2, C41.1, R42.1, U11.4 (T+)
unnamed: C41.2, C42.1, R43.1, U11.3 (T-)
unnamed: C43.2, C44.1, R44.1, U12.4 (T+)
unnamed: C44.2, C45.1, R45.1, U12.3 (T-)
unnamed: C46.2, C47.1, R46.1, U13.4 (T+)
unnamed: C47.2, C48.1, R47.1, U13.3 (T-)
unnamed: C198.1, FB33.2, U32.5 (VCC)
unnamed: C199.1, FB34.2, U33.5 (VCC)
unnamed: C200.1, FB35.2, U34.5 (VCC)
unnamed: C207.1, R4.2
unnamed: J5.1, R43.2, U11.2 (BIAS)
unnamed: J5.2, R42.2
unnamed: J6.2, R44.2
unnamed: J7.1, R47.2, U13.2 (BIAS)
unnamed: J7.2, R46.2
unnamed: R51.2, U11.11 (SDO)
unnamed: R53.2, U12.11 (SDO)
unnamed: R55.2, U13.11 (SDO)
unnamed: R111.2, U11.7 (~DRDY)
unnamed: R112.2, U13.7 (~DRDY)
unnamed: R113.2, U12.7 (~DRDY)
unnamed: R131.2, U32.4 (Y)
unnamed: R132.2, U33.4 (Y)
unnamed: R134.2, U34.4 (Y)

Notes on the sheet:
MAX31856 is protected up to +-45V applied to input pins
THERMOCOUPLE MONITOR
OPTIONAL pads for terminating SPI bus if reflections become an issue
pads are at last chip in SPI chain, U12

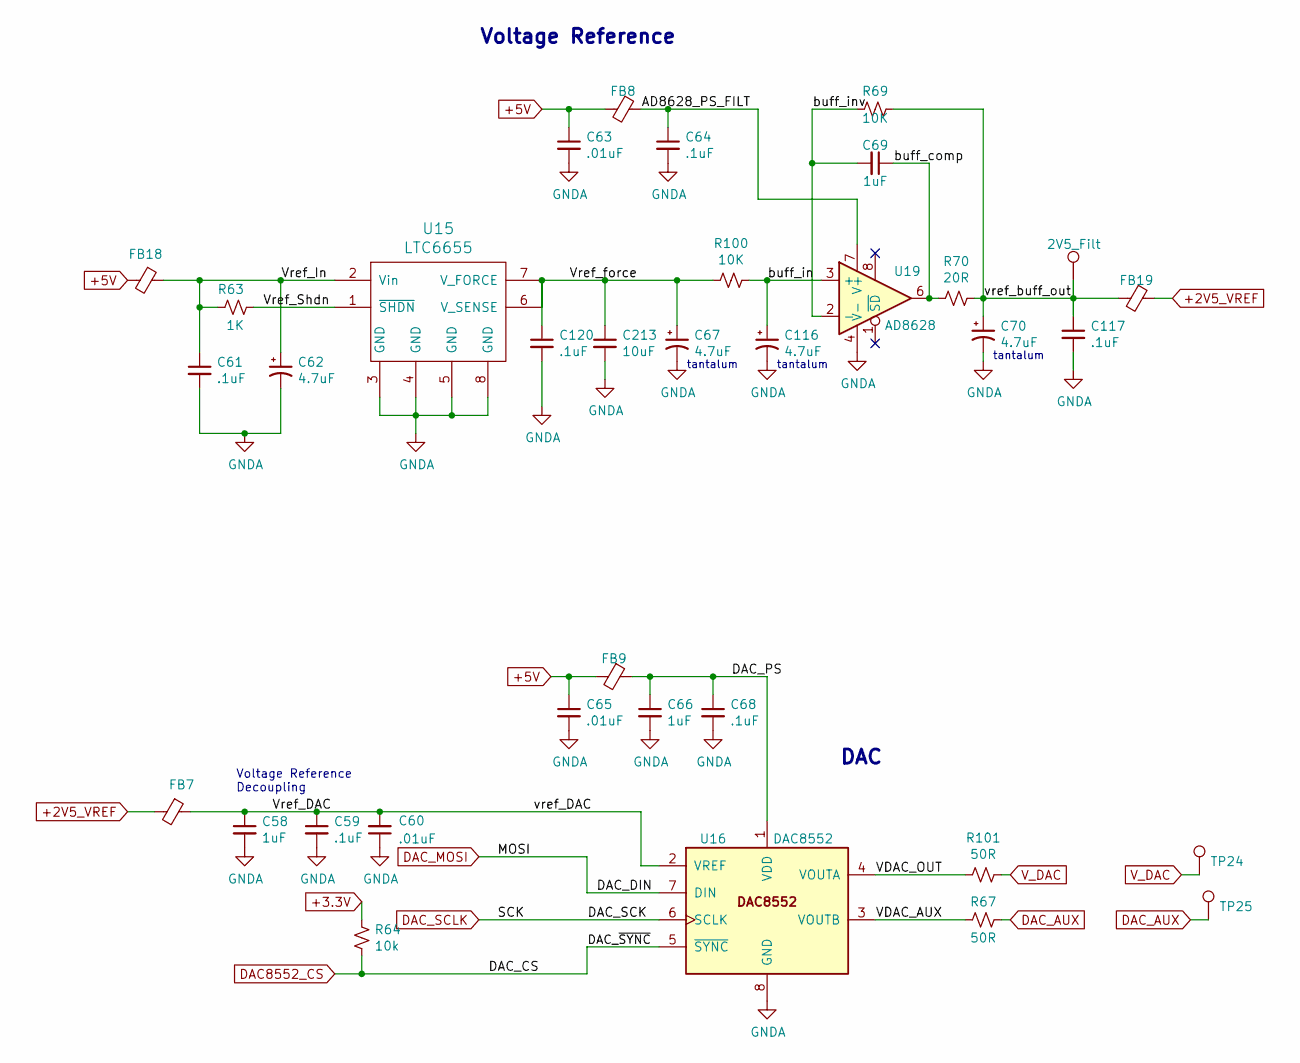
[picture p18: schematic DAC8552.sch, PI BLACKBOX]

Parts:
C58, C66, C69: 1uF; C_0805_2012Metric_Pad1.15x1.40mm_HandSolder
C59, C61, C64, C68, C117, C120: .1uF; C_0603_1608Metric_Pad1.05x0.95mm_HandSolder
C60, C63, C65: .01uF; C_0603_1608Metric_Pad1.05x0.95mm_HandSolder
C62, C67, C70, C116: 4.7uF; CP_EIA-3528-21_Kemet-B_Pad1.50x2.35mm_HandSolder
C213: 10uF; C_0805_2012Metric_Pad1.15x1.40mm_HandSolder
FB7, FB8, FB9, FB19: FB; R_0805_2012Metric_Pad1.15x1.40mm_HandSolder
FB18: FB; L_0805_2012Metric_Pad1.15x1.40mm_HandSolder
R63: 1K; R_0402_1005Metric
R64: 10k; R_0402_1005Metric
R67, R101: 50R; R_0402_1005Metric
R69: 10K; R_0603_1608Metric_Pad1.05x0.95mm_HandSolder
R70: 20R; R_0805_2012Metric_Pad1.15x1.40mm_HandSolder
R100: 10K; R_0402_1005Metric
TP23: 2V5_Filt; TestPoint_SMT_Keystone_5190
TP24: VDAC; TestPoint_SMT_Keystone_5190
TP25: DAC_AUX; TestPoint_Pad_D1.5mm
U15: LTC6655; LTC6655_LS8
U16: DAC8552; VSSOP-8_3.0x3.0mm_P0.65mm
U19: AD8628; SOIC-8_5.275x5.275mm_P1.27mm

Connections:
+2V5_VREF: FB7.2, FB19.1; also elsewhere on the board
+3.3V: R64.1; also elsewhere on the board
+5V: C63.1, C65.1, FB8.2, FB9.2, FB18.2; also elsewhere on the board
/DAC8552/AD8628_PS_FILT: C64.1, FB8.1, U19.7 (V+)
/DAC8552/DAC_PS: C66.1, C68.1, FB9.1, U16.1 (VDD)
/DAC8552/VDAC_AUX: R67.2, U16.3 (VOUTB)
/DAC8552/VDAC_OUT: R101.2, U16.4 (VOUTA)
/DAC8552/Vref_DAC: C58.1, C59.1, C60.2, FB7.1, U16.2 (VREF)
/DAC8552/Vref_In: C61.1, C62.1, FB18.1, R63.1, U15.2 (Vin)
/DAC8552/Vref_Shdn: R63.2, U15.1 (~SHDN)
/DAC8552/Vref_force: C67.1, C120.1, C213.1, R100.2, U15.6 (V_SENSE), U15.7 (V_FORCE)
/DAC8552/buff_comp: C69.1, R70.2, U19.6
/DAC8552/buff_in: C116.1, R100.1, U19.3 (+)
/DAC8552/buff_inv: C69.2, R69.2, U19.2 (-)
/DAC8552/vref_buff_out: C70.1, C117.1, FB19.2, R69.1, R70.1, TP23.1
DAC8552_CS: R64.2, U16.5 (~SYNC); also elsewhere on the board
DAC_AUX: R67.1, TP25.1
DAC_MOSI: U16.7 (DIN); also elsewhere on the board
DAC_SCLK: U16.6 (SCLK); also elsewhere on the board
GNDA: C58.2, C59.2, C60.1, C61.2, C62.2, C63.2, C64.2, C65.2, C66.2, C67.2, C68.2, C70.2, C116.2, C117.2, C120.2, C213.2, U15.3 (GND), U15.4 (GND), U15.5 (GND), U15.8 (GND), U16.8 (GND), U19.4 (V-); also elsewhere on the board
V_DAC: R101.1, TP24.1; also elsewhere on the board

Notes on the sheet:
Voltage Reference
DAC
Voltage Reference Decoupling
tantalum

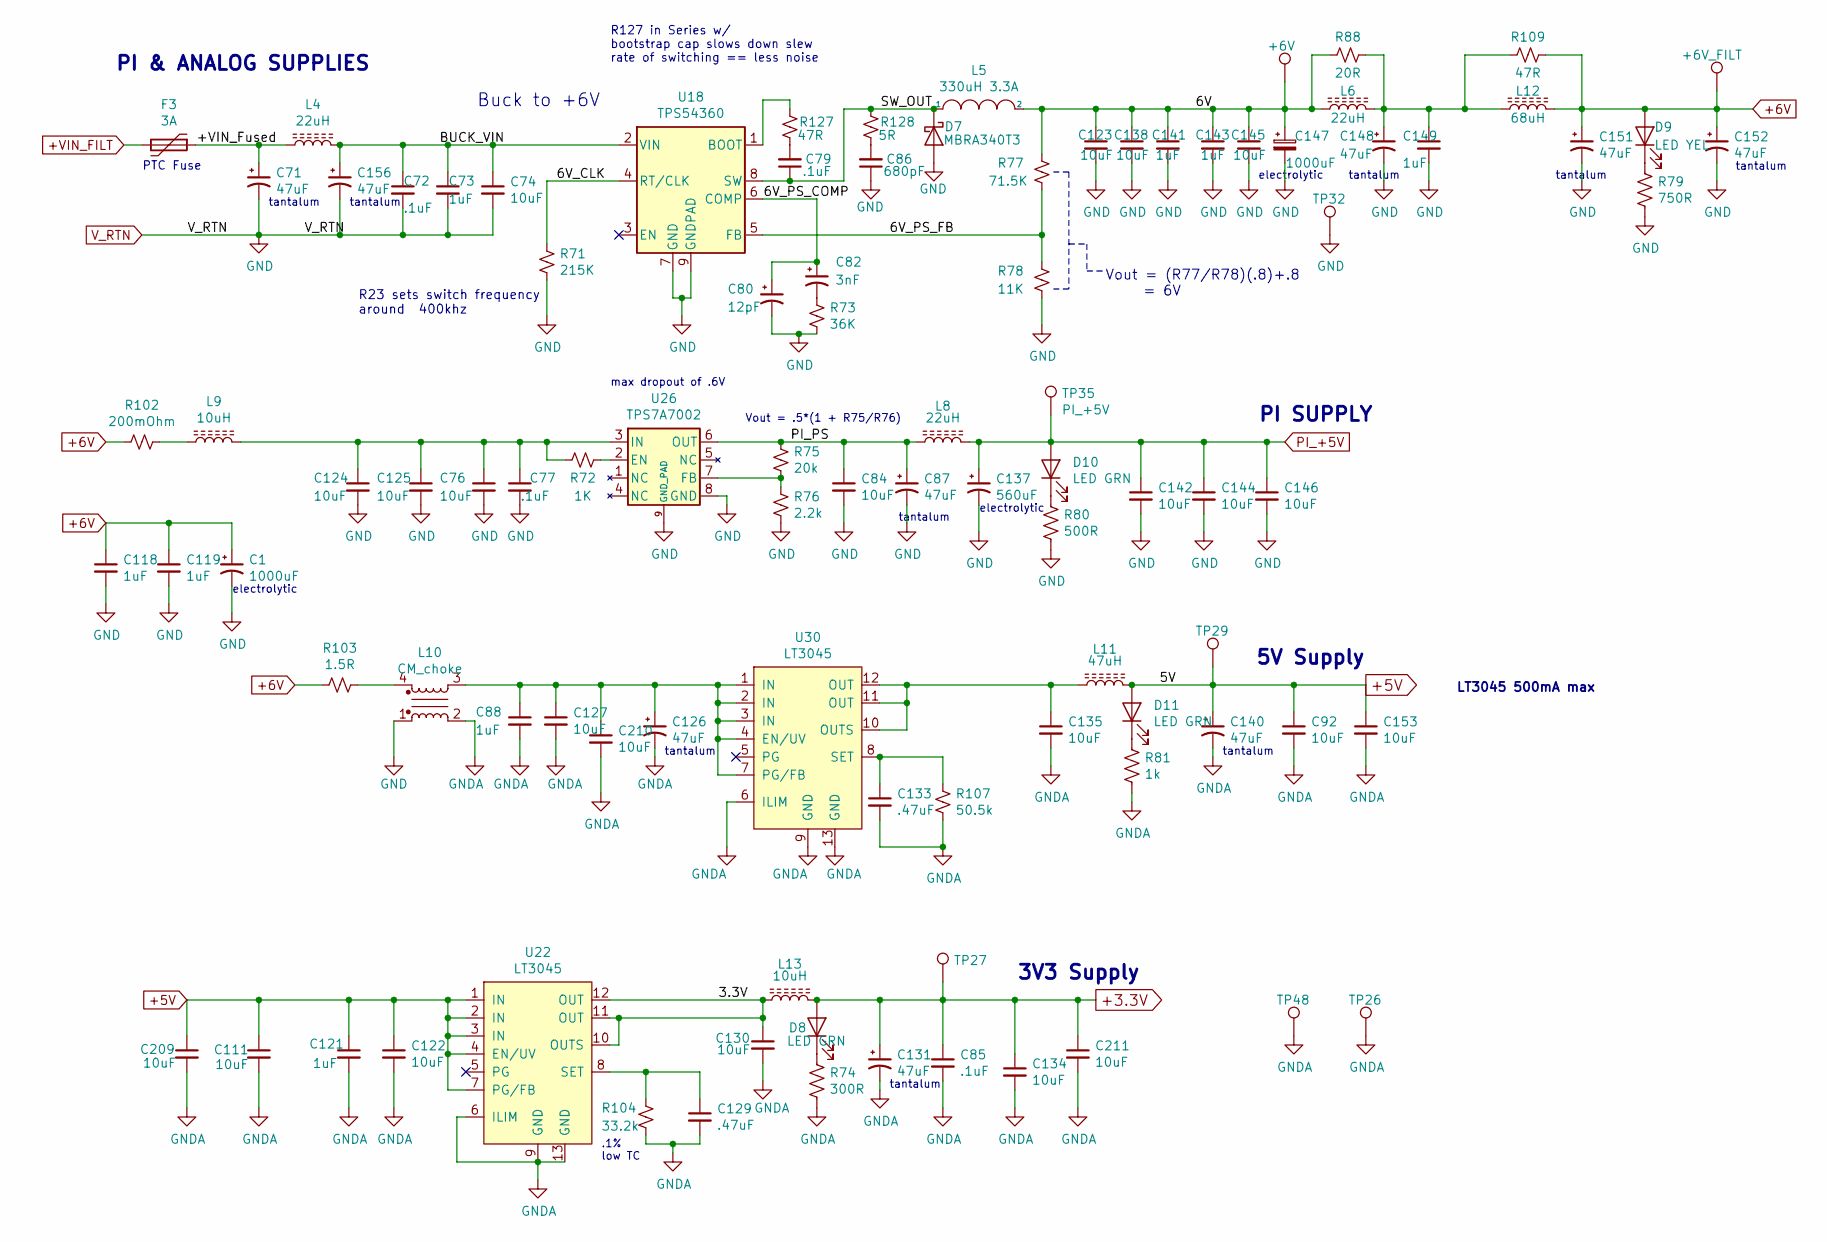
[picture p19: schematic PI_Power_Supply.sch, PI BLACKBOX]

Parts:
C1: 1000uF; CP_Radial_D12.5mm_P5.00mm; MFG Part # EEU-FR1V102B
C71, C87, C126, C131, C140, C148, C151, C152, C156: 47uF; T495X476K035ATE300
C72, C77: .1uF; C_0603_1608Metric_Pad1.05x0.95mm_HandSolder
C73, C88, C118, C119, C141, C143, C149: 1uF; C_0805_2012Metric_Pad1.15x1.40mm_HandSolder
C74, C76, C84, C92, C123, C124, C125, C127, C130, C134, C135, C138, C142, C144, C145, C146, C153: 10uF; C_1206_3216Metric_Pad1.42x1.75mm_HandSolder
C79: .1uF; C_0805_2012Metric_Pad1.15x1.40mm_HandSolder
C80: 12pF; C_0603_1608Metric_Pad1.05x0.95mm_HandSolder
C82: 3nF; C_0603_1608Metric_Pad1.05x0.95mm_HandSolder
C85: .1uF; R_0603_1608Metric_Pad1.05x0.95mm_HandSolder
C86: 680pF; C_0603_1608Metric_Pad1.05x0.95mm_HandSolder
C111, C122, C209, C210, C211: 10uF; C_0805_2012Metric_Pad1.15x1.40mm_HandSolder
C121: 1uF; C_0603_1608Metric_Pad1.05x0.95mm_HandSolder
C129, C133: .47uF; C_0402_1005Metric
C137: 560uF; CP_Radial_D10.0mm_P5.00mm
C147: 1000uF; CP_Radial_D12.5mm_P5.00mm
D7: MBRA340T3; MBRA430T
D8, D10, D11: LED GRN; LED_0805_2012Metric_Pad1.15x1.40mm_HandSolder
D9: LED YEL; LED_0805_2012Metric_Pad1.15x1.40mm_HandSolder
F3: 3A; Fuse_2920
L4: 22uH; L_Bourns_SRP1038
L5: 330uH 3.3A; Murata1433433C
L6, L8: 22uH; Sumida_CDRH105
L9: 10uH; 10uH_Wurth_74479887310A
L10: CM_choke; CM_Choke_EPCOS_B82720K
L11: 47uH; RLB9012-470KL
L12: 68uH; L_Wuerth_WE-PD
L13: 10uH; L_1210_3225Metric_Pad1.42x2.65mm_HandSolder
R71: 215K; R_0603_1608Metric_Pad1.05x0.95mm_HandSolder
R72: 1K; R_0402_1005Metric
R73: 36K; R_0603_1608Metric_Pad1.05x0.95mm_HandSolder
R74: 300R; R_0402_1005Metric
R75: 20k; R_0603_1608Metric_Pad1.05x0.95mm_HandSolder
R76: 2.2k; R_0603_1608Metric_Pad1.05x0.95mm_HandSolder
R77: 71.5K; R_0603_1608Metric_Pad1.05x0.95mm_HandSolder
R78: 11K; R_0603_1608Metric_Pad1.05x0.95mm_HandSolder
R79: 750R; R_0402_1005Metric
R80: 500R; R_0402_1005Metric
R81: 1k; R_0402_1005Metric
R88: 20R; R_1210_3225Metric_Pad1.42x2.65mm_HandSolder
R102: 200mOhm; R_1206_3216Metric_Pad1.42x1.75mm_HandSolder
R103: 1.5R; R_1206_3216Metric_Pad1.42x1.75mm_HandSolder
R104: 33.2k; R_0402_1005Metric
R107: 50.5k; R_0603_1608Metric_Pad1.05x0.95mm_HandSolder
R109: 47R; R_1210_3225Metric_Pad1.42x2.65mm_HandSolder
R127: 47R; R_0603_1608Metric_Pad1.05x0.95mm_HandSolder
R128: 5R; R_0805_2012Metric_Pad1.15x1.40mm_HandSolder
TP16: +6V_FILT; TestPoint_SMT_Keystone_5190
TP26, TP48: GNDA; TestPoint_SMT_Keystone_5190
TP27: +3V3; TestPoint_SMT_Keystone_5190
TP28: +6V; TestPoint_SMT_Keystone_5190
TP29: +5V_FILT; TestPoint_SMT_Keystone_5190
TP32: GND; TestPoint_SMT_Keystone_5190
TP35: PI_+5V; TestPoint_SMT_Keystone_5190
U18: TPS54360; Power_Pad_SO
U22, U30: LT3045; MSOP-12-1EP_3x4mm_P0.65mm_EP1.65x2.85mm_ThermalVias
U26: TPS7A7002; SOIC-8-1EP_3.9x4.9mm_P1.27mm_EP2.514x3.2mm_ThermalVias

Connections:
+3.3V: C85.1, C131.1, C134.1, C211.1, D8.2 (A), L13.2, TP27.1; also elsewhere on the board
+5V: C92.1, C111.1, C121.1, C122.1, C140.1, C153.1, C209.1, D11.2 (A), L11.2, TP29.1, U22.1 (IN), U22.2 (IN), U22.3 (IN), U22.4 (EN/UV), U22.7 (PG/FB); also elsewhere on the board
+6V: C1.1, C118.1, C119.1, C151.1, C152.1, D9.2 (A), L12.2, R102.2, R103.2, R109.1, TP16.1; also elsewhere on the board
+VIN_FILT: F3.2; also elsewhere on the board
/PI_Power_Supply/3.3V: C130.1, L13.1, U22.10 (OUTS), U22.11 (OUT), U22.12 (OUT)
/PI_Power_Supply/6V: C123.1, C138.1, C141.1, C143.1, C145.1, C147.1, L5.2, L6.1, R77.1, R88.2, TP28.1
/PI_Power_Supply/6V_CLK: R71.1, U18.4 (RT/CLK)
/PI_Power_Supply/6V_PS_COMP: C80.1, C82.1, U18.6 (COMP)
/PI_Power_Supply/6V_PS_FB: R77.2, R78.1, U18.5 (FB)
/PI_Power_Supply/+VIN_Fused: C71.1, F3.1, L4.1
/PI_Power_Supply/BUCK_VIN: C72.1, C73.1, C74.1, C156.1, L4.2, U18.2 (VIN)
/PI_Power_Supply/PI_PS: C84.1, C87.1, L8.1, R75.1, U26.6 (OUT)
/PI_Power_Supply/SW_OUT: C79.1, D7.1 (K), L5.1, R128.1, U18.8 (SW)
GND: C1.2, C71.2, C72.2, C73.2, C74.2, C76.2, C77.2, C80.2, C84.2, C86.1, C87.2, C118.2, C119.2, C123.2, C124.2, C125.2, C137.2, C138.2, C141.2, C142.2, C143.2, C144.2, C145.2, C146.2, C147.2, C148.2, C149.2, C151.2, C152.2, C156.2, D7.2 (A), L10.1, R71.2, R73.2, R76.2, R78.2, R79.2, R80.2, TP32.1, U18.7 (GND), U18.9 (GNDPAD), U26.8 (GND), U26.9 (GND_PAD); also elsewhere on the board
GNDA: C85.2, C88.2, C92.2, C111.2, C121.2, C122.2, C126.2, C127.2, C129.2, C130.2, C131.2, C133.2, C134.2, C135.2, C140.2, C153.2, C209.2, C210.2, C211.2, L10.2, R74.2, R81.2, R104.2, R107.2, TP26.1, TP48.1, U22.6 (ILIM), U22.9 (GND), U22.13 (GND), U30.6 (ILIM), U30.9 (GND), U30.13 (GND); also elsewhere on the board
unnamed: C79.2, R127.2
unnamed: C82.2, R73.1
unnamed: C86.2, R128.2
unnamed: C76.1, C77.1, C124.1, C125.1, L9.2, R72.2, U26.3 (IN)
unnamed: C88.1, C126.1, C127.1, C210.1, L10.3, U30.1 (IN), U30.2 (IN), U30.3 (IN), U30.4 (EN/UV), U30.7 (PG/FB)
unnamed: C129.1, R104.1, U22.8 (SET)
unnamed: C133.1, R107.1, U30.8 (SET)
unnamed: C135.1, L11.1, U30.10 (OUTS), U30.11 (OUT), U30.12 (OUT)
unnamed: C148.1, C149.1, L6.2, L12.1, R88.1, R109.2
unnamed: D8.1 (K), R74.1
unnamed: D9.1 (K), R79.1
unnamed: D10.1 (K), R80.1
unnamed: D11.1 (K), R81.1
unnamed: L9.1, R102.1
unnamed: L10.4, R103.1
unnamed: R72.1, U26.2 (EN)
unnamed: R75.2, R76.1, U26.7 (FB)
unnamed: R127.1, U18.1 (BOOT)
PI_+5V: C137.1, C142.1, C144.1, C146.1, D10.2 (A), L8.2, TP35.1; also elsewhere on the board

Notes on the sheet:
Vout = (R77/R78)(.8)+.8 = 6V
R23 sets switch frequency around 400khz
3V3 Supply
Buck to +6V
PTC Fuse
PI & ANALOG SUPPLIES
Vout = .5*(1 + R75/R76)
PI SUPPLY
tantalum
max dropout of .6V
.1% low TC
electrolytic
R127 in Series w/ bootstrap cap slows down slew rate of switching == less noise
LT3045 500mA max
5V Supply

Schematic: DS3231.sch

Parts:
BT1: Battery_Holder; BatteryHolder_Keystone_1058_2032; MFG Part # 1058
C160, C168: 0.1uF; C_0603_1608Metric_Pad1.05x0.95mm_HandSolder
FB26: ferrite; R_0603_1608Metric_Pad1.05x0.95mm_HandSolder
R121, R122: 22R; R_0402_1005Metric
R123, R124: 2k; R_0402_1005Metric
R125, R126: 10k; R_0402_1005Metric
U29: DS3231MZ+; SOIC-8_W3.9mm; MPN DS3231MZ/V+; Digi-Key_PN DS3231MZ/V+-ND

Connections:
+3.3V: FB26.2, R123.1, R124.1, R125.1, R126.1; also elsewhere on the board
GNDA: BT1.2 (-), C160.2, C168.2, U29.5 (GND); also elsewhere on the board
unnamed: C160.1, FB26.1, U29.2 (VCC)
unnamed: R121.1, R124.2, U29.7 (SDA)
unnamed: R122.1, R123.2, U29.8 (SCL)
unnamed: R125.2, U29.3 (~INT~/SQW)
unnamed: R126.2, U29.1 (32KHZ)
PI_SCL: R122.2; also elsewhere on the board
PI_SDA: R121.2; also elsewhere on the board
VBat: BT1.1 (+), C168.1, U29.6 (VBAT); also elsewhere on the board

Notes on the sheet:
REAL TIME CLOCK DS3231

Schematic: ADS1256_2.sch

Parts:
C181: 4.7uF; CP_EIA-3528-21_Kemet-B_Pad1.50x2.35mm_HandSolder
C182, C184, C208: 1uF; C_0603_1608Metric_Pad1.05x0.95mm_HandSolder
C183, C186, C188, C190, C191: .1uF; C_0603_1608Metric_Pad1.05x0.95mm_HandSolder
C185: .1uF; C_0805_2012Metric_Pad1.15x1.40mm_HandSolder
C187, C189: 1uF; R_0603_1608Metric_Pad1.05x0.95mm_HandSolder
C192, C193: 20pF; C_0603_1608Metric_Pad1.05x0.95mm_HandSolder
L16, L17: 10uH; MLZ2012N100LT000
R130, R138: 2k; R_0402_1005Metric
R133: 10k; R_0402_1005Metric
R136, R137: 47R; R_0402_1005Metric
U31: ADS1256; SSOP-28_5.3x10.2mm_P0.65mm
Y2: 7.68 Mhz; Crystal_SMD_TXC

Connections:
+2V5_VREF: C181.1, C182.1, C183.1, U31.4 (VREFP); also elsewhere on the board
+3.3V: C184.1, L16.1, R130.1, R133.1, R138.1; also elsewhere on the board
+5V: C186.1, L17.1; also elsewhere on the board
/ADS1256_2/ADS2_AVDD: C188.1, C189.1, C191.1, L17.2, U31.1 (AVDD)
/ADS1256_2/ADS2_DRDY2: R136.2, U31.21 (~DRDY)
/ADS1256_2/ADS2_DVDD: C187.1, C190.1, L16.2, U31.16 (DVDD)
/ADS1256_2/ADS2_MISO2: R137.2, U31.22 (DOUT)
ADS1256_MISO: R137.1; also elsewhere on the board
ADS1256_MOSI: U31.23 (DIN); also elsewhere on the board
ADS1256_SCLK: U31.24 (SCLK); also elsewhere on the board
COOL_PWR_I: C208.1, U31.6 (AIN0); also elsewhere on the board
CRYSTALA: C192.1, U31.19 (XTAL1/CLKIN), Y2.2
CRYSTALB: C193.1, U31.18 (XTAL2), Y2.1
GNDA: C181.2, C182.2, C183.2, C184.2, C186.2, C187.2, C188.2, C189.2, C190.2, C191.2, C192.2, C193.2, C208.2, U31.2 (AGND), U31.3 (VREFN), U31.5 (AINCOM), U31.7 (AIN1), U31.11 (AIN5), U31.13 (AIN7), U31.17 (DGND); also elsewhere on the board
HEAT_LOAD_I: U31.10 (AIN4); also elsewhere on the board
HEAT_LOAD_V: U31.12 (AIN6); also elsewhere on the board
TEMP_DIODE: C185.1, U31.8 (AIN2); also elsewhere on the board
TEMP_DIODE_RTN: C185.2, U31.9 (AIN3); also elsewhere on the board
~ADS1256_CS_1: R130.2, U31.20 (~CS); also elsewhere on the board
~ADS1256_RESET: R133.2, U31.15 (~RESET); also elsewhere on the board
~ADS1265_DRDY2: R136.1, R138.2; also elsewhere on the board

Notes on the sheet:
ADC
Analog Inputs

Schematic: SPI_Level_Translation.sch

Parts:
C201, C202, C203, C204, C205, C206: 0.1uF; C_0603_1608Metric_Pad1.05x0.95mm_HandSolder
R5, R6, R7, R147: 10k; R_0402_1005Metric
R135, R139, R140, R141, R142, R143, R144, R145, R146: 47R; R_0402_1005Metric
TP5: MISO_1; TestPoint_SMT_Keystone_5190
TP7: MOSI_1; TestPoint_SMT_Keystone_5190
TP8: SCLK_0; TestPoint_SMT_Keystone_5190
TP9: SCLK_1; TestPoint_SMT_Keystone_5190
TP10: MOSI_0; TestPoint_SMT_Keystone_5190
TP11: GND; TestPoint_SMT_Keystone_5190
TP12: MISO_0; TestPoint_SMT_Keystone_5190
TP50: PI_SCLK_0; TestPoint_SMT_Keystone_5190
U35, U36, U37: SN74HC125; SN74LVC125APWR; MPN SN74HC125A; Digi-Key_PN 296-1222-1-ND

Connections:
+3.3V: C201.1, C202.1, C203.1, C204.1, C205.1, C206.1, R5.1, R6.1, R7.1, R147.1, U35.14 (VCC), U36.14 (VCC), U37.14 (VCC); also elsewhere on the board
ADS1256_MISO: TP12.1, U35.12 (4A); also elsewhere on the board
ADS1256_MOSI: R142.1, TP10.1; also elsewhere on the board
ADS1256_SCLK: R141.1, TP8.1; also elsewhere on the board
DAC_MOSI: R144.1, R146.1; also elsewhere on the board
DAC_SCLK: R143.1, R145.1; also elsewhere on the board
GND: C201.2, C202.2, C203.2, C204.2, C205.2, C206.2, TP11.1, U35.7 (GND), U36.7 (GND), U37.7 (GND); also elsewhere on the board
MAX31856_MISO: U36.12 (4A), U37.12 (4A); also elsewhere on the board
unnamed: R135.1, U35.11 (4Y)
unnamed: R139.1, U36.11 (4Y)
unnamed: R140.1, TP5.1, U37.11 (4Y)
unnamed: R141.2, U35.3 (1Y)
unnamed: R142.2, U35.6 (2Y)
unnamed: R143.2, U36.3 (1Y)
unnamed: R144.2, U36.6 (2Y)
unnamed: R145.2, U37.3 (1Y)
unnamed: R146.2, U37.6 (2Y)
PI_MISO_0: R135.2, R139.2; also elsewhere on the board
PI_MISO_1: R140.2; also elsewhere on the board
PI_MOSI_0: U35.5 (2A), U36.5 (2A); also elsewhere on the board
PI_MOSI_1: TP7.1, U37.5 (2A); also elsewhere on the board
PI_SCLK_0: TP50.1, U35.2 (1A), U36.2 (1A); also elsewhere on the board
PI_SCLK_1: TP9.1, U37.2 (1A); also elsewhere on the board
~BUF_EN_0: R7.2, R147.2, U35.1 (~1OE), U35.4 (~2OE), U35.13 (~4OE); also elsewhere on the board
~BUF_EN_1: R5.2, U36.1 (~1OE), U36.4 (~2OE), U36.13 (~4OE); also elsewhere on the board
~BUF_EN_2: R6.2, U37.1 (~1OE), U37.4 (~2OE), U37.13 (~4OE); also elsewhere on the board

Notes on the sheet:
turn on when ads1 or ads2 CS goes low

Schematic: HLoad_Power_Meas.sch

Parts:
C13: 1.5uF; C_1210_3225Metric_Pad1.42x2.65mm_HandSolder
C157, C158: 0.1uF; C_0603_1608Metric_Pad1.05x0.95mm_HandSolder
C161: 1uF; C_0603_1608Metric_Pad1.05x0.95mm_HandSolder
C162: .1uF; C_0402_1005Metric
C163, C164, C167: 1uF; C_1210_3225Metric_Pad1.42x2.65mm_HandSolder
C165: 10uF; C_0805_2012Metric_Pad1.15x1.40mm_HandSolder
C166: .1uF; C_0603_1608Metric_Pad1.05x0.95mm_HandSolder
FB11, FB21, FB22, FB23: FB; R_0603_1608Metric_Pad1.05x0.95mm_HandSolder
R15: 1 kΩ; R_0402_1005Metric
R16: 1KΩ; R_0402_1005Metric
R17: 100 Ω; R_0402_1005Metric
R18: 1KΩ; R_0603_1608Metric_Pad1.05x0.95mm_HandSolder
R83: 100 Ω; R_0603_1608Metric_Pad1.05x0.95mm_HandSolder
TP34, TP36: test_pad; Probe_Test_Pad
U4: AD8278; SOIC-8_5.23x5.23mm_P1.27mm
U5: LT5400; MSOP-8_3x3mm_P0.65mm
U25: AD8417; SOIC-8_3.9x4.9mm_P1.27mm
U27, U28: AD8628; SOIC-8_3.9x4.9mm_P1.27mm
VLoad/4, VLoad/8: Jumper; SolderJumper-2_P1.3mm_Open_RoundedPad1.0x1.5mm

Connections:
+5V: FB21.1, FB22.1, FB23.1; also elsewhere on the board
/Heat_Load/HLoad: U25.8 (IN+); also elsewhere on the board
/Heat_Load/HLoad_Power_Meas/GUARD: C165.2, R18.2, U28.2 (-)
/Heat_Load/HLoad_Power_Meas/GUARD2: C161.2, R16.2, U27.2 (-)
/Heat_Load/HLoad_Power_Meas/I_Load: R15.2, U25.5 (OUT)
/Heat_Load/HLoad_Power_Meas/VLoad_div2: U4.5, U4.6, U5.1 (R1_in)
/Heat_Load/HLoad_Power_Meas/V_div4: TP34.1, U5.2 (R2_in), U5.3 (R3_in), VLoad/4.1
/Heat_Load/HLoad_Power_Meas/V_div8: TP36.1, U5.5 (R4_out), U5.6 (R3_out), VLoad/8.1
GND: C13.1, U4.2, U4.4 (V-); also elsewhere on the board
GNDA: C157.2, C158.2, C162.2, C163.2, C164.2, C166.2, C167.2, U4.1, U5.4 (R4_in), U25.2 (GND), U25.3 (REF2), U25.7 (REF1), U27.4 (V-), U28.4 (V-); also elsewhere on the board
HEAT_LOAD_I: C164.1, R16.1, R17.1; also elsewhere on the board
HEAT_LOAD_P: C13.2, U4.3, U25.1 (IN-); also elsewhere on the board
HEAT_LOAD_V: C167.1, R18.1, R83.1; also elsewhere on the board
LOAD_PS: FB11.1; also elsewhere on the board
unnamed: C157.1, FB11.2, U4.7 (V+)
unnamed: C158.1, FB21.2, U25.6 (VS)
unnamed: C161.1, R17.2, U27.6
unnamed: C162.1, FB22.2, U27.7 (V+)
unnamed: C163.1, U28.3 (+), VLoad/4.2, VLoad/8.2
unnamed: C165.1, R83.2, U28.6
unnamed: C166.1, FB23.2, U28.7 (V+)
unnamed: R15.1, U27.3 (+)
unnamed: U5.7 (R2_out), U5.8 (R1_out)

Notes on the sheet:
FILM
AD8278 Difference Amp in divide by 2 config
LT5400 divides by 4
AD8417 has a Gain of 60
FILM
Total Division Ratio is 8. Max Input Voltage is around 17 V, so output is scaled to 2.125 VMax, which is within ADC reference voltage of 2.5V

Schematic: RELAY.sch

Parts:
C28: 560uF; CP_Radial_D10.0mm_P5.00mm
C95: 47uF; T495X476K035ATE300
C102: .1uF; C_0603_1608Metric_Pad1.05x0.95mm_HandSolder
C103, C112: 1uF; C_0805_2012Metric_Pad1.15x1.40mm_HandSolder
C110: 1000uF; CP_Radial_D12.5mm_P5.00mm
D1, D3: 1N5819; SOD123
D4: 1N4148; SOD123
D12: 1N4148W; SOD123
D13: LED GRN; LED_0805_2012Metric_Pad1.15x1.40mm_HandSolder
D15: LED GREEN; LED_0805_2012Metric_Pad1.15x1.40mm_HandSolder
D17: LED RED; LED_0805_2012Metric_Pad1.15x1.40mm_HandSolder
JP1, JP2, JP3, JP4: Jumper_NO; SolderJumper-2_P1.3mm_Open_RoundedPad1.0x1.5mm
K1: DSP1-L2-DC5V; Panasonic_DSP1-L2-DC5V-F
Q3: BCM856DS; SOT-23-6_Handsoldering
Q4, Q7: MMBT2222A; SOT-23_Handsoldering
Q5: DMG6602
Q6: IRML6401; SOT-23_Handsoldering
R30, R32, R33: 50KΩ; R_0603_1608Metric_Pad1.05x0.95mm_HandSolder
R82: 750Ω; R_0603_1608Metric_Pad1.05x0.95mm_HandSolder
R85, R86: 500Ω; R_0402_1005Metric
R87, R98, R99: 1KΩ; R_0402_1005Metric
R96, R97: 47KΩ; R_0603_1608Metric_Pad1.05x0.95mm_HandSolder

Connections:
+5V: Q3.1 (E), Q6.3 (D); also elsewhere on the board
+5V_RELAY_PS: C110.1, D4.1 (K), D12.1 (K), D15.2 (A), K1.1, K1.2, Q3.4 (E), Q6.2 (S)
+12V_REG: D1.2 (A), K1.8, K1.9, R30.1, R32.1; also elsewhere on the board
/Power_Input/Power_Measure/RELAY_ON: C95.1, C102.1, C103.1, D13.2 (A), K1.5; also elsewhere on the board
/Power_Input/RELAY/COOLER_OFF: C112.1, D17.2 (A), K1.12
COIL_A: D4.2 (A), JP1.1, JP1.2, JP2.1, JP3.1, K1.16, Q4.3 (C)
COIL_B: D12.2 (A), JP2.2, JP3.2, JP4.1, JP4.2, K1.15, Q7.3 (C)
GND: C95.2, C102.2, C103.2, C112.2, R87.2, R99.2; also elsewhere on the board
GNDA: C28.2, C110.2, Q4.2 (E), Q5.5 (S), Q7.2 (E), R33.2, R96.2, R97.2, R98.2; also elsewhere on the board
unnamed: C28.1, D1.1 (K), Q5.2 (S), R30.2
unnamed: D3.1 (K), R82.2
unnamed: D3.2 (A), Q5.1 (G), Q5.4 (D), R33.1
unnamed: D13.1 (K), R87.1
unnamed: D15.1 (K), R98.1
unnamed: D17.1 (K), R99.1
unnamed: Q3.2 (B), Q3.5 (B), Q3.6 (C), R96.1
unnamed: Q3.3 (C), Q6.1 (G), R97.1
unnamed: Q4.1 (B), R82.1, R85.2
unnamed: Q5.3 (G), Q5.6 (D), R32.2
unnamed: Q7.1 (B), R86.1
RELAY_RESET: R86.2; also elsewhere on the board
RELAY_SET: R85.1; also elsewhere on the board

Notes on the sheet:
nominal coil current is 60 mA
RELAY_OFF
Automatically shuts off relay at power off
Supply for relay reset circuit
IDEAL DIODE (SUPPLY TO TURN OFF RELAY)
RELAY_ON
RELAY OFF INDICATOR
ON INDICATOR

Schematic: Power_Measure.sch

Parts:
C99, C115: .1uF; C_0603_1608Metric_Pad1.05x0.95mm_HandSolder
C100, C101, C107, C214: 10uF; C_1206_3216Metric_Pad1.42x1.75mm_HandSolder
C128, C174, C175, C176, C179: 1uF; C_0805_2012Metric_Pad1.15x1.40mm_HandSolder
C136: 47uF; T495X476K035ATE300
C139, C150: 100uF; C_1210_3225Metric_Pad1.42x2.65mm_HandSolder
C169: 3.3uF; C_Rect_L7.2mm_W5.5mm_P5.00mm_FKS2_FKP2_MKS2_MKP2
C170: 1uF; C_1210_3225Metric_Pad1.42x2.65mm_HandSolder
C171, C172, C173: 0.1uF; C_0603_1608Metric_Pad1.05x0.95mm_HandSolder
C177: 1000pF; C_0402_1005Metric
C180: 4.7uF; CP_EIA-3528-21_Kemet-B_Pad1.50x2.35mm_HandSolder
D5: LED_GRN; LED_0805_2012Metric_Pad1.15x1.40mm_HandSolder
FB24: FB; R_0805_2012Metric_Pad1.15x1.40mm_HandSolder
FB25, FB28: Ferrite; R_0805_2012Metric_Pad1.15x1.40mm_HandSolder
FB30: ferrite; R_0805_2012Metric_Pad1.15x1.40mm_HandSolder
FB31: FB; L_0603_1608Metric_Pad1.05x0.95mm_HandSolder
FB32: ferrite; L_1210_3225Metric_Pad1.42x2.65mm_HandSolder
R20: 500; R_0603_1608Metric_Pad1.05x0.95mm_HandSolder
R94: 56 mΩ; R_1206_3216Metric_Pad1.42x1.75mm_HandSolder
R106: 1M; R_0603_1608Metric_Pad1.05x0.95mm_HandSolder
R108: 4.7k; R_0402_1005Metric
R117: 1.87k; R_0603_1608Metric_Pad1.05x0.95mm_HandSolder
R119: 100R; R_0603_1608Metric_Pad1.05x0.95mm_HandSolder
R120: 1M; C_0603_1608Metric_Pad1.05x0.95mm_HandSolder
R129: .1R; R_0603_1608Metric_Pad1.05x0.95mm_HandSolder
SCALE1: 500R; Potentiometer_Bourns_3214W_Vertical
TP44: -5V; TestPoint_SMT_Keystone_5190
TP45: Current_SNS; TestPoint_SMT_Keystone_5190
TP46: AD637_RMS; TestPoint_SMT_Keystone_5190
TP47: RMS_FILT; TestPoint_SMT_Keystone_5190
U8: AD8417; SOIC-8_3.9x4.9mm_P1.27mm
U21: AD8628; SOIC-8_3.9x4.9mm_P1.27mm
U23: LT1054L; SOIC-8_5.275x5.275mm_P1.27mm
U24: AD637; SOIC-16W_7.5x10.3mm_P1.27mm
ZERO1: 50K POT; Potentiometer_Bourns_3214W_Vertical

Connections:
+5V: FB24.1, FB25.1, FB28.1, FB31.1, R108.2, ZERO1.1; also elsewhere on the board
-5V: C179.1, C180.1, C214.1, D5.1 (K), FB30.1, R129.1, TP44.1, ZERO1.3
/Power_Input/Power_Measure/RELAY_ON: R94.2, U8.8 (+); also elsewhere on the board
/Power_Input/Power_Measure/RMS_OUT: C169.1, C170.1, R117.2, SCALE1.1, SCALE1.2, TP46.1, U24.11 (RMS_OUT)
COOLER_PWR: R94.1, U8.1 (-); also elsewhere on the board
COOL_PWR_I: R119.1, U21.2 (-); also elsewhere on the board
Current_Sns_Amp: TP45.1, U8.5, U24.15 (VIN)
GNDA: C99.2, C100.2, C101.2, C107.2, C115.2, C128.2, C136.2, C150.2, C172.2, C173.2, C174.2, C175.2, C176.2, C177.2, C179.2, C180.2, C214.2, R20.2, R120.2, U8.2 (GND), U8.3 (REF2), U8.4 (GND), U8.7 (REF1), U21.4 (V-), U23.3 (GND), U24.1 (BUF_IN), U24.3 (COM); also elsewhere on the board
unnamed: C99.1, FB24.2, U8.6 (V+)
unnamed: C100.1, C101.1, C107.1, C176.1, R117.1, R120.1, TP47.1, U21.3 (+)
unnamed: C115.1, FB25.2, U21.7 (V+)
unnamed: C128.1, C136.1, FB31.2, U23.8 (V+)
unnamed: C139.1, U23.2 (CAP+)
unnamed: C139.2, U23.4 (CAP-)
unnamed: C150.1, FB32.1, U23.5 (-VOUT)
unnamed: C169.2, C170.2, U24.10 (C_AVG)
unnamed: C171.1, C172.1, C174.1, FB28.2, U24.13 (+VS)
unnamed: C171.2, C173.1, C175.1, FB30.2, U24.12 (-VS)
unnamed: C177.1, R106.2, ZERO1.2
unnamed: D5.2 (A), R20.1
unnamed: FB32.2, R129.2
unnamed: R106.1, U24.4 (OFFSET)
unnamed: R108.1, U24.5 (CS)
unnamed: R119.2, U21.6
unnamed: SCALE1.3, U24.6 (DENOM)

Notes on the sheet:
TO ADS1256
RMS CURRENT
AD8628 is low noise, low offset autozero amp to provide low impedance source to ADC
20-25 turn trim pot
FILM

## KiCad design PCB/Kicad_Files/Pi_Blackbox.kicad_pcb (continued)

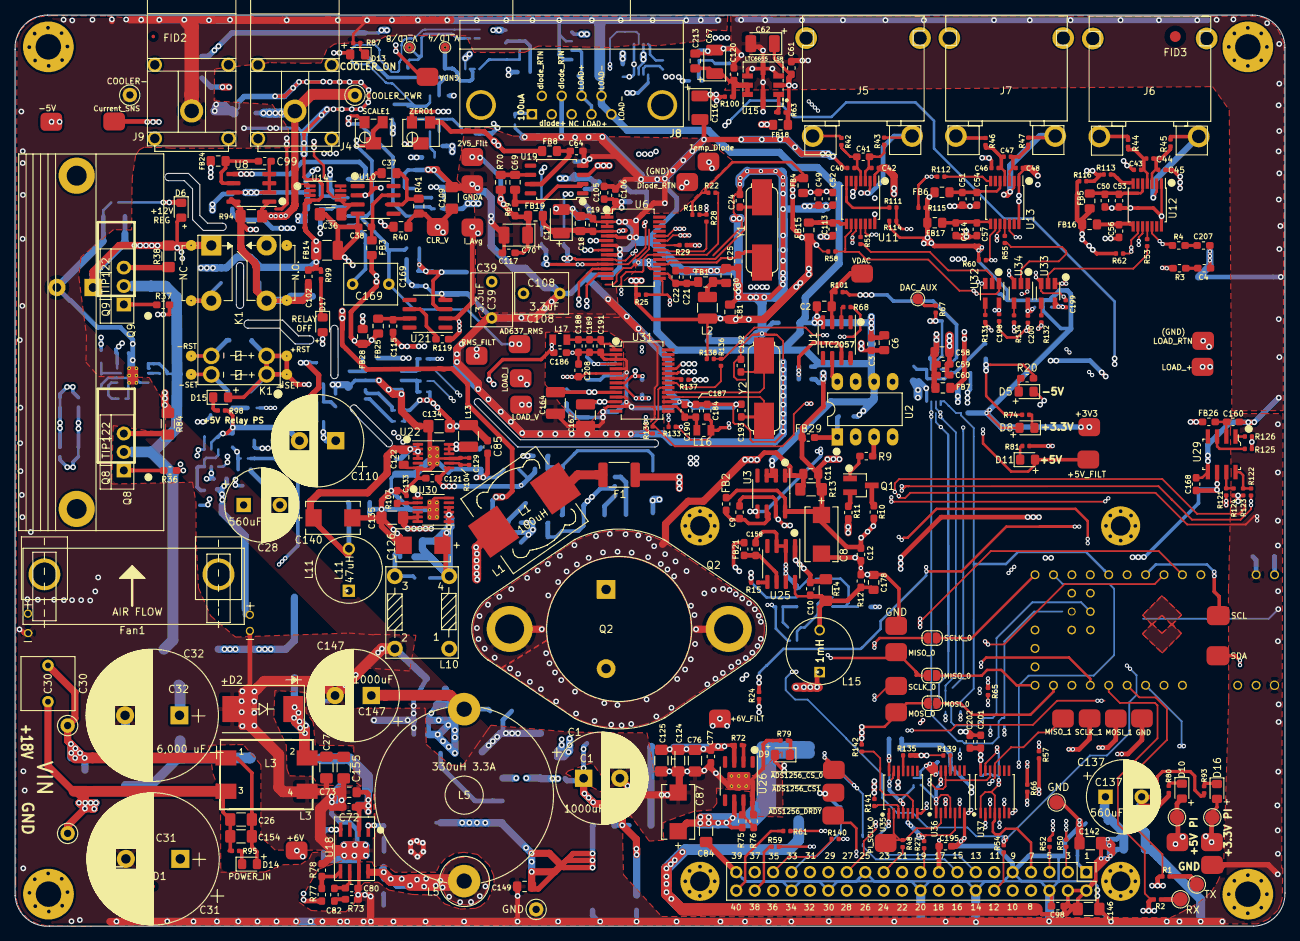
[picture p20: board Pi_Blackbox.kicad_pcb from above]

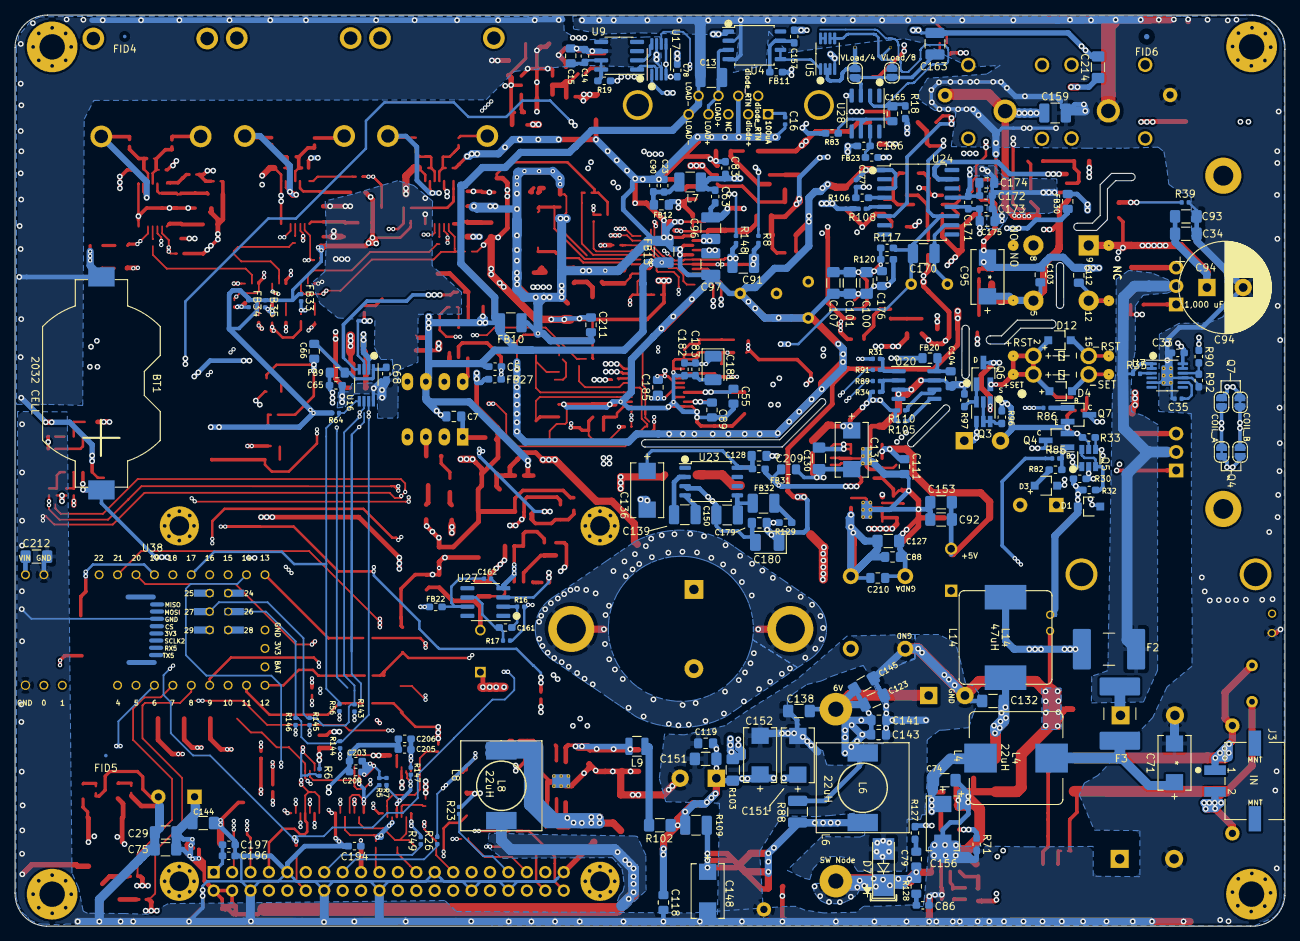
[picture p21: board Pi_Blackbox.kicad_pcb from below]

Board: 6 copper layers, 175.1 x 125.6 mm, 569 parts (201 on the bottom side), 276 nets.

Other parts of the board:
C151#2: 4.7uF; C_1206_3216Metric_Pad1.42x1.75mm_HandSolder
C212: 10uF; C_1206_3216Metric_Pad1.42x1.75mm_HandSolder
JP5: MOSI_0; SolderJumper-2_P1.3mm_Open_RoundedPad1.0x1.5mm
JP6: MISO_0; SolderJumper-2_P1.3mm_Open_RoundedPad1.0x1.5mm
JP7: SCLK_0; SolderJumper-2_P1.3mm_Open_RoundedPad1.0x1.5mm
U38: Teensy4.0_min_pads; Teensy40_most_pads_small_holes

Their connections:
+6V: C151#2.1; also elsewhere on the board
ADS1256_MISO: JP6.1; also elsewhere on the board
ADS1256_MOSI: JP5.1; also elsewhere on the board
ADS1256_SCLK: JP7.1; also elsewhere on the board
DAC8552_CS: U38.17; also elsewhere on the board
DAC_MOSI: U38.26; also elsewhere on the board
DAC_SCLK: U38.27; also elsewhere on the board
GND: C151#2.2, C212.2, U38.GND; also elsewhere on the board
MAX31856_CS_1: U38.4; also elsewhere on the board
MAX31856_CS_2: U38.5; also elsewhere on the board
MAX31856_CS_3: U38.20; also elsewhere on the board
MAX31856_DRDY_1: U38.21; also elsewhere on the board
MAX31856_DRDY_2: U38.28; also elsewhere on the board
MAX31856_DRDY_3: U38.29; also elsewhere on the board
MAX31856_MISO: U38.1; also elsewhere on the board
unnamed: JP5.2, U38.11
unnamed: JP6.2, U38.12
unnamed: JP7.2, U38.13
PI_+5V: C212.1, U38.VIN; also elsewhere on the board
PI_SCL: U38.19; also elsewhere on the board
PI_SDA: U38.18; also elsewhere on the board
PI_UART_RX: U38.8; also elsewhere on the board
PI_UART_TX: U38.7; also elsewhere on the board
VBat: U38.VBAT; also elsewhere on the board
~ADS1256_CS_0: U38.10; also elsewhere on the board
~ADS1256_CS_1: U38.0; also elsewhere on the board
~ADS1256_RESET: U38.22; also elsewhere on the board
~ADS1265_DRDY: U38.6; also elsewhere on the board
~ADS1265_DRDY2: U38.9; also elsewhere on the board
~BUF_EN_0: U38.14; also elsewhere on the board
~BUF_EN_1: U38.15; also elsewhere on the board
~BUF_EN_2: U38.16; also elsewhere on the board

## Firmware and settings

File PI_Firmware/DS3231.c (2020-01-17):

#include <bcm2835.h>
#include <stdio.h>
#include <unistd.h>
#include <time.h>
#include <stdlib.h>
#include <string.h>
#include <ctype.h>
#include <stdbool.h>



#define ADDR_SECONDS      0x00
#define ADDR_MINUTES      0x01
#define ADDR_HOURS        0x02
#define ADDR_DAY_OF_WEEK  0x03
#define ADDR_DAY_OF_MONTH 0x04
#define ADDR_MONTH        0x05
#define ADDR_YEAR         0x06

#define INDEX_START_ADDR        0x00
#define WRITE_INDEX_SECONDS       1
#define WRITE_INDEX_MINUTES       2
#define WRITE_INDEX_HOURS         3
#define WRITE_INDEX_DAY_OF_WEEK   4
#define WRITE_INDEX_DAY_OF_MONTH  5
#define WRITE_INDEX_MONTH         6
#define WRITE_INDEX_YEAR          7

#define READ_INDEX_SECONDS       0
#define READ_INDEX_MINUTES       1
#define READ_INDEX_HOURS         2
#define READ_INDEX_DAY_OF_WEEK   3
#define READ_INDEX_DAY_OF_MONTH  4
#define READ_INDEX_MONTH         5
#define READ_INDEX_YEAR          6


#define MASK_SECONDS      0x7F
#define MASK_MINUTES      0x7F
#define MASK_HOURS        0x3F
#define MASK_DAY_OF_WEEK  0x07
#define MASK_DAY_OF_MONTH 0x3F
#define MASK_MONTH        0x1F


#define DS3231_ADDRESS        0x68  ///< I2C address for DS3231
#define DS3231_CONTROL        0x0E  ///< Control register
#define DS3231_STATUS_REG     0x0F  ///< Status register
#define DS3231_TEMP_REG	      0x11  ///< Temperature register (high byte - low byte is at 0x12), 10-bit temperature value

#define SECONDS_PER_DAY       86400  ///< 60 * 60 * 24
#define SECONDS_1970_TO_2000  946684800  ///< Unixtime for 2000-01-01 00:00:00, useful for initialization




#	define DS3231_BIT_BBSQW		0x40 /* same as BBSQI */
/* RTC registers don't differ much, except for the century flag */
#define DS1307_REG_SECS		0x00	/* 00-59 */
#	define DS1307_BIT_CH		0x80
#	define DS1340_BIT_nEOSC		0x80
#	define MCP7941X_BIT_ST		0x80
#define DS1307_REG_MIN		0x01	/* 00-59 */
#define DS1307_REG_HOUR		0x02	/* 00-23, or 1-12{am,pm} */
#	define DS1307_BIT_12HR		0x40	/* in REG_HOUR */
#	define DS1307_BIT_PM		0x20	/* in REG_HOUR */
#	define DS1340_BIT_CENTURY_EN	0x80	/* in REG_HOUR */
#	define DS1340_BIT_CENTURY	0x40	/* in REG_HOUR */
#define DS1307_REG_WDAY		0x03	/* 01-07 */
#	define MCP7941X_BIT_VBATEN	0x08
#define DS1307_REG_MDAY		0x04	/* 01-31 */
#define DS1307_REG_MONTH	0x05	/* 01-12 */
#	define DS1337_BIT_CENTURY	0x80	/* in REG_MONTH */
#define DS1307_REG_YEAR		0x06	/* 00-99 */


/*
class RTC_DS1307 {
public:
  bool begin(void);
  static void adjust(const DateTime& dt);
  uint8_t isrunning(void);
  static DateTime now();

};

*/

/**
  Number of days in each month, from January to November. December is not
  needed. Omitting it avoids an incompatibility with Paul Stoffregen's Time
  library. C.f. https://github.com/adafruit/RTClib/issues/114
//*/
const uint8_t daysInMonth [] = { 31,28,31,30,31,30,31,31,30,31,30 };


/*!
    @brief  Given a date, return number of days since 2000/01/01, valid for 2001..2099
    @param y Year
    @param m Month
    @param d Day
    @return Number of days
*/
/**************************************************************************/
/*
static uint16_t date2days(uint16_t y, uint8_t m, uint8_t d) {
    if (y >= 2000)
        y -= 2000;
    uint16_t days = d;
    for (uint8_t i = 1; i < m; ++i)
        days += pgm_read_byte(daysInMonth + i - 1);
    if (m > 2 && y % 4 == 0)
        ++days;
    return days + 365 * y + (y + 3) / 4 - 1;
}
*/

/**************************************************************************/
/*!
    @brief  Given a number of days, hours, minutes, and seconds, return the total seconds
    @param days Days
    @param h Hours
    @param m Minutes
    @param s Seconds
    @return Number of seconds total
*/
/**************************************************************************/
static long time2long(uint16_t days, uint8_t h, uint8_t m, uint8_t s) {
    return ((days * 24L + h) * 60 + m) * 60 + s;
}



/**************************************************************************/
/*!
    @brief  DateTime constructor from unixtime
    @param t Initial time in seconds since Jan 1, 1970 (Unix time)
*/
/**************************************************************************/

/*
DateTime::DateTime (uint32_t t) {
  t -= SECONDS_FROM_1970_TO_2000;    // bring to 2000 timestamp from 1970

  ss = t % 60;
  t /= 60;
  mm = t % 60;
  t /= 60;
  hh = t % 24;
  uint16_t days = t / 24;
  uint8_t leap;
  for (yOff = 0; ; ++yOff) {
    leap = yOff % 4 == 0;
    if (days < 365 + leap)
      break;
    days -= 365 + leap;
  }
  for (m = 1; m < 12; ++m) {
    uint8_t daysPerMonth = pgm_read_byte(daysInMonth + m - 1);
    if (leap && m == 2)
      ++daysPerMonth;
    if (days < daysPerMonth)
      break;
    days -= daysPerMonth;
  }
  d = days + 1;
}
*/
/**************************************************************************/
/*!
    @brief  DateTime constructor from Y-M-D H:M:S
    @param year Year, 2 or 4 digits (year 2000 or higher)
    @param month Month 1-12
    @param day Day 1-31
    @param hour 0-23
    @param min 0-59
    @param sec 0-59
*/
/**************************************************************************/

/*
DateTime::DateTime (uint16_t year, uint8_t month, uint8_t day, uint8_t hour, uint8_t min, uint8_t sec) {
    if (year >= 2000)
        year -= 2000;
    yOff = year;
    m = month;
    d = day;
    hh = hour;
    mm = min;
    ss = sec;
}
*/

/**************************************************************************/
/*!
    @brief  DateTime copy constructor using a member initializer list
    @param copy DateTime object to copy
*/
/**************************************************************************/

/*
DateTime::DateTime (const DateTime& copy):
  yOff(copy.yOff),
  m(copy.m),
  d(copy.d),
  hh(copy.hh),
  mm(copy.mm),
  ss(copy.ss)
{}


  uint8_t DateTime::dayOfTheWeek() const {
    uint16_t day = date2days(yOff, m, d);
    return (day + 6) % 7; // Jan 1, 2000 is a Saturday, i.e. returns 6
}
*/

/**************************************************************************/
/*!
    @brief  Return unix time, seconds since Jan 1, 1970.
    @return Number of seconds since Jan 1, 1970
*/
/**************************************************************************/
/*
uint32_t DateTime::unixtime(void) const {
  uint32_t t;
  uint16_t days = date2days(yOff, m, d);
  t = time2long(days, hh, mm, ss);
  t += SECONDS_FROM_1970_TO_2000;  // seconds from 1970 to 2000

  return t;
}

*/
/**************************************************************************/
/*!
    @brief  Check the status register Oscillator Stop Flag to see if the DS3231 stopped due to power loss
    @return True if the bit is set (oscillator stopped) or false if it is running
*/
/**************************************************************************/
/*
bool RTC_DS3231::lostPower(void) {
  return (read_i2c_register(DS3231_ADDRESS, DS3231_STATUSREG) >> 7);
}
*/

/**************************************************************************/
/*!
    @brief  Set the date and flip the Oscillator Stop Flag
    @param dt DateTime object containing the date/time to set
*/
/**************************************************************************/
/*
void RTC_DS3231::adjust(const DateTime& dt) {
  Wire.beginTransmission(DS3231_ADDRESS);
  Wire._I2C_WRITE((byte)0); // start at location 0
  Wire._I2C_WRITE(bin2bcd(dt.second()));
  Wire._I2C_WRITE(bin2bcd(dt.minute()));
  Wire._I2C_WRITE(bin2bcd(dt.hour()));
  Wire._I2C_WRITE(bin2bcd(0));
  Wire._I2C_WRITE(bin2bcd(dt.day()));
  Wire._I2C_WRITE(bin2bcd(dt.month()));
  Wire._I2C_WRITE(bin2bcd(dt.year() - 2000));
  Wire.endTransmission();

  uint8_t statreg = read_i2c_register(DS3231_ADDRESS, DS3231_STATUSREG);
  statreg &= ~0x80; // flip OSF bit
  write_i2c_register(DS3231_ADDRESS, DS3231_STATUSREG, statreg);
}
*/

/**************************************************************************/
/*!
    @brief  Get the current date/time
    @return DateTime object with the current date/time
*/
/**************************************************************************/
/*
DateTime RTC_DS3231::now() {
  Wire.beginTransmission(DS3231_ADDRESS);
  Wire._I2C_WRITE((byte)0);
  Wire.endTransmission();

  Wire.requestFrom(DS3231_ADDRESS, 7);
  uint8_t ss = bcd2bin(Wire._I2C_READ() & 0x7F);
  uint8_t mm = bcd2bin(Wire._I2C_READ());
  uint8_t hh = bcd2bin(Wire._I2C_READ());
  Wire._I2C_READ();
  uint8_t d = bcd2bin(Wire._I2C_READ());
  uint8_t m = bcd2bin(Wire._I2C_READ());
  uint16_t y = bcd2bin(Wire._I2C_READ()) + 2000;

  return DateTime (y, m, d, hh, mm, ss);
}
*/
/**************************************************************************/
/*!
    @brief  Get the current temperature from the DS3231's temperature sensor
    @return Current temperature (float)
*/
/**************************************************************************/
/*
float RTC_DS3231::getTemperature()
{
  uint8_t msb, lsb;
  Wire.beginTransmission(DS3231_ADDRESS);
  Wire._I2C_WRITE(DS3231_TEMP_REG);
  Wire.endTransmission();

  Wire.requestFrom(DS3231_ADDRESS, 2);
  msb = Wire._I2C_READ();
  lsb = Wire._I2C_READ();

  return (float) msb + (lsb >> 6) * 0.25f;
}
*/
/**************************************************************************/
/*!
    @brief  Convert a binary coded decimal to binary. RTC stores time/date values as BCD.
    @param val BCD value
    @return Binary value
*/
/**************************************************************************/
static uint8_t BCD_To_Decimal (uint8_t bcd)
{
  //  return bcd - 6 * (bcd >> 4);    // gets day of week right
    // return (uint8_t)(10 * ((bcd & 0xF0) >> 4) + (bcd & 0x0F));
    uint8_t msb = bcd;
    return ((msb >> 4) * 10) + (bcd & 0x0F);
}

/**************************************************************************/
/*!
    @brief  Convert a binary value to BCD format for the RTC registers
    @param val Binary value
    @return BCD value
*/
/**************************************************************************/
static uint8_t Decimal_To_BCD(uint8_t dec)
{
//    return dec + 6 * (dec / 10);    // gets day of week right
    //    return (uint8_t)(((dec / 10) << 4) | (dec % 10));
    uint8_t msb = dec;
            return ((msb / 10) << 4) + (dec % 10);
}


struct time_stamp
{
    int month;
    int day;
    int year;
    int hour;
    int minute;
    int second;
};
typedef struct time_stamp Time_Stamp;
Time_Stamp Time_Now;

uint8_t TIME_bytes[8];
char *str[]  ={"SUN", "MON", "TUES", "WED", "THUR", "FRI", "SAT"};

struct tm *time_info;
time_t raw_time_now;
struct timespec current_time;

void DS3231_Set_From_Linux_Time()
{
    char addr_byte[1] = { 0x00 };
    char timestamp_string[300];
    timestamp_string[0] = '\0';

    time( &raw_time_now);
    time_info = localtime(&raw_time_now);


    printf("\t --SET DS3231 FROM LINUX TIME--\n");
    strftime (timestamp_string,50,"%H:%M:%S  %m/%d/%Y ",time_info); // convert time info to string
    //printf("formatted string from get_time: \t%s\n", timestamp_string);
    for(int i=0; i<strlen(timestamp_string); i++)
    {
          if(timestamp_string[i] == '/' || timestamp_string[i] == ':') // remove slashes from date and replace with dashes so compatible with filename
          {	timestamp_string[i] = ' ';	}
    }

    // parse the string into individual integer values
    sscanf(timestamp_string, "%d %d %d  %d %d %d ", &Time_Now.hour, &Time_Now.minute, &Time_Now.second, &Time_Now.month, &Time_Now.day, &Time_Now.year );

    Time_Now.year -= 2000;
    printf("SET before BCD %d:%d:%d %d/%d/%d\t\t(2 digit year)\n", Time_Now.hour, Time_Now.minute, Time_Now.second, Time_Now.month,
            Time_Now.day, Time_Now.year);

    TIME_bytes[INDEX_START_ADDR] = 0x00;
    TIME_bytes[WRITE_INDEX_SECONDS] = Decimal_To_BCD( (uint8_t) Time_Now.second & MASK_SECONDS ) ; //sec
    TIME_bytes[WRITE_INDEX_MINUTES] = Decimal_To_BCD( (uint8_t) Time_Now.minute & MASK_MINUTES );
    TIME_bytes[WRITE_INDEX_HOURS] = Decimal_To_BCD( (uint8_t) Time_Now.hour & MASK_HOURS );
    TIME_bytes[WRITE_INDEX_DAY_OF_WEEK] = 0;
    TIME_bytes[WRITE_INDEX_DAY_OF_MONTH] = Decimal_To_BCD((uint8_t) Time_Now.day & MASK_DAY_OF_MONTH );
    TIME_bytes[WRITE_INDEX_MONTH] = Decimal_To_BCD( (uint8_t) Time_Now.month & MASK_MONTH );
    //TIME_bytes[WRITE_INDEX_YEAR] = Decimal_To_BCD( (uint8_t) Time_Now.year -2000);
    TIME_bytes[WRITE_INDEX_YEAR] = (uint8_t)( Time_Now.year -2000 );


    printf("SET After BCD: %d:%d:%d %d/%d/%d\t\t(two digit year)\n", TIME_bytes[WRITE_INDEX_HOURS], TIME_bytes[WRITE_INDEX_MINUTES], TIME_bytes[WRITE_INDEX_SECONDS], TIME_bytes[WRITE_INDEX_MONTH],
            TIME_bytes[WRITE_INDEX_DAY_OF_MONTH], TIME_bytes[WRITE_INDEX_YEAR]);
    printf("\t --------------\n");
    bcm2835_i2c_write(TIME_bytes, 8);
}

void Read_Linux_Time()
{
    char line[256];
    char addr_byte[1] = { 0x00 };
    int hour, minute, second, month, day, two_digit_year, four_digit_year;

    system("date +\"%H:%M:%S %D\" > /tmp/datefile"); // sends date command to terminal and redirects output to file @ /tmp/datefile
    FILE* file_pointer = fopen("/tmp/datefile", "r");   // opens the fille for reading


    if(fgets(line, 256, file_pointer) != NULL)
    {
        //  printf("scanned line: \t%s\n", line);
          for(int i=0; i<strlen(line); i++)
          {
              if(line[i] == '/' || line[i] == ':') // remove slashes from date and replace with dashes so compatible with filename
              {	line[i] = ' ';	}
          }
          sscanf(line, "%d %d %d %d %d %d ", &hour, &minute, &second, &month, &day, &two_digit_year); // read the file into the variables
    }

    four_digit_year = two_digit_year +2000;

    fclose(file_pointer);
    system("rm /tmp/datefile");  // delete the temporary file

//  printf("\t --LINUX TIME--\n");
    printf("\t --------------\n");
    printf("LINUX READ TIME \t %d:%d:%d %d/%d/%d\n", hour, minute, second, month, day, four_digit_year);

}

void DS3231_Read_Time()
{
    TIME_bytes[INDEX_START_ADDR] = 0x00;
    bcm2835_i2c_write_read_rs(TIME_bytes, 1, TIME_bytes, 7); // writes 0x00 to DS3231 (start address), then reads 7 bytes

    TIME_bytes[READ_INDEX_SECONDS] = TIME_bytes[READ_INDEX_SECONDS] & MASK_SECONDS; //sec
    TIME_bytes[READ_INDEX_MINUTES] = TIME_bytes[READ_INDEX_MINUTES] & MASK_MINUTES; //min
    TIME_bytes[READ_INDEX_HOURS]   = TIME_bytes[READ_INDEX_HOURS ] & MASK_HOURS; //hour
    TIME_bytes[READ_INDEX_DAY_OF_WEEK] = TIME_bytes[READ_INDEX_DAY_OF_WEEK] & MASK_DAY_OF_WEEK; //day of the week
    TIME_bytes[READ_INDEX_DAY_OF_MONTH] = TIME_bytes[READ_INDEX_DAY_OF_MONTH] & MASK_DAY_OF_MONTH; //day of the month
    TIME_bytes[READ_INDEX_MONTH] = TIME_bytes[READ_INDEX_MONTH] & MASK_MONTH; //month
  //  printf("READ After Mask, before BCD conversion %d:%d:%d %d/%d/%d\n", TIME_bytes[READ_INDEX_HOURS], TIME_bytes[READ_INDEX_MINUTES], TIME_bytes[READ_INDEX_SECONDS], TIME_bytes[READ_INDEX_MONTH],
    //        TIME_bytes[READ_INDEX_DAY_OF_MONTH], TIME_bytes[READ_INDEX_YEAR]);

    TIME_bytes[READ_INDEX_SECONDS] = BCD_To_Decimal( TIME_bytes[READ_INDEX_SECONDS] ); //sec
    TIME_bytes[READ_INDEX_MINUTES] = BCD_To_Decimal( TIME_bytes[READ_INDEX_MINUTES] ); //min
    TIME_bytes[READ_INDEX_HOURS]   = BCD_To_Decimal( TIME_bytes[READ_INDEX_HOURS ] ); //hour
    TIME_bytes[READ_INDEX_DAY_OF_WEEK] = BCD_To_Decimal( TIME_bytes[READ_INDEX_DAY_OF_WEEK] ); //day of the week
    TIME_bytes[READ_INDEX_DAY_OF_MONTH] = BCD_To_Decimal( TIME_bytes[READ_INDEX_DAY_OF_MONTH] ); //day of the month
    TIME_bytes[READ_INDEX_MONTH] = BCD_To_Decimal( TIME_bytes[READ_INDEX_MONTH] ); //month
    TIME_bytes[READ_INDEX_YEAR] = TIME_bytes[READ_INDEX_YEAR] +2000; //year



    //printf("READ After BCD conversion \t\t%s  ", str[(uint8_t)TIME_bytes[INDEX_DAY_OF_WEEK]-1]);
//    printf("READ After BCD conversion \t\t%s  \t", str[TIME_bytes[READ_INDEX_DAY_OF_WEEK]]);
    printf("DS3231 READ TIME \t %d:%d:%d  %d/%d/%d\n", TIME_bytes[READ_INDEX_HOURS], TIME_bytes[READ_INDEX_MINUTES], TIME_bytes[READ_INDEX_SECONDS], TIME_bytes[READ_INDEX_MONTH],
            TIME_bytes[READ_INDEX_DAY_OF_MONTH], TIME_bytes[READ_INDEX_YEAR]+2000);
    printf("\t ------------------\n");
}

int main(int argc, char **argv)
{
    if (!bcm2835_init())return 1;
    bcm2835_i2c_begin();
    bcm2835_i2c_setSlaveAddress(DS3231_ADDRESS);
    bcm2835_i2c_set_baudrate(10000);
    printf(" DS3231 start..........\n");

    //DS3231_Set_Time();
    while(1)
    {

        Read_Linux_Time();
        DS3231_Read_Time();

      //  DS3231_Set_From_Linux_Time();
    //    DS3231_Read_Time();

        bcm2835_delay(1000);
    }

    bcm2835_i2c_end();
    bcm2835_close();

    return 0;
}

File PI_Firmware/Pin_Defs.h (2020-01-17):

#include <bcm2835.h>

#ifndef _PIN_DEFINITIONS_
#define _PIN_DEFINITIONS_

// Pin Numbering
/*
Rasperry Pi Physical Pin Numbering w/ bcm2835 library pin Numbering
            BCM2835           Raspberry Pi
Function     pin#             physical pin#
SDA1          2                   3       INA233_I2C
SCL1          3                   5       INA233_I2C
GPCLK0        4                   7                         OPEN
GPCLK1        5                   29      MAX31856_DRDY1
GPCLK2        6                   31      SW_CTRL_100uA                  
SPI0_CE1_N    7                   26      MAX31856_CS3
SPI0_CE0_N    8                   24      MAX31856_CS2
SPI0_MISO     9                   21      ADS1256_MISO
SPI0_MOSI     10                  19      ADS1256 MOSI
SPI0_SCLK     11                  23      ADS1256_SCLK
PWM0          12                  32      RELAY_RESET
PWM1          13                  33                        OPEN
TXD0          14                  8       CCC_UART_TX
RXD0          15                  10      CCC_UART_RX
SPI1_CE2      16                  36      MAX31856_DRDY2
SPI1_CE1      17                  11      ADS1256_DRDY
PCM_CLK       18                  12      ADS1256_RESET
SPI1_MISO     19                  35      RESERVED_SPI1
SPI1_MOSI     20                  38      RESERVED_SPI1
SPI1_SCLK     21                  40      RESERVED_SPI1
SD0_CLK       22                  15      ADS1256_CS
SD0_CMD       23                  16      DAC8532_CS
SD0_DAT0      24                  18                        OPEN
SD0_DAT1      25                  22      MAX31856_CS1
SD0_DAT2      26                  37      MAX31856_DRDY3
SD0_DAT3      27                  13      ADS1256_SYNC
              01                  28      RELAY_SET
*/


#define ADS1256_DRDY  17            // physical pin 11
#define ADS1256_RST  18             // physical pin 12
#define ADS1256_CS  22              // Physical pin 15
#define	DAC8532_CS	RPI_GPIO_P1_16	// Physical pin 16
#define MAX31856_CHIP_SELECT_1   25
#define MAX31856_CHIP_SELECT_2   8
#define MAX31856_CHIP_SELECT_3   7
#define MAX31856_DRDY_1   5
#define MAX31856_DRDY_2   16
#define MAX31856_DRDY_3   26


static const uint8_t INA233_HEAT_LOAD_ADDR = 0x45;
//static const uint8_t INA233_CCC_ADDR = 0x40;

#endif

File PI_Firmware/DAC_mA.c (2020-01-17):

#include <math.h>
#include <bcm2835.h>
#include <stdio.h>
#include <stdbool.h>
#include <unistd.h>
#include <string.h>

#include <errno.h>
#include "mA_Cal.h"

#define ONE_MILLISECOND 1000
#define	CS	RPI_GPIO_P1_16	//P4
#define CS_HIGH() bcm2835_gpio_write(CS,HIGH)
#define CS_LOW()  bcm2835_gpio_write(CS,LOW)

static const uint8_t channel_A = 0x30;
static const uint8_t channel_B = 0x34;
static const float VREF = 5.0;

static const float V_FULL_SCALE = 5.0455;		// REQUIRE MEASUREMENT
static const float V_OFFSET = .00146;			// REQUIRE MEASUREMENT

static const int DAC_MAX_COUNT = 65536; // 2^16
double IDEAL_VOLT_QUANTA;
double ACTUAL_VOLT_QUANTA;

void  DelayMicroseconds(uint64_t micros);
void Write_DAC(uint8_t channel, uint16_t Data);
uint16_t Volts_to_Counts(float volts);
int Count_Adjust(int counts);

char Get_Input_Method_From_Serial()
{
    printf("\nEnter:\n\t'i' for milliAmps\t\t'w' for milliWatts	");
    printf("\n>> ");

    int ascii;
    char ch;
    int valid_selection = 0;

    while(!valid_selection)
    {
	        ch = getchar();
          if( ch == 'i' || ch == 'w' || ch == 'v')
          {
		             printf("received: %c\n", ch);
                 valid_selection = 1;
                 break;
          }
    }
    return ch;
}

double Get_mA_Setpoint_From_Serial()
{
    printf("Enter mA Setpoint> ");
		double mA;
		scanf("%lf", &mA);

	  printf("setting to: %f mA\n", mA);

    return mA;
}

int Get_mW_Setpoint_From_Serial()
{
    printf("Enter mW Setpoint> ");
		double mW;
		scanf("%lf", &mW);

	printf("setting to: %f mW\n", mW);

    return mW;
}

void DAC_Set_Count(uint8_t channel, uint16_t Counts)
{
	uint8_t byte[3];	// container for bytes to send
	byte[0] = channel;	// first byte is the DAC channel to set (A or B)
	byte[1] = (Counts>>8);	// send MSB byte first by shifting to right 8 bits, and storing result in 8 bit variable
	byte[2] = (Counts&0x00FF); // sending LSB by AND-ing counts with 0x00FF, which clears the MSB, then store result in 8 bit variable
//printf("Corr1: %f\n", (Counts*72.0*ACTUAL_VOLT_QUANTA)/12970);
	//printf("Should be approximately %f V \n", 1.0003*(Counts*ACTUAL_VOLT_QUANTA+V_OFFSET + (Counts*72*ACTUAL_VOLT_QUANTA)/12940));
 CS_LOW() ;
      bcm2835_spi_transfer(byte[0]);
      bcm2835_spi_transfer(byte[1]);
      bcm2835_spi_transfer(byte[2]);
 CS_HIGH() ;
}

void  DelayMicroseconds(uint64_t micros)
{
	bcm2835_delayMicroseconds (micros);
}

void SPI_Init(void)
{
    bcm2835_spi_begin();
    bcm2835_spi_setBitOrder(BCM2835_SPI_BIT_ORDER_MSBFIRST);   	// Set SPI bus to send the most significant bit first
    bcm2835_spi_setDataMode(BCM2835_SPI_MODE1);                	// set clock polarity and idle state
    bcm2835_spi_setClockDivider(BCM2835_SPI_CLOCK_DIVIDER_256);	// set clock speed
    bcm2835_gpio_fsel(CS, BCM2835_GPIO_FSEL_OUTP);		// declare chip select pin as an output
    bcm2835_gpio_write(CS, HIGH); 				// write chip select high (should always be high unless sending data)
}

uint16_t Volts_to_Counts(float volts)
{
	uint16_t counts;
	double offset_volts = volts - V_OFFSET;
  if( offset_volts < 0) offset_volts = 0;
	counts = (uint16_t)(DAC_MAX_COUNT * offset_volts / V_FULL_SCALE);
	int corrected_counts = Count_Adjust(counts);
   	//printf("Converted %f V to %d counts\n", volts, corrected_counts);

	return corrected_counts;
}

int Count_Adjust(int counts)
{
	double factor  = counts/12970.0;
	int adjust = (int)(factor*72);
	int adjusted_counts = counts-adjust;
	return adjusted_counts;
}


int  main()
{
  IDEAL_VOLT_QUANTA = VREF/((double)DAC_MAX_COUNT);
  ACTUAL_VOLT_QUANTA = (V_FULL_SCALE-V_OFFSET)/((double)DAC_MAX_COUNT);
  uint16_t   i,tmp;
  if (!bcm2835_init())
     return 1;

	SPI_Init();
			printf("\t\t\tDAC8552 PROGRAMMABLE Current Source");
			printf("\n\t\t\tVolt Quanta(LSB size): %.7f\t ", IDEAL_VOLT_QUANTA);
			printf("\t( %f uV )\n", IDEAL_VOLT_QUANTA*1e6);
		while(1)
		{

			      char selection = Get_Input_Method_From_Serial();
			      if(selection == 'w')
			      {
			          double MW = Get_mW_Setpoint_From_Serial();
                printf("mw: %f\n", MW);
                if(MW == 0)
                {
                    DAC_Set_Count(channel_A,0);
                }
                else
                {
                  double MA = mW_Setting_to_mA(MW);
                  double volts = Calc_mA_to_Volt(MA);
                  uint16_t counts = Volts_to_Counts(volts);
                  delayMicroseconds(200*ONE_MILLISECOND);
  			          DAC_Set_Count(channel_A,counts+1);
                }

			      }
			      else if(selection == 'i')
			      {
			        double MA = Get_mA_Setpoint_From_Serial();
              if(MA == 0) DAC_Set_Count(channel_A,0);
              else{
                DAC_Set_Count(channel_A,0);
                double volts = Calc_mA_to_Volt(MA);
                printf("Vset:\t %f\n", volts);
                uint16_t counts = Volts_to_Counts(volts);
                delayMicroseconds(200*ONE_MILLISECOND);
                DAC_Set_Count(channel_A,counts);
              }
            }
            else if(selection == 'v')
            {
                printf("yobble\n");
                double MA = Get_mA_Setpoint_From_Serial();
                if(MA == 0) DAC_Set_Count(channel_A,0);
                else{
                  DAC_Set_Count(channel_A,0);
                  double volts = MA;
                  printf("Vset:\t %f\n", volts);
                  uint16_t counts = Volts_to_Counts(volts);
                  delayMicroseconds(200*ONE_MILLISECOND);
                  DAC_Set_Count(channel_A,counts);
                }
            

			      }

			      DelayMicroseconds(1e4);

		}
    bcm2835_spi_end();
    bcm2835_close();

    return 0;
}

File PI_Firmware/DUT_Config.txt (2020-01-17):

#####   CONFIG FILE  #####
Blackbox_ID:    BB106
Displacer_ID:   L163
CCC_ID:         CCC213
Compressor_ID:  073
Dewar_ID:       M00013
Profile_ID:     LoadLine2

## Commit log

2020-01-17 initial commit of socket code
2020-01-17 new files added
    [DUT_Config.txt]
2020-01-17 added board files
    [ADS1256.sch, ADS1256_2.sch, Current_Measure.sch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]
2020-01-17 added pcb files
2020-01-17 added pcb folder
2020-01-17 removed redundant folder
    [PI_Blackbox_BOM_by_Component.xlsx, PI_Blackbox_BOM_by_REF_DES.xlsx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]

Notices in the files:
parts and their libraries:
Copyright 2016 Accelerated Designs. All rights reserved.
